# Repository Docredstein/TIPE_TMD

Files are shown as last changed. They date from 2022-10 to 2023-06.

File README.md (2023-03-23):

# TIPE_TMD
TIPE TMD 2022-2023
Ici se trouve le repo de notre TIPE ayant pour thème la ville, si vous êtes aussi en prépa libre à vous de vous inspirer, En cas de besoin vous pouvez envoyer un mail à
mateis. frambourt @laposte.net (sans les espaces) et je ferais de mon mieux pour vous aider. 
preview_hd











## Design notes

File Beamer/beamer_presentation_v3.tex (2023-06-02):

\documentclass{beamer}
\usetheme{Madrid}
\usecolortheme{default}
\usepackage[T1]{fontenc}
\usepackage[french]{babel}
\usepackage{graphicx}
\usepackage{amsmath}
\usepackage{amssymb}
\usepackage{mathrsfs}
\usepackage{subfigure}
\usepackage{empheq}

% Ajouter le plan en haut
\useoutertheme{infolines}
\setbeamertemplate{headline}{
	\begin{beamercolorbox}[ht=2.25ex,dp=3.75ex]{section in head/foot}
		\insertnavigation{\paperwidth}
\end{beamercolorbox}}

\title[]
{Sécurisation de batiment par amortisseur harmonique}

\subtitle{}

\author{FRAMBOURT Mateïs} % (optional, for multiple authors)

\date[N°42185] % (optional)
{Numéro de candidat:\\ 42185}

%\logo{\includegraphics[height=0.8cm]{logo_uoft}}

\definecolor{uoftblue}{RGB}{6,41,88}
\setbeamercolor{titlelike}{bg=uoftblue}
\setbeamerfont{title}{series=\bfseries}
\setbeamertemplate{caption}[numbered]
\begin{document}
	
	\frame{\titlepage}
	%En Binôme avec BOCQUILLON Noé
	\section{Préambule}
	\begin{frame}{Préambule}
		\frametitle{Introduction}

		\begin{columns}[T]
			\begin{column}{0.45\textwidth}
				\begin{figure}
					\centering
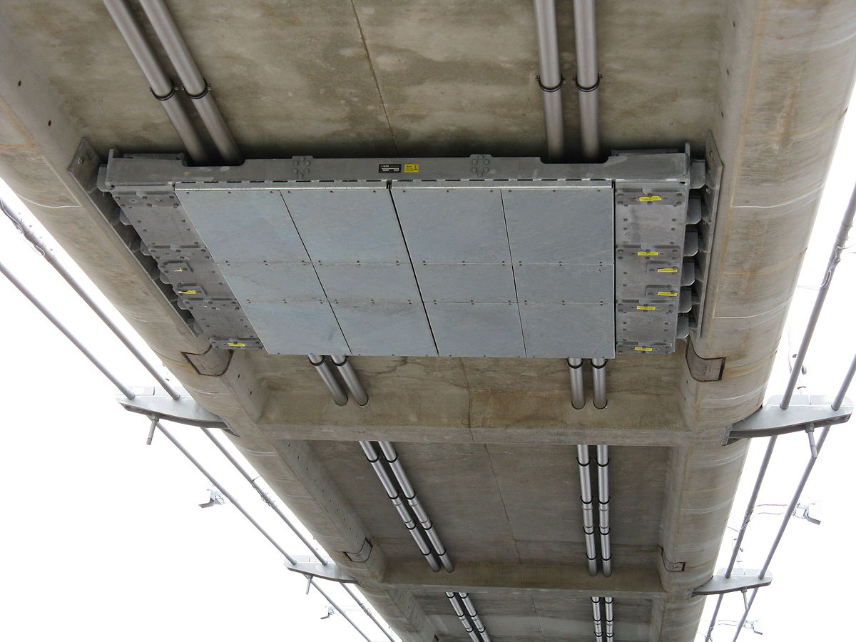
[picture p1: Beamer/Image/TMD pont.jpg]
					
					\caption{Tuned mass damper sur l'Infinity bridge}
				\end{figure}
				
			\end{column}
			\begin{column}{0.45\textwidth}
				\begin{figure}
					\centering
					\caption{ Pendule de la tour Tapei 101 à Taiwan}
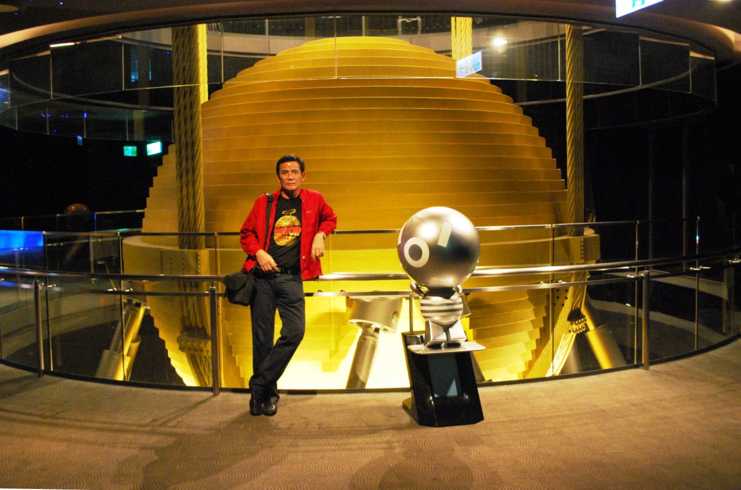
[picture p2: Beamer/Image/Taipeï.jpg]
					
				\end{figure}
			\end{column}
		\end{columns}
		\bigskip\small TMD = Tuned mass damper
	\end{frame}
	
	%\section{First section}
	\begin{frame}{Préambule}
		\frametitle{Objectifs}
		\underline{Problématique:} Quelle est l'influence du TMD sur la stabilité de la tour ? 
		\vspace{12pt}
		\linebreak[3]Objectifs du TIPE:
		\begin{itemize}
			\item Maquettiser un immeuble
			\item Élaborer une excitation sinusoïdale de fréquence paramétrable
			\item Mesurer la position relative de l'immeuble
			
		\end{itemize}
		
	\end{frame}
	
	\begin{frame}{Plan}
		\begin{enumerate}
			\item Modèle théorique
			\item Maquettisation de l'immeuble
			\item Création de l'axe d'excitation
			\item Élaboration de l'ensemble des capteurs
		\end{enumerate}
	\end{frame}
	\section{Théorie}
	\begin{frame}
		\begin{columns}
			\begin{column}{0.5\textwidth}
				\begin{figure}
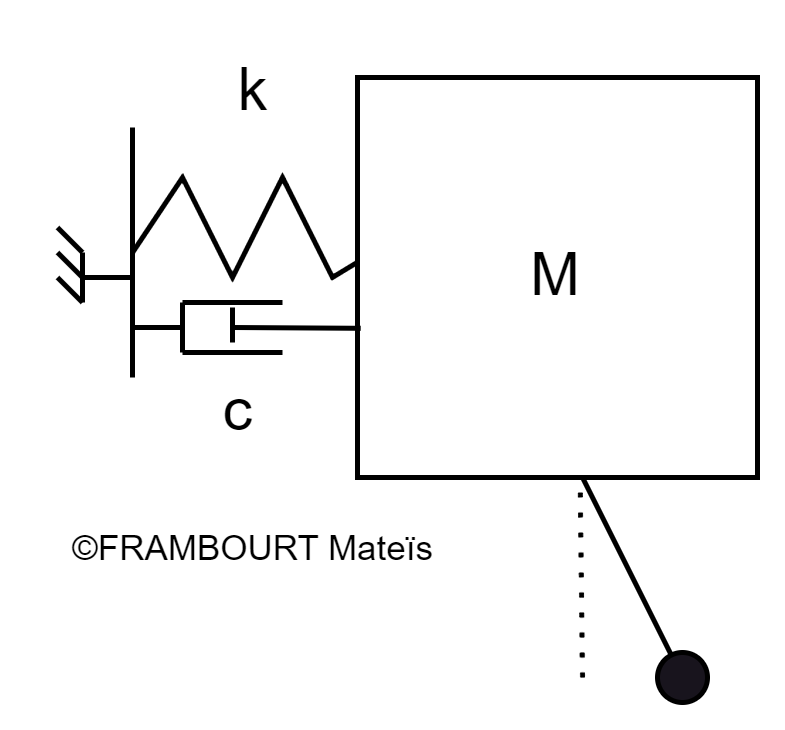
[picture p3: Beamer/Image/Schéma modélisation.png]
					
					\caption{Schéma de la modélisation}
				\end{figure}
			\end{column}
			\begin{column}{0.5\textwidth}
				PDF à la masse : 
				$M\ddot{x} = -kx -c\dot{x} + f(t)$\\
				On a donc sans le pendule : $H=\frac{1}{1+j\frac{c}{k}\omega-\frac{M}{k}\omega^2}$ 
				
			\end{column}
		\end{columns}
	\end{frame}
	\begin{frame}{Élaboration d'un modèle théorique}
		\frametitle{Modélisation du système avec pendule}
		Oscillations linéaires , on peut modéliser le pendule par un système masse ressort
		\begin{columns}
			\begin{column}{0.5\textwidth}
				\begin{figure}
					\centering
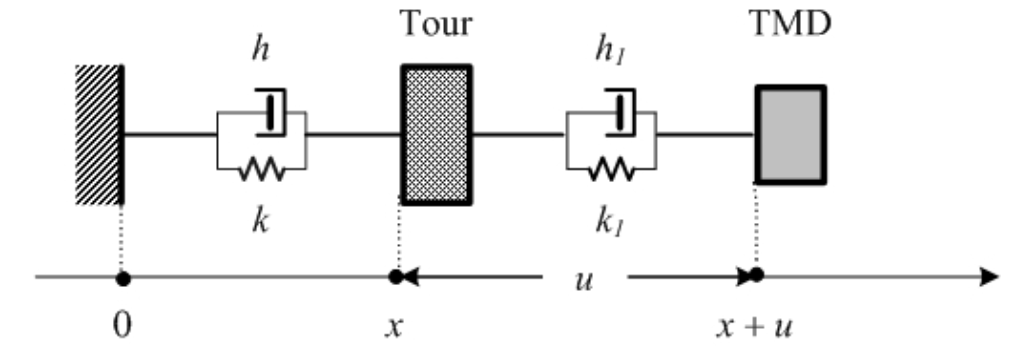
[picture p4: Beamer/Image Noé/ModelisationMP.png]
					
					\caption{Modèle équivalent du système}
				\end{figure}
			\end{column}
			\begin{column}{0.5\textwidth}
				\begin{itemize}
					\item m=Masse du pendule
					\item M=Masse de la tour
					\item $k_{1}$=Coefficient de raideur élastique du pendule
					\item k=Coefficient de raideur élastique (Baguettes + bouchons dans notre modèle)
					\item $h_{1}$= coefficient de frottement du pendule 
					\item h=coefficient de frottement de la tour
				\end{itemize}	
			\end{column}
		\end{columns}
		
	\end{frame}

	\begin{frame}{Équations du système}
		L'excitation extérieure est modélisée par une force $f_{0}(t)$ appliquée à la tour\vspace{12pt}
		PFD à ${tour + TMD}$:
		\begin{equation}\label{key}
			M\ddot{x} + m(\ddot{x}+\ddot{u}) +h\dot{x} + kx = f_{0}(t)
		\end{equation}\\
		\vspace{12pt}
		PFD  au TMD uniquement:
		\begin{equation}
			m(\ddot{x}+\ddot{u}) + h_{1}\dot{u} + k_{1}u = 0
		\end{equation}\\

	\end{frame}
	
	\begin{frame}{Fonctions de transfert du système}
		
	\begin{empheq}[left=\empheqlbrace]{align*}
		H1(\omega)&=\frac{U}{X}= \frac{m\omega^{2}}{k_{1}+jh_{1}\omega-m\omega^{2}}\\
		H2(\omega)&=\frac{X}{\frac{F_{0}}{k}}= \frac{1}{1+j\frac{h}{k}\omega-\frac{(M+m)}{k}\omega^2-\frac{H1(\omega)}{k}\omega^2}
	\end{empheq}
	\vspace{12 pt}
	
	H2 représente le rapport de l'amplitude de l'accélération ressentie par les occupants de  la tour et de l'amplitude de l'accélération extérieure que subit la tour

	\end{frame}
	\section{Maquette} 
	\begin{frame}{Objectif de la Maquettisation}
		\begin{columns}
		\begin{column}{0.3\textwidth}

		\begin{itemize}
			\item Objectif : Obtenir un comportement similaire 
			\item étude de différente solution
		\end{itemize}
	\end{column}
	\begin{column}{0.7\textwidth}
		\begin{figure}
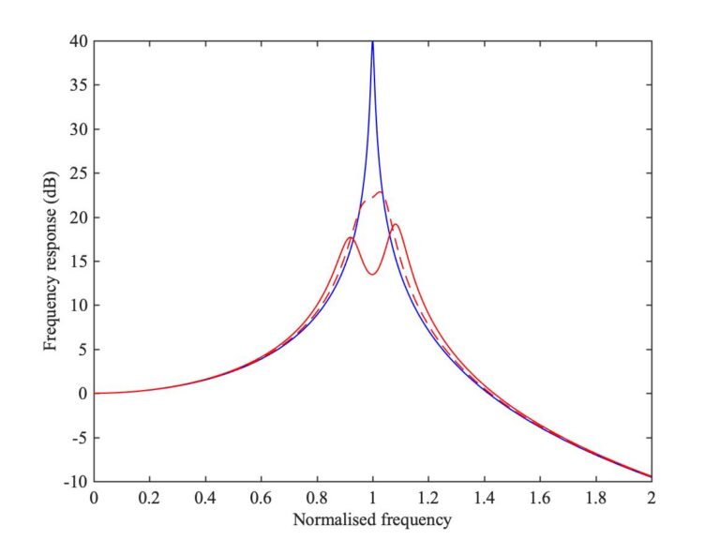
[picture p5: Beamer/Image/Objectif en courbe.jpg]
			
			\caption{\copyright euphonics.org}
		\end{figure}
	\end{column}
	\end{columns}
	\end{frame}
	\begin{frame}{modèle naïf}
		\begin{columns}
			\begin{column}{0.25\textwidth}
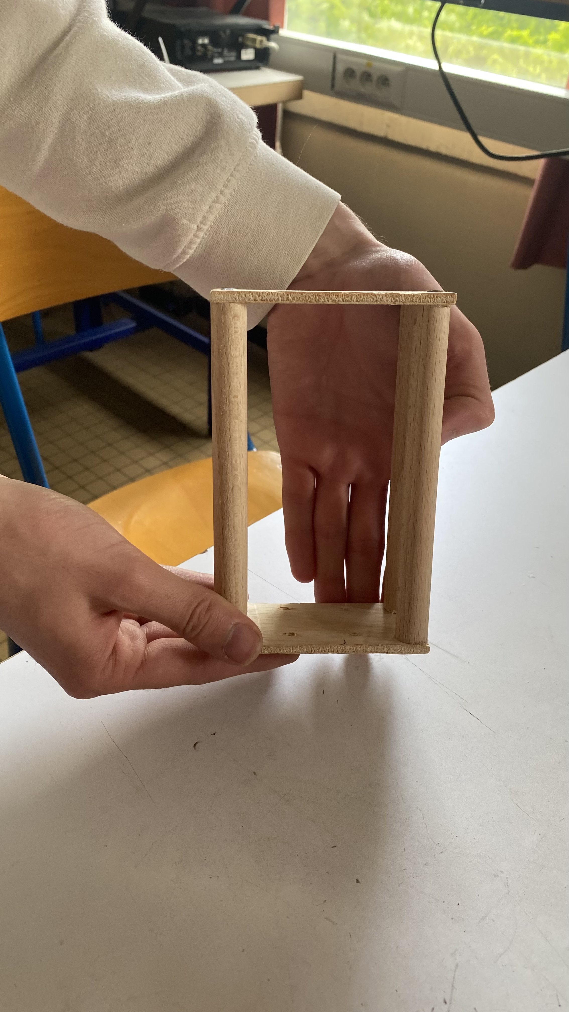
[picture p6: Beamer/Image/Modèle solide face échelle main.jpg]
			
			
		\end{column}
		\begin{column}{0.25\textwidth}
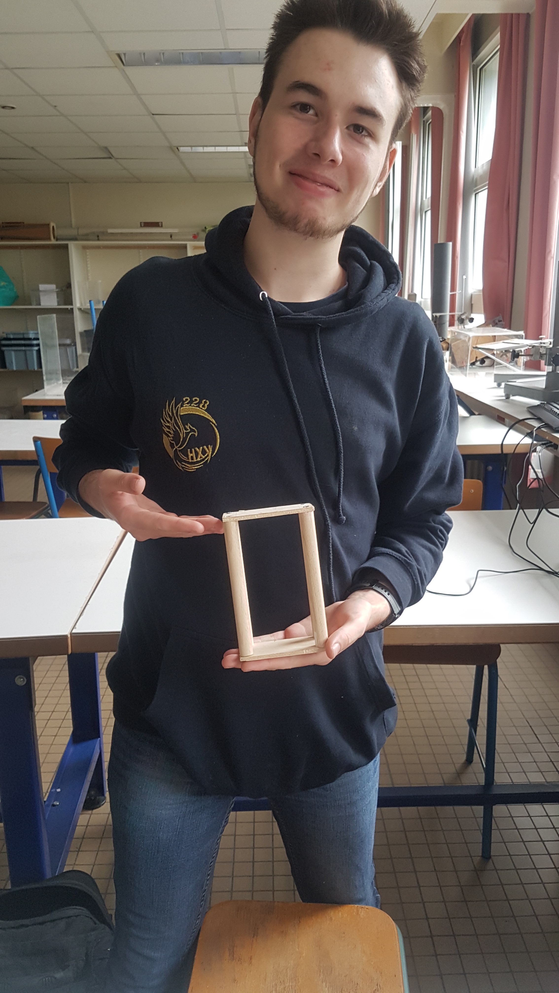
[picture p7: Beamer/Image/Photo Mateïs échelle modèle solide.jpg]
		
			
		\end{column}
		\begin{column}{0.25\textwidth}
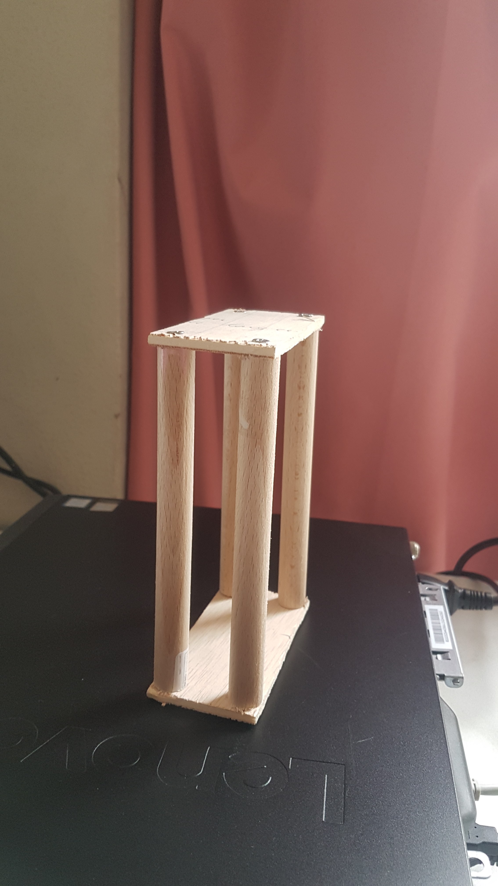
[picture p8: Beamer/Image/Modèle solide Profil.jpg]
		
		
		\end{column}
		\begin{column}{0.25\textwidth}
			\begin{itemize}
				\item Rapide à construire 
				\item trop rigide
			\end{itemize}
		\end{column}
		\end{columns}
		
	\end{frame}
\begin{frame}{Modèle flexible}
	\begin{columns}
		\begin{column}{0.25\textwidth}
			\begin{figure}

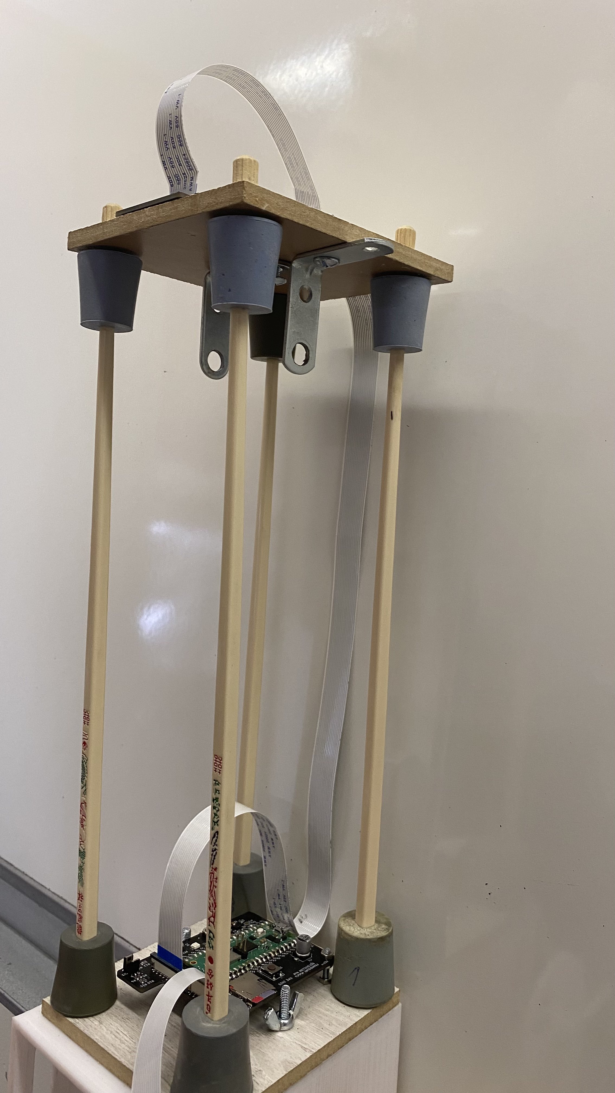
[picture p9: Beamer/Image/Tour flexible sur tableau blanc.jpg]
			
			\caption{Tour flexible}
		\end{figure}
		\end{column}
		\begin{column}{0.75\textwidth}
			\begin{figure}

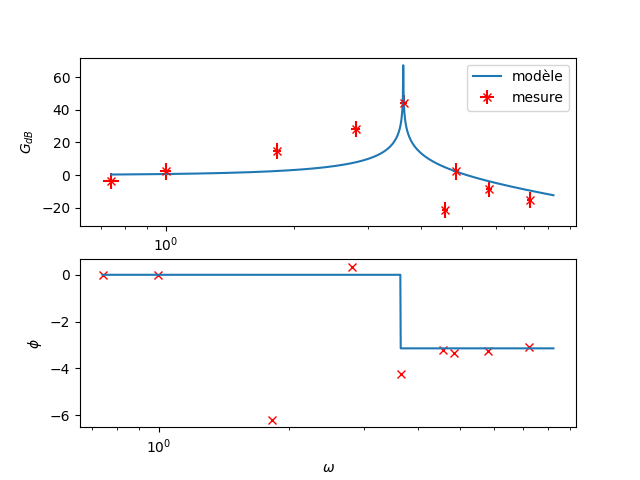
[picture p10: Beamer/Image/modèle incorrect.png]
		
		\caption{Modèle incorrect mais allure bonne}
	\end{figure}	
		\end{column}
	\end{columns}
\end{frame}
\begin{frame}
	\begin{columns}
		\begin{column}{0.3\textwidth}

	Contrainte : 
	\begin{itemize}
		\item Fonctionnement linéaire 
		\item Résonance dans l'intervalle [0.5,7Hz]
		\item facilement modifiable
	\end{itemize}
\end{column}
\begin{column}{0.3\textwidth}
	Limite imposée : 
	\begin{itemize}
		\item faible amplitude d'oscillations
		\item surface minimale
	\end{itemize}

\end{column}
\begin{column}{0.3\textwidth}
	\begin{figure}
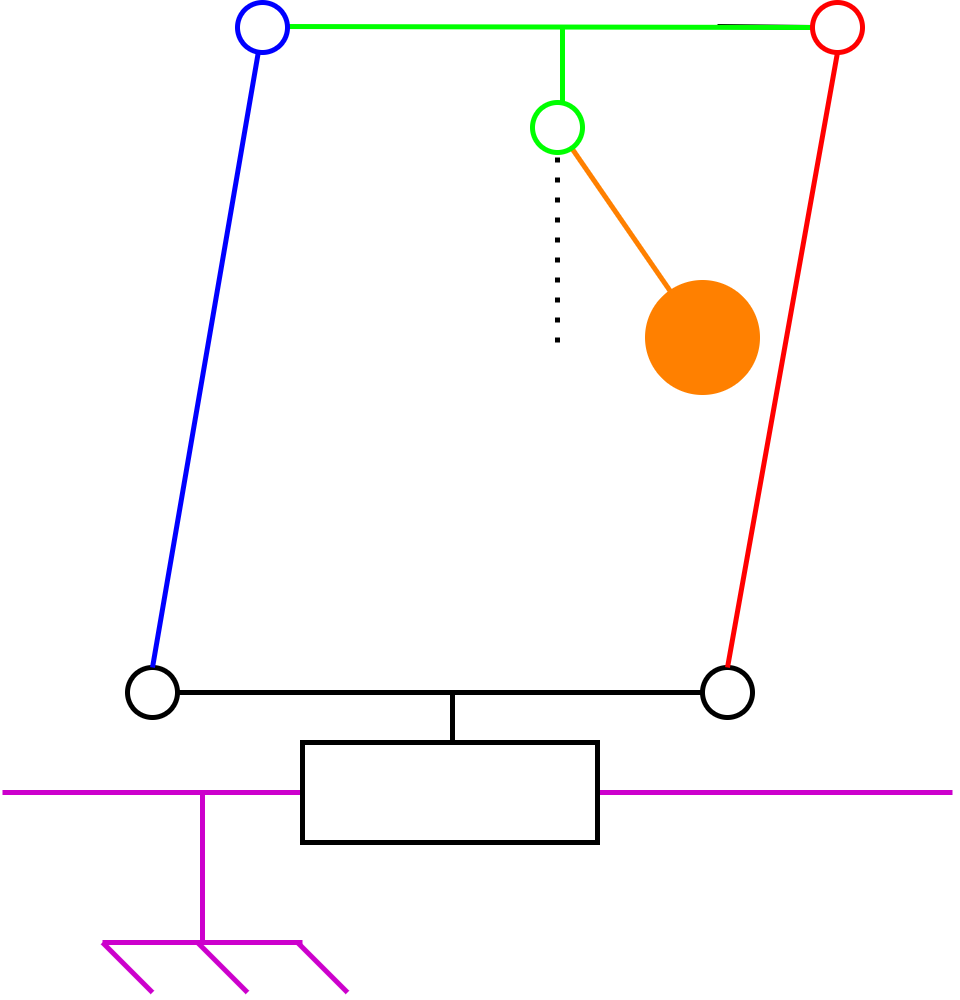
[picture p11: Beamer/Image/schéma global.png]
		
		\caption{Schéma global}
	\end{figure}
\end{column}
\end{columns}
\end{frame}
\begin{frame}{problème de non-linéarité}
	\begin{columns}
		\begin{column}{0.35\textwidth}
			\begin{figure}

			
			\caption{Problème de torsion}
		\end{figure}
		\end{column}
		\begin{column}{0.35\textwidth}
			\begin{figure}
				
				\caption{Cause de la torsion}
			\end{figure}
		\end{column}
	\end{columns}
\end{frame}
\begin{frame}{Pendule réglable}
	\begin{columns}
		
	\begin{column}{0.35\textwidth}

	\begin{figure}
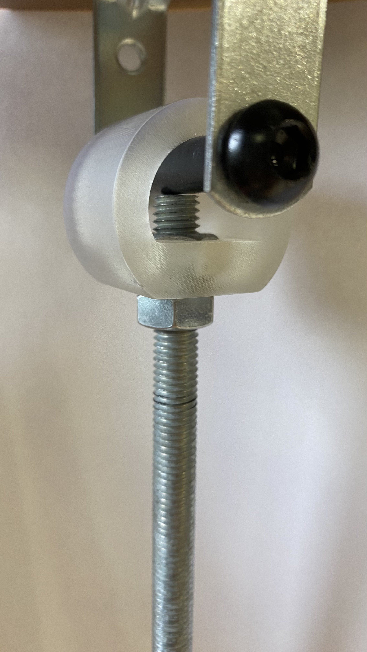
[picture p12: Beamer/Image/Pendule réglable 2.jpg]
		
		\caption{Pendule à tige filetée}
	\end{figure}
\end{column}
\begin{column}{0.65\textwidth}
	Contrainte : 
	\begin{itemize}
		\item Minimum de frottement
		\item Centre de gravité réglable
		\item masse réglable
	\end{itemize}
\end{column}
\end{columns}
\end{frame}
\section{Mise en vibration de la maquette}

	\begin{frame}{Guidage}
		\frametitle{Premier guidage}
 
		\begin{columns}
			\begin{column}{0.5\textwidth}
				\begin{figure}
					
					\caption{Guidage récupéré d'un ancien TIPE}
				\end{figure}
			\end{column}
			\begin{column}{0.5\textwidth}
				Avantages:
				\begin{itemize}
					\item Déjà construit
				\end{itemize}
				\vspace{12pt}
				Inconvénients:
				
				\begin{itemize}
					\item Hystérésis
					\item Frottement non négligeable
					\item Asservissement à réaliser
				\end{itemize}
			\end{column}
		\end{columns}
	\end{frame}
	\begin{frame}{Guidage récupéré}
		\begin{columns}[T]
			\begin{column}{0.8\textwidth}
				\begin{figure}
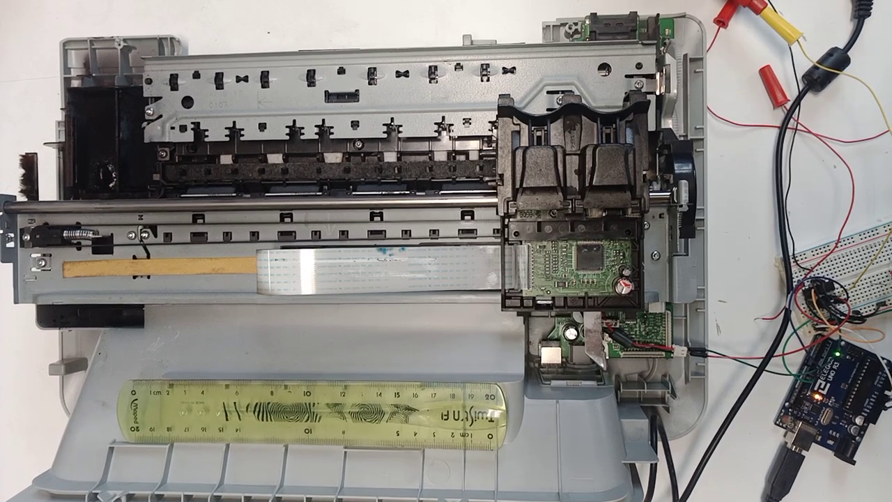
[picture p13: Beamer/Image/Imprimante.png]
					
					\caption{Axe d'une imprimante jets d'encre}
				\end{figure}
			\end{column}
		\end{columns}
	\end{frame}
		\begin{frame}
			\begin{columns}
				\begin{column}{0.5\textwidth} 
				\begin{figure}
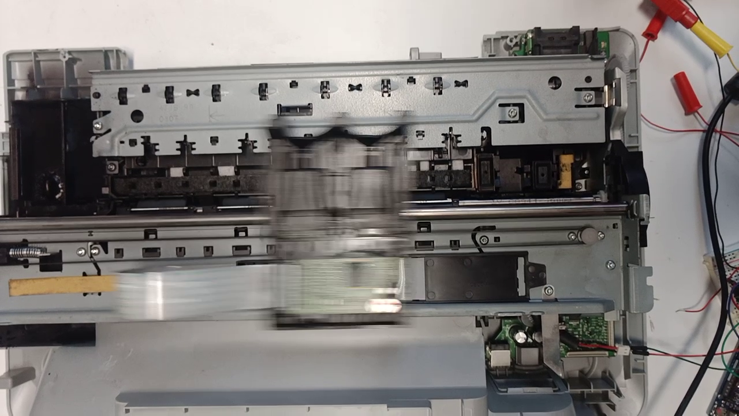
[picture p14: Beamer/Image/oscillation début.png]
					
					\caption{début des oscillations}
				\end{figure}

			\end{column}
			\begin{column}{0.5\textwidth} 
				\begin{figure}
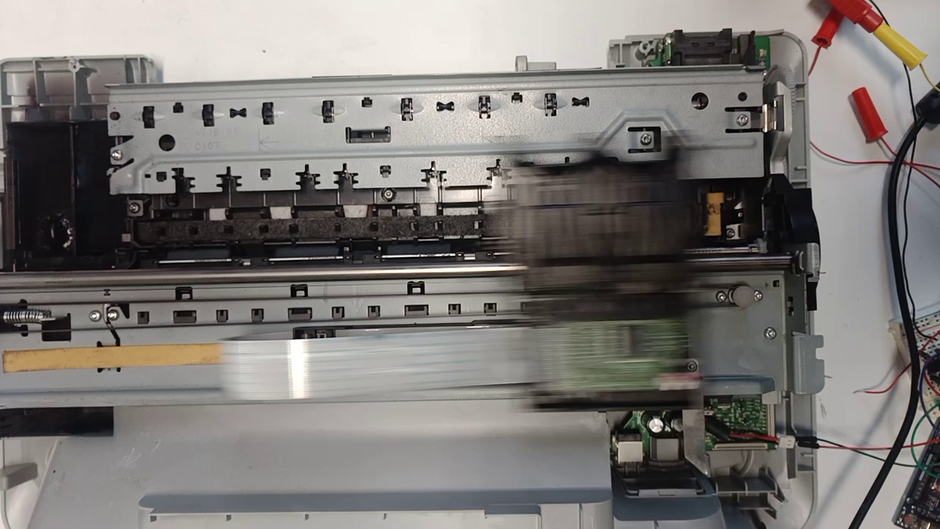
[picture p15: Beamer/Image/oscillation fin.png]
					
					\caption{fin des oscillations}
				\end{figure}
				
			\end{column}
		\end{columns}
	\end{frame}
	\begin{frame}{solution à ces problème}
		\begin{columns}
			\begin{column}{0.3\textwidth}
				\begin{figure}
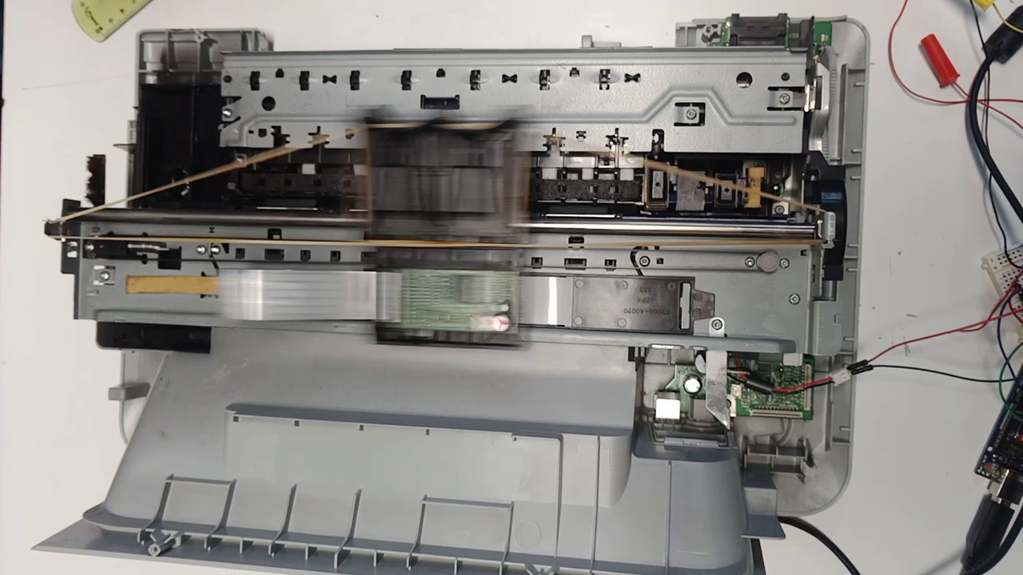
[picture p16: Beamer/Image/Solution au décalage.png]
					
					\caption{Solution au décalage}
				\end{figure}
			\end{column}
			\begin{column}{0.3\textwidth}
				\begin{figure}
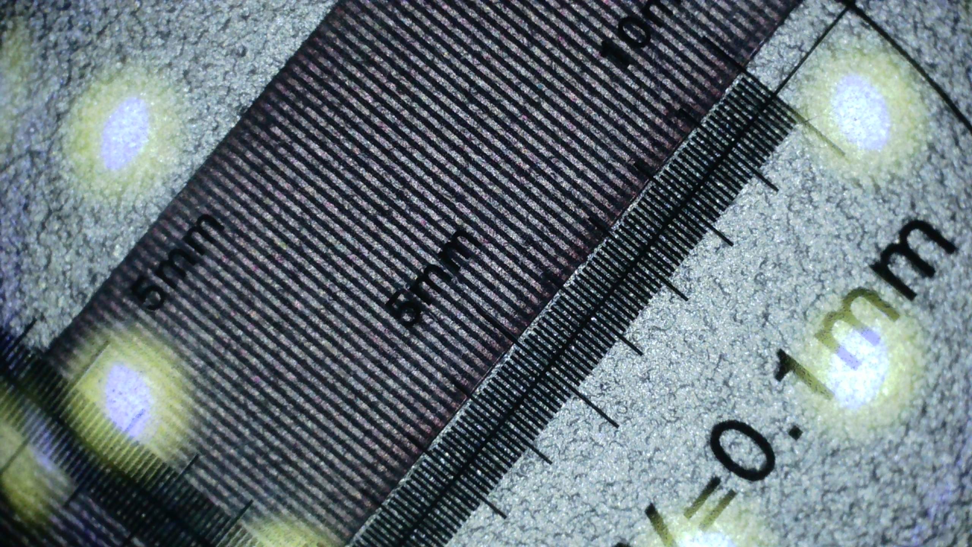
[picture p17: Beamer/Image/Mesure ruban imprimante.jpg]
					
					\caption{Mesure du ruban zébré de l'imprimante}
				\end{figure}
				$d=0.2\pm0.05mm$
			\end{column}
			\begin{column}{0.3\textwidth}
				\begin{figure}

					
					\caption{Tentative de récupération du capteur}
				\end{figure}
			\end{column}
		\end{columns}
		
	\end{frame}
	\begin{frame}{Conclusion sur cet axe}
		\begin{columns}
			\begin{column}{0.5\textwidth}
				Avantages : 
				\begin{itemize}
					\item Gratuit
					\item Solution mécanique déjà construite
				\end{itemize}
			\end{column}
			\begin{column}{0.5\textwidth}
				Inconvénients : 
				\begin{itemize}
					\item Asservissement à réaliser
					\item Dépendance entre la charge et le déplacement
					\item Moteur faible
				\end{itemize}
			\end{column}
		\end{columns}
	\end{frame}
\begin{frame}{Axe imprimé en 3D}
	\begin{columns}
		\begin{column}{0.5\textwidth}
			\begin{figure}
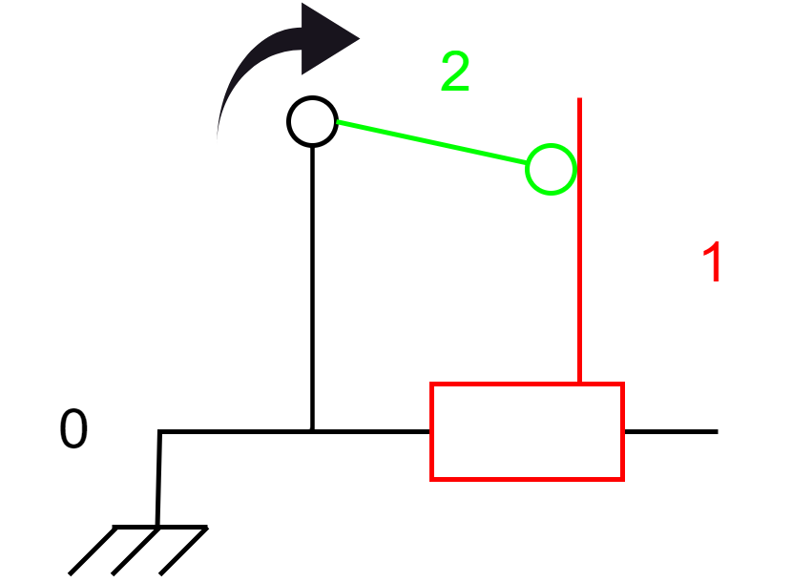
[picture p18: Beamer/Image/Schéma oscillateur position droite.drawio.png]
				
				\caption{Schéma cinématique de l'axe}
			\end{figure}
		\end{column}
		\begin{column}{0.5\textwidth}
			\begin{figure}
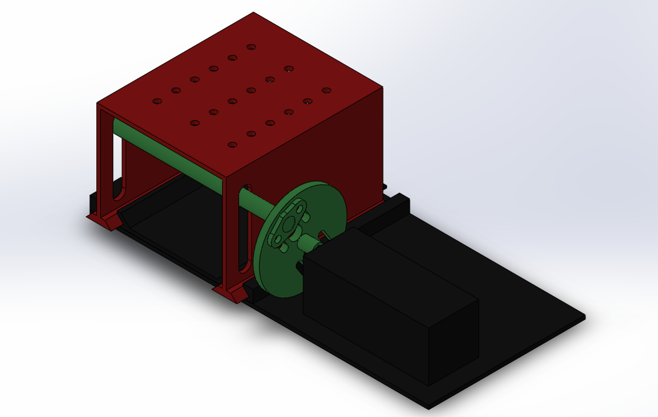
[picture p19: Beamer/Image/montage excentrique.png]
				
				\caption{Montage sur Solidwork}
			\end{figure}
		\end{column}
	\end{columns}
\end{frame}
\begin{frame}{Hystérésis}
	\begin{columns}
		\begin{column}{0.5\textwidth}
			\begin{figure}
				
				\caption{Schéma cinématique de l'axe à droite}
			\end{figure}
		\end{column}
		\begin{column}{0.5\textwidth}
			\begin{figure}
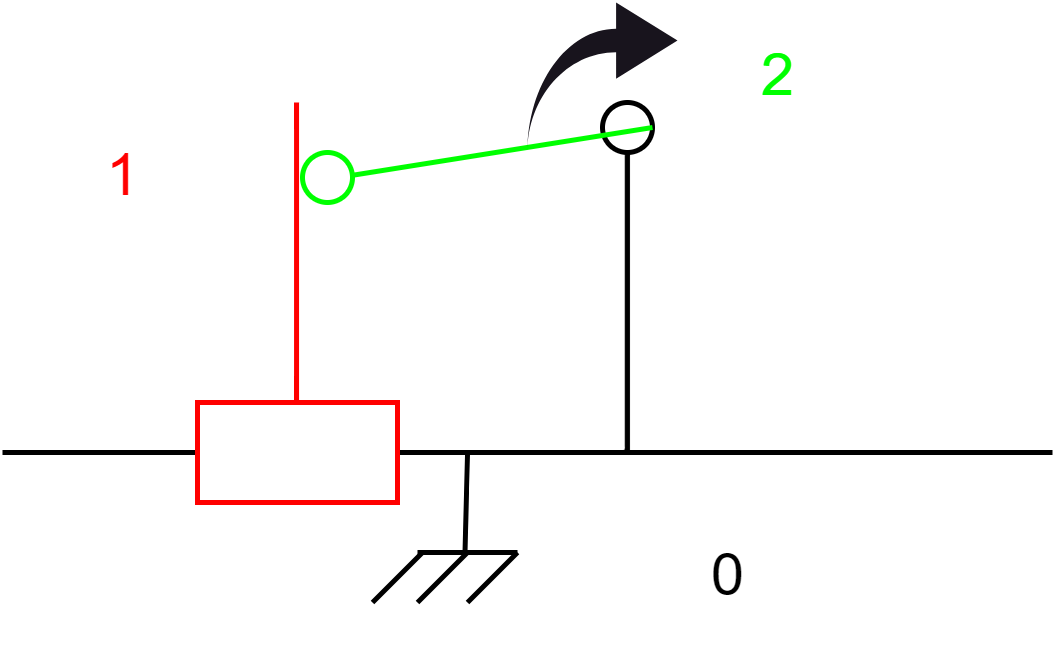
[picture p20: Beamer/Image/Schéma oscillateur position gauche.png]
				
				\caption{Schéma à gauche}
			\end{figure}
		\end{column}
	\end{columns}
\end{frame}
\begin{frame}{Conclusion sur cet axe}
	\begin{columns}
		\begin{column}{0.3\textwidth}
			Avantages : 
			\begin{itemize}
				\item Modulaire
				\item Précise sans Asservissement
				\item facilement rêglable en fréquence
			\end{itemize}
		\end{column}
		\begin{column}{0.3\textwidth}
			Inconvénients : 
			\begin{itemize}
				\item Pièce fragile à l'usure
				\item Plateforme limité en taille
				\item Hystérésis
			\end{itemize}
			
		\end{column}
		\begin{column}{0.3\textwidth}
			\begin{figure}
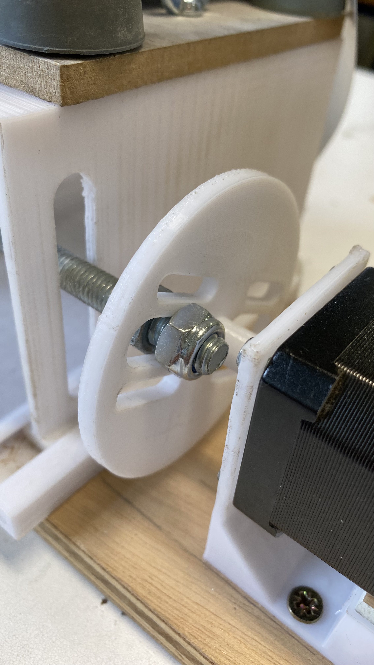
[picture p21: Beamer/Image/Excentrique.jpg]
				
				\caption{Réalisation pratique}
			\end{figure}
		\end{column}
	\end{columns}
\end{frame}
	\begin{frame}{Capteurs}
		
		%schéma de la maquette avec des 2 accéléromètres
		
		\begin{columns}
			\begin{column}{0.35\textwidth}
				\begin{figure}
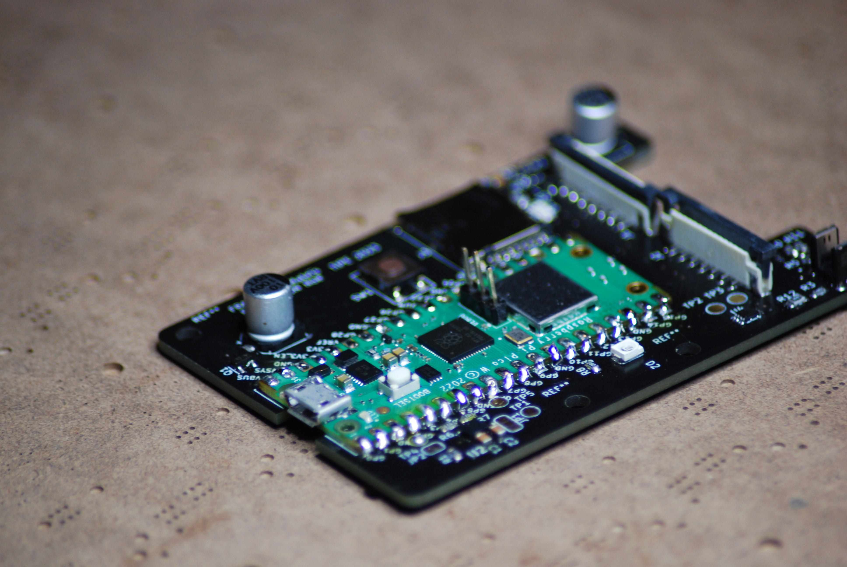
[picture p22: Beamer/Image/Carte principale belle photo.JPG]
					
					\caption{Accéléromètre du socle}
				\end{figure}
			\end{column}
			\begin{column}{0.35\textwidth}
				\begin{figure}
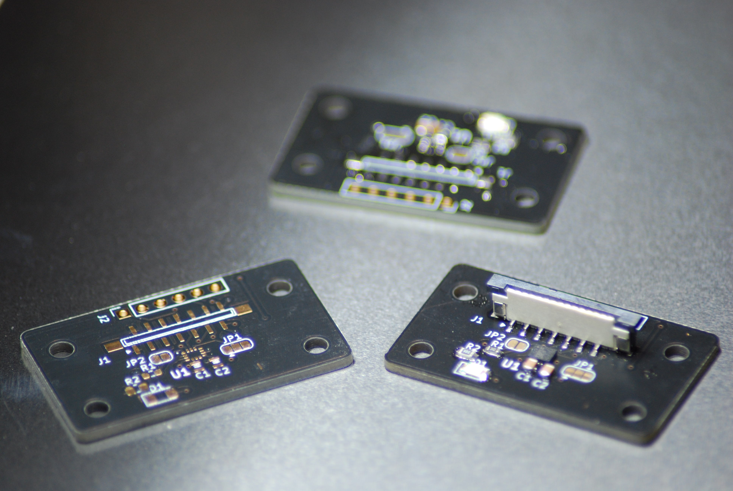
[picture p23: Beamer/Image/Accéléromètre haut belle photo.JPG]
					
					\caption{Accéléromètre du haut}
				\end{figure}
			\end{column}
			\begin{column}{0.35\textwidth}
				\begin{figure}
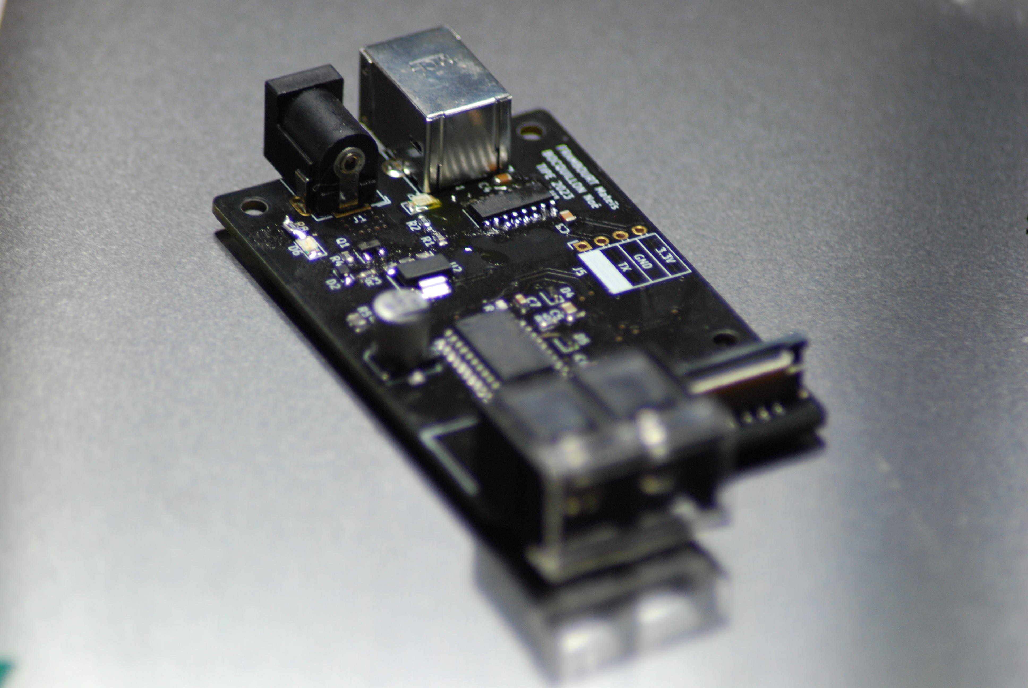
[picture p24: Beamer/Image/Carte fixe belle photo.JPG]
					
					\caption{Carte fixe}
				\end{figure}
			\end{column}
		\end{columns}
	
	\end{frame}

	\begin{frame}
		Pour les réponses sinusoïdales : 
		\begin{itemize}
			\item Amplitude minimale
			\item Fréquence entre [0.5;5Hz]
			\item Mesure en régime établit 
		\end{itemize}
	\end{frame}
	
	\begin{frame}{Mise en vibration de la maquette}
		\frametitle{Première expérience:Réponse à une excitation sinusoïdale}
		\centering
		\begin{figure}

		
	\caption{Réponse du système à une excitation sinusoïdale pour une masse de 100g à 9.4 cm }
	\end{figure}
\end{frame}
	\begin{frame}
		
		Observations:
		\begin{itemize}
			\item Réduction de l'amplitude des oscillations
			\item Influence du centre de gravité du pendule
			\item Décalage de la fréquence de résonance  
		\end{itemize}
		
	\end{frame}
	
	\begin{frame}{}
		\begin{figure}
			
		\end{figure}
	\end{frame}	

	\begin{frame}{Mise en vibration de la maquette}
		\frametitle{Première expérience:Réponse à une excitation sinusoïdale}	
		\centering
		\begin{figure}
			
			\caption{Même réponse en montant la masse à 5cm}
		\end{figure}
			
		\centering
		\begin{figure}
			
			\caption{cette fois çi en prennant 73.3g à 9.4cm}
		\end{figure}

	\end{frame}

	\begin{frame}{Mise en vibration de la maquette}
		\frametitle{Deuxième expérience:Dirac}
		\subtitle{bjr}
		\begin{columns}
			\begin{column}{0.5\textwidth}
				\alert{Simulation d'une rafale de vent}
				\begin{figure}
					
					\caption{Excitation brève}
				\end{figure}
			\end{column}
			\begin{column}{0.5\textwidth}
				Conditions de l'expérience :
				\begin{itemize}
					\item Dirac avec un ressort 
					\item Oscillations dans un seul plan
				\end{itemize}	
			\end{column}
		\end{columns}
	\end{frame}

	\begin{frame}{Mise en vibration de la maquette}
		\frametitle{Deuxième expérience:Réponse à une excitation brève}
		\centering Résultats
		\vspace{12pt}
		\begin{columns}[onlytextwidth]
			\begin{column}{1\textwidth}
				\centering
				\begin{figure}
					
					\caption{Réponse temporelle à un Dirac}
				\end{figure}
				
			\end{column}
		\end{columns}
		\footnote{A modifier}
	\end{frame}

%	\begin{frame}
	%	contenu...
	
%	$	Mesure de T et de C_{1} expérimentalement :\\ Obtention de la valeur de K$
%	\end{frame}

	\section{Conclusion}
	
	\begin{frame}{Limites du modèle}
		\begin{itemize}
			\item Dimensions peu assimilables au réel
			\item Élasticité trop importante 
			\item Cependant Résultats comparable au réel.
		\end{itemize}	
		\vspace{12pt}
		
	\end{frame}
	
	%\begin{frame}{explications}
	%dissipation d'énergie dans le pendule , opposition de phases , rapport des pulsations naturelles
	%\end{frame}
	
	%\begin{frame}{limites}
	%	dimension peu adaptées (rapport de la taille et de la masse du pendule par rapport à la structure\\structure trop élastique qui entraine parfois des non linéarité à la fréquence de résonance )
	%\end{frame}
	
	%\begin{frame}{ce qu'on aurait aimé faire}
	%comparaison avec un modèle informatique\\
	%	plus de variations de paramètres\\
	%	mettre le pendule dans un fluide pour plus de viscosité
	%\end{frame}

	%\begin{frame}
	%	\frametitle{Annexe}
	%	Graphique et explication des mesures des coefficients de raideur
	%\end{frame}

	\appendix
	\section*{Annexe}
	\begin{frame}{Caractéristique des TMD en introduction}
		\begin{columns}

		\begin{column}{0.5\textwidth}

		\begin{figure}
			
			\caption{\copyright supertalls.fr} 
		\end{figure}
	\end{column}
	\begin{column}{0.5\textwidth}
		\begin{itemize}
			\item Masse: 660 Tonnes
			\item diamètre: 5,5m
			\item amplitude maximale : 1,5m 
			\item amortissement: jusqu'à 40\% maximum
			\item prix : 4 millions de dollars
		\end{itemize}
	\end{column}

\end{columns}
	\end{frame}

	\begin{frame}{Caractéristique des TMD en introduction}
		\begin{columns}
			\begin{column}{0.5\textwidth}
				\begin{figure}
					
					\caption{\copyright JohnYeadon}
				\end{figure}
			\end{column}
			\begin{column}{0.5\textwidth}
				\begin{itemize}
					\item Localisation : Stockton-on-Tees
					\item Masse : 700 Kg
					\item Nombre : 7 sur l'entiereté du pont
				\end{itemize}
			\end{column}
			
		\end{columns}
	\end{frame}
	\begin{frame}{Accéléromètre utilisé}
		\begin{columns}
			\begin{column}{0.5\textwidth}
				\begin{figure}
					
					\caption{\copyright www.mems-exchange.org}
				\end{figure}
			\end{column}
			\begin{column}{0.5\textwidth}
				\begin{itemize}
					\item LSM6DS3
					\item 6 degré de liberté 
					\item $\pm 2$/$\pm 16$ g
					\item $U(a)=0.122$ mg 
					\item $N(a) = 90 \frac{\mu g}{\sqrt{Hz}}$ 
				\end{itemize}
			\end{column}
			
		\end{columns}
	\end{frame}
	\begin{frame}{Caractéristique du raspberry pi pico W} 
		\begin{columns}
			\begin{column}{0.5\textwidth}
				\begin{figure}
					
					\caption{Pico W}
				\end{figure}
			\end{column}
			\begin{column}{0.5\textwidth}
				\begin{itemize}
					\item Programmable en C++/Python 
					\item 15€ 
					\item 2 Coeurs M0+ 133 MHz 
					\item FPU integré
					\item Wifi 2.4 GHz
				\end{itemize}
			\end{column}
		\end{columns}
		
	\end{frame}
	\begin{frame}{Circuit imprimé fixe}
		\begin{columns}
			\begin{column}{0.5\textwidth}
				\begin{figure}
					
					\caption{branchement base fixe}
				\end{figure}
			\end{column}
			\begin{column}{0.5\textwidth}
				\begin{figure}
					
					\caption{PCB base fixe}
				\end{figure}
			\end{column}
		\end{columns}
	\end{frame}
	\begin{frame}{Circuit imprimé principal}
		\begin{columns}
			\begin{column}{0.5\textwidth}
				\begin{figure}
					
					\caption{Branchement Carte mère }
				\end{figure}
			\end{column}
			\begin{column}{0.5\textwidth}
				\begin{figure}
					
					\caption{Capteur de la carte mère}
				\end{figure}
			\end{column}
		\end{columns}
	\end{frame}
	\begin{frame}{Schéma PCB}
		\begin{figure}
			
			\caption{PCB carte mère}
		\end{figure}
	\end{frame}
\end{document}

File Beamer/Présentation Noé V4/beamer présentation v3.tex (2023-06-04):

\documentclass{beamer}
\usetheme{Madrid}
\usecolortheme{default}
\usepackage[T1]{fontenc}
\usepackage[french]{babel}
\usepackage{graphicx}
\usepackage{amsmath}
\usepackage{amssymb}
\usepackage{mathrsfs}
\usepackage{xcolor}
\usepackage{empheq}

% Ajouter le plan en haut
\useoutertheme{infolines}
\setbeamertemplate{headline}{
	\begin{beamercolorbox}[ht=2.25ex,dp=3.75ex]{section in head/foot}
		\insertnavigation{\paperwidth}
\end{beamercolorbox}}

\title[]
{Atténuation des vibrations grâce à
	un amortisseur harmonique passif}

\subtitle{}

\author{Noé Bocquillon} 

\date[n°20041] % (optional)
{Numéro de candidat:\\ 20041}

%\logo{\includegraphics[height=0.8cm]{logo_uoft}}

\definecolor{uoftblue}{RGB}{6,41,88}
\setbeamercolor{titlelike}{bg=uoftblue}
\setbeamerfont{title}{series=\bfseries}
\setbeamertemplate{caption}[numbered]
\begin{document}
	
	\frame{\titlepage}
	\section{Préambule}
	\begin{frame}{Préambule}
		\frametitle{Introduction}

		\begin{columns}[T]
			\begin{column}{0.46\textwidth}
				\begin{figure}
					\centering
					
					\caption{Tuned mass damper sur le millennium bridge à Londres}
				
				\end{figure}

			\end{column}
			\footnote{\tiny https://www.structuresinsider.com/post/why-the-millennium-bridge-experienced-unexpected-swaying}
			
			\begin{column}{0.46\textwidth}
				\begin{figure}
					\centering
					\caption{ Pendule de la tour Taipei 101 à Taiwan}					
			
					
				\end{figure}

			\end{column}
			\footnote{\tiny https://www.constructconnect.com/blog/engineering-giants-how-megatall-skycrapers-are-built}
		\end{columns}
		\bigskip\small TMD = Tuned mass damper

	\end{frame}
	
	%\section{First section}
	\begin{frame}{Préambule}
		\frametitle{Objectifs}
		\underline{Problématique:} Quelle est l'influence du Tuned Mass Damper lors d'une excitation extérieure ? 
		\vspace{12pt}
		\linebreak[3]Objectifs du TIPE:
		\begin{itemize}
			\item\ Modéliser un immeuble subissant une contrainte extérieure
			\item Étudier l'influence du TMD et de ses paramètres sur l'atténuation des vibrations de la maquette
			
		\end{itemize}
		
	\end{frame}
	
	\begin{frame}{Plan}
		\begin{enumerate}
			\item\huge{Construction de la maquette et développement de l'outil de vibration} \linebreak
			\item Élaboration d'un modèle théorique \linebreak
			\item Mise en vibration de la maquette
 
		\end{enumerate}
	\end{frame}
	
	\section{Construction de la maquette}
	\begin{frame}{Construction de la maquette}
		\begin{columns}
			\begin{column}{0.5\textwidth}
				\begin{figure}
					
					\caption{Montage global}
				\end{figure}
			
			\end{column}
			\begin{column}{0.5\textwidth}
			
			\begin{figure}
				
				\caption{Maquette de l'immeuble}
			\end{figure}
			\end{column}
	
	%	\begin{column}{0.2\textwidth}
	%			Contraintes:
	%	\begin{itemize}
	%		\item Taille
	%		\item Flexibilité \\
	%	\end{itemize}
	%	\end{column}
	\end{columns}
\centering	Contraintes: Taille et flexibilité

	\end{frame}

	\begin{frame}{Construction de la maquette}
		\frametitle{Pendule}

		\begin{columns}
			\begin{column}{0,5\textwidth}
				\begin{figure}
					
					\caption{Pendule}
				\end{figure}
			\end{column}
		\begin{column}{0.5\textwidth}
					Pivot d'axe avec longueur réglable\vspace{24pt}
			Contraintes:
			\begin{itemize}
				\item Masse réglable
				\item Centre de gravité réglable
				\item Oscillations dans un seul plan
			\end{itemize}
		\end{column}
		\end{columns}
	\end{frame}

\begin{frame}{Construction de la maquette}
		\frametitle{Outil de mise en vibration}
		\begin{columns}
			\begin{column}{0.5\textwidth}
				\begin{figure}
					
					\caption{Guidage en translation d'une imprimante}
				\end{figure}
			\end{column}
			\begin{column}{0.5\textwidth}
				Inconvénients:
				\begin{itemize}
					\item Fréquence non réglable \\
					\item Difficultés pour fixer la structure
					
					\item Masse de la structure qui influe sur la vitesse
				\end{itemize}

			\end{column}
		\end{columns}
	\end{frame}

	\begin{frame}{Construction de la maquette}
		\frametitle{Outil de mise en vibration}
 
		\begin{columns}
			\begin{column}{0.5\textwidth}
				\begin{figure}
					
					\caption{Mécanisme}
				\end{figure}
			\end{column}
			\begin{column}{0.5\textwidth}
				Avantages:
				\begin{itemize}
					\item\ Facilité pour fixer la structure
					\item Fréquence réglable \\
					\item Amplitude réglable 
				\end{itemize}
				\vspace{12pt}
				Inconvénients:
				
				\begin{itemize}
					\item Hystérésis
				\end{itemize}
			\end{column}
		\end{columns}
	\end{frame}

\begin{frame}{Outil de mise en vibration}
	\begin{figure}
		
		\caption{Schéma cinématique de l'outil de vibration}
	\end{figure}
\end{frame}

	\begin{frame}{Mise en vibration de la maquette}
	
	%schéma de la maquette avec des 2 accéléromètres
	\frametitle{Capteurs}
	\begin{columns}
		\begin{column}{0.25\textwidth}
			\begin{figure}
				
				\caption{Accéléromètre sur le socle}
			\end{figure}
		\end{column}
		\begin{column}{0.5\textwidth}
			\begin{figure}
				
				\caption{Accéléromètre sur le toit}
			\end{figure}
		\end{column}
	\end{columns}
\end{frame}

\begin{frame}{Schéma de la maquette}
	\begin{figure}
		
		\caption{Schéma 2D du montage global}
	\end{figure}
\end{frame}
	
\section{Élaboration du modèle théorique}

\begin{frame}{Détermination du modèle théorique}
 Modélisation de la maquette sans pendule:\vspace{12 pt}
	\begin{columns}
		\begin{column}{0.5\textwidth}
			\begin{figure}
				
				\caption{Modélisation sans pendule}
			\end{figure}
		\end{column}
		\begin{column}{0.6\textwidth}
			PFD à la tour:
			\begin{equation*}
				M\ddot{x} = -kx -h\dot{x} + f(t)
			\end{equation*}
			Ce qui donne la fonction de transfert : 
			$H(\omega)=\frac{X}{\frac{F}{k}}=\frac{1}{1+j*\frac{h}{k}*\omega-\frac{M}{k}*\omega^{2}}$
		\end{column}
	\end{columns}
\end{frame}	

\begin{frame}{Élaboration d'un modèle théorique}
	\frametitle{Modélisation du système avec pendule}
	\begin{columns}
		\begin{column}{0.5\textwidth}
			\begin{figure}
				\centering
				
				\caption{Modèle équivalent du système}
			\end{figure}
		\footnote{\tiny Schéma provenant du sujet Mines-Ponts Physique 2 MP 2007}
		\end{column}
		\begin{column}{0.5\textwidth}
			\begin{itemize}
				\item m=Masse équivalente du pendule
				\item M=Masse équivalente de la tour
				\item $k_{1}$=Coefficient de raideur élastique du pendule
				\item k=Coefficient de raideur élastique (Tiges + bouchons dans notre modèle)
				\item $h_{1}$= coefficient de frottement du pendule 
				\item h=coefficient de frottement de la tour
			\end{itemize}	
		\end{column}
	\end{columns}
	
\end{frame}

%\begin{frame}{Modélisation du système avec pendule}
	%PFD à la tour sans pendule ni excitation extérieure (Correspond au Dirac): 
%	\begin{equation}\label{key}
	%	\ddot{x} + \frac{h}{M}\dot{x}  + \frac{K}{M}x = 0
%	\end{equation}\vspace{24pt}
%	Période naturelle de la tour:$ T = 2\pi\frac{1}{\sqrt{\frac{K}{M}-\frac{h}{4M^2}}}$\\
%	\vspace{12 pt}
%	Mesure de T et de h expérimentalement :\\ Obtention de la valeur de K
%\end{frame}

\begin{frame}{Élaboration d'un modèle théorique}
	\frametitle{Équations du système}	
	L'excitation extérieure est modélisée par une force $f_{0}(t)$ appliquée à la tour\vspace{12pt}
	PFD à ${tour + TMD}$:
	\begin{equation}\label{key}
		M\ddot{x} + m(\ddot{x}+\ddot{u}) +h\dot{x} + kx = f_{0}(t)
	\end{equation}\\
	\vspace{12pt}
	PFD  au TMD uniquement:
	\begin{equation}
		m(\ddot{x}+\ddot{u}) + h_{1}\dot{u} + k_{1}u = 0
	\end{equation}\\

\end{frame}

\begin{frame}{Fonctions de transfert du système}
	
\begin{empheq}[left=\empheqlbrace]{align*}
	H1(\omega)&=\frac{U}{X}= \frac{m\omega^{2}}{k_{1}+jh_{1}\omega-m\omega^{2}}\\
	H2(\omega)&=\frac{X}{\frac{F_{0}}{k}}= \frac{1}{1+j\frac{h}{k}\omega-\frac{(M+m)}{k}\omega^2-\frac{H1(\omega)}{k}\omega^2}
\end{empheq}
\vspace{12 pt}

\end{frame}
\section{Mise en vibration de la maquette}

\begin{frame}{Mise en vibration de la maquette}
	\frametitle{Première expérience:Réponse à une excitation sinusoïdale}
	\begin{columns}
		\begin{column}{0.35\textwidth}
			\alert{Simulation d'un séisme}
		\end{column}
		\begin{column}{0.6\textwidth}
			Conditions de l'expérience :
			\begin{itemize}
				\item Excentration la plus faible 
				\item Oscillations dans un seul plan
				\item Plage de fréquences :[0.5 hz;4 hz]
			\end{itemize}	
		\end{column}
	\end{columns}

	\begin{figure}
		
		
	\end{figure}

\end{frame}

	\begin{frame}{Première expérience:Réponse à une excitation sinusoïdale}
	Changement de la longueur du pendule:

		\begin{figure}
		\centering
		

		\centering
		
		\end{figure}
	\end{frame}
	
	\begin{frame}{Mise en vibration de la maquette}
		\frametitle{Première expérience:Réponse à une excitation sinusoïdale}
		\centering
		
		\\
		\vspace{12pt}
		Observations:
		\begin{itemize}
			\item Réduction de l'amplitude des oscillations
			\item Influence du centre de gravité du pendule
			\item Apparition de 2 fréquences de résonance et d'une anti-résonance  
		\end{itemize}
		
	\end{frame}

	\begin{frame}{Mise en vibration de la maquette}
		\frametitle{Première expérience:Réponse à une excitation sinusoïdale}	
		Changement de la masse du pendule:
		\centering
		

		\centering
		

	\end{frame}

	\begin{frame}{Mise en vibration de la maquette}
		\frametitle{Deuxième expérience:Réponse à une excitation brève}
		\begin{columns}
			\begin{column}{0.5\textwidth}
				\alert{Simulation d'une rafale de vent}
				\begin{figure}
					
					\caption{Excitation brève}
				\end{figure}
			\end{column}
			\begin{column}{0.5\textwidth}
				Conditions de l'expérience :
				\begin{itemize}
					\item Dirac avec un ressort 
					\item Oscillations dans un seul plan
				\end{itemize}	
			\end{column}
		\end{columns}
	\end{frame}

	\begin{frame}{Mise en vibration de la maquette}
		\frametitle{Deuxième expérience:Réponse à une excitation brève}
		\vspace{12pt}
		\begin{figure}
				
				\caption{Réponse temporelle à une excitation brève}
				\tiny{\small{\textcolor{orange}{Avec pendule de 100g à 9,4 cm}\\
				\textcolor{blue}{Sans pendule}}}
			%On a choisit de tracer une courbe continue pour que ca soit plus visuel

	\end{figure}
	\end{frame}

	%\begin{frame}{explications}
	%dissipation d'énergie dans le pendule , opposition de phases , rapport des pulsations naturelles
	%\end{frame}
	
	%\begin{frame}{limites}
	%	dimension peu adaptées (rapport de la taille et de la masse du pendule par rapport à la structure\\structure trop élastique qui entraine parfois des non linéarité à la fréquence de résonance )
	%\end{frame}
	
	%\begin{frame}{ce qu'on aurait aimé faire}
	%comparaison avec un modèle informatique\\
	%	plus de variations de paramètres\\
	%	mettre le pendule dans un fluide pour plus de viscosité
	%\end{frame}
	
\section{Conclusion}
\begin{frame}{Conclusion}
	\begin{itemize}
		\item Observation d'une réduction des amplitudes des oscillations avec le pendule.
		\item Comportement similaire au modèle théorique.\vspace{12pt}
	\end{itemize}
Limites :
	\begin{itemize}
		\item Rapport entre masse du pendule et de la structure peu assimilable au réel.
		\item Élasticité de la maquette trop importante.
		\item Pas de dissipation de l'énergie 

	\end{itemize}
\end{frame}	

\section{Annexes}
	
	\begin{frame}
		\frametitle{Annexes}
		Graphique et explication des mesures des coefficients de raideur\\
		Dimension de la tour\\
		schéma solidworks outil de mise en vibration \\
		détermination des incertitudes\\
		équation et fonction de transfert\\
		
	\end{frame}

\begin{frame}{Dimension de la maquette}
			\begin{columns}
		\begin{column}{0.5\textwidth}
			\begin{figure}
				
				\caption{Maquette de l'immeuble}
			\end{figure}
		\end{column}
		\begin{column}{0.5\textwidth}
			\begin{itemize}
				\item  Hauteur : $31,4 cm \pm 0,2 cm$
				\item  Dimension du socle et du toit : $10 cm x 11 cm \pm 0,2 cm$
				\item Masse de la maquette (non équipée) :$ 315,8 g \pm 0,1g $
				\item Masse de la maquette (pendule sans masse): $410,7 g \pm 0,1 g$
				\item Longueur de la tige filetée : $10cm \pm 0,2cm$
				\item Masse de la tige filetée : $ 30,3 g \pm 0,1$
			\end{itemize}
			
		\end{column}
	\end{columns}
\end{frame}

\begin{frame}{Mesure du coefficient de raideur de la tour}
	%explications Mateis
				\begin{columns}
		\begin{column}{0.5\textwidth}
			\begin{figure}
				
				\caption{Détermination du coefficient de raideur élastique de la tour}
			\end{figure}
		\end{column}
		\begin{column}{0.5\textwidth}
				\begin{figure}
				
				\caption{Résultats python}
			\end{figure}
		\end{column}
	\end{columns}
  $K=3,72 N.m.rad^{-1}\pm ?$

  Incertitudes: Dynamomètre: 0,05 N \\
  Mesure des angles : 3 degrés 
\end{frame}

\begin{frame}{Outil de mise en vibration}

	\begin{columns}
		\begin{column}{0.5\textwidth}
			\begin{figure}
				
				\caption{Schéma de l'outil de mise en vibration}
			\end{figure}
		\end{column}
		\begin{column}{0.5\textwidth}
			\begin{figure}
				
				\caption{Planche solidworks du système vibratoire}
			\end{figure}
		\end{column}
	\end{columns}
\end{frame}

\begin{frame}{Dimension du pendule de la tour Tapei 101 à Taiwan}
		\begin{columns}
		\begin{column}{0.5\textwidth}
			\begin{figure}
				
				\caption{Pendule de la tour Taipei 101 à Taiwan}
			\end{figure}
		\end{column}
		\begin{column}{0.5\textwidth}
			Caractéristiques:
			\begin{itemize}
				\item Masse:$660$ tonnes
				\item Diamètre:$5,5 m$
				\item Suspendue entre le 87 ème et le 92 ème étage
				\item Amplitude des oscillations: Jusqu'à $1,5m$
				\item Réduction des oscillations de 30 à 40\%

			\end{itemize}	
		\end{column}
	\end{columns}
\footnote{\tiny https://www.civilengineeringweb.com/2021/04/what-is-tuned-mass-damper.html}
\end{frame}

\begin{frame}{Millennium Bridge à Londres}
	\begin{columns}
		\begin{column}{0.5\textwidth}
			\begin{figure}
				
				\caption{Tuned mass damper sur le millennium bridge à Londres}
			\end{figure}
		\end{column}
		\begin{column}{0.5\textwidth}
			Caractéristiques:
			\begin{itemize}
				\item Nombre: 52 tuned mass dampers
				\item Couplés avec des amortisseurs verticaux et des haubans 
				\item Modification de la fréquence de résonance de la passerelle 

			\end{itemize}	
		\end{column}
	\end{columns}
	\footnote{\tiny https://www.structuresinsider.com/post/why-the-millennium-bridge-experienced-unexpected-swaying}
\end{frame}

	\begin{frame}{Accéléromètre utilisé}
	\begin{columns}
		\begin{column}{0.5\textwidth}
			\begin{figure}
				
				\caption{Accéléromètre LSM6DS3}
			\end{figure}
		\footnote{www.mems-exchange.org}
		\end{column}
		\begin{column}{0.5\textwidth}
			\begin{itemize}
				\item 6 degrés de liberté 
				\item $\pm 2$/$\pm 16$ g
				\item $U(a)=0.122$ mg 
			%	\item $N(a) = 90 \frac{\mu g}{\sqrt{Hz}}$ 
			\end{itemize}
		\end{column}
		
	\end{columns}
	\end{frame}

\begin
\begin{frame}
	Cette première expérience sans pendule permet de trouver les valeurs de k et de h de notre système 
	k=2,5
	h=0,005
\end{frame}

\begin{frame}{Diagramme de bode en amplitude théorique}

	\vspace{12pt}
	\begin{figure}
		
		\caption{Modèle sérieux}
		\end{figure}
\end{frame}

		\begin{frame}
			fonctionnement moteur pas à pas\\
			fonctionnement accéléromètre 
			
		\end{frame}
\end{document}

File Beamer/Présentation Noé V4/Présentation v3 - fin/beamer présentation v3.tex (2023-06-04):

\documentclass{beamer}
\usetheme{Madrid}
\usecolortheme{default}
\usepackage[T1]{fontenc}
\usepackage[french]{babel}
\usepackage{graphicx}
\usepackage{amsmath}
\usepackage{amssymb}
\usepackage{mathrsfs}
\usepackage{xcolor}
\usepackage{empheq}

% Ajouter le plan en haut
\useoutertheme{infolines}
\setbeamertemplate{headline}{
	\begin{beamercolorbox}[ht=2.25ex,dp=3.75ex]{section in head/foot}
		\insertnavigation{\paperwidth}
\end{beamercolorbox}}

\title[]
{Atténuation des vibrations grâce à
	un amortisseur harmonique passif}

\subtitle{}

\author{Noé Bocquillon} 

\date[n°20041] % (optional)
{Numéro de candidat:\\ 20041}

%\logo{\includegraphics[height=0.8cm]{logo_uoft}}

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

			\end{column}
			\footnote{\tiny https://www.constructconnect.com/blog/engineering-giants-how-megatall-skycrapers-are-built}
		\end{columns}
		\bigskip\small TMD = Tuned mass damper

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

	\end{frame}

	\begin{frame}{Construction de la maquette}
		\frametitle{Pendule}

		\begin{columns}
			\begin{column}{0,5\textwidth}
				\begin{figure}
					
					\caption{Pendule}
				\end{figure}
			\end{column}
		\begin{column}{0.5\textwidth}
					Pivot d'axe avec longueur réglable\vspace{24pt}
			Contraintes:
			\begin{itemize}
				\item Masse réglable
				\item Centre de gravité réglable
				\item Oscillations dans un seul plan
			\end{itemize}
		\end{column}
		\end{columns}
	\end{frame}

\begin{frame}{Construction de la maquette}
		\frametitle{Outil de mise en vibration}
		\begin{columns}
			\begin{column}{0.5\textwidth}
				\begin{figure}
					
					\caption{Guidage en translation d'une imprimante}
				\end{figure}
			\end{column}
			\begin{column}{0.5\textwidth}
				Inconvénients:
				\begin{itemize}
					\item Fréquence non réglable \\
					\item Difficultés pour fixer la structure
					
					\item Masse de la structure qui influe sur la vitesse
				\end{itemize}

			\end{column}
		\end{columns}
	\end{frame}

	\begin{frame}{Construction de la maquette}
		\frametitle{Outil de mise en vibration}
 
		\begin{columns}
			\begin{column}{0.5\textwidth}
				\begin{figure}
					
					\caption{Mécanisme}
				\end{figure}
			\end{column}
			\begin{column}{0.5\textwidth}
				Avantages:
				\begin{itemize}
					\item Facilité pour fixer la structure
					\item Fréquence réglable \\
					\item Amplitude réglable 
				\end{itemize}
				%\vspace{12pt}
				Inconvénients:
				
				\begin{itemize}
					\item Hystérésis
				\end{itemize}
			\vspace{12 pt}
					\begin{figure}
				
				\caption{Schéma cinématique du mécanisme}
			\end{figure}
			\end{column}
		\end{columns}

	\end{frame}

%\begin{frame}{Outil de mise en vibration}
%	\begin{figure}
%		\includegraphics[width=0.5\textwidth]{C:/Users/noebo/OneDrive/Documents/Prépa/TIPE TMD/Présentation/Photos comp/Schema_oscillateur_position_droite.drawio-min.png}
%		\caption{Schéma cinématique de l'outil de vibration}
%	\end{figure}
%\end{frame}

	\begin{frame}{Mise en vibration de la maquette}
	
	%schéma de la maquette avec des 2 accéléromètres
	\frametitle{Capteurs}
	\begin{columns}
		\begin{column}{0.25\textwidth}
			\begin{figure}
				
				\caption{Accéléromètre sur le socle}
			\end{figure}
		\end{column}
		\begin{column}{0.5\textwidth}
			\begin{figure}
				
				\caption{Accéléromètre sur le toit}
			\end{figure}
		\end{column}
	\end{columns}
\end{frame}

\begin{frame}{Schéma de la maquette}
	\begin{figure}
		
		\caption{Schéma 2D du montage global}
	\end{figure}
\end{frame}
	
\section{Élaboration du modèle théorique}

\begin{frame}{Détermination du modèle théorique}
 Modélisation de la maquette sans pendule:\vspace{12 pt}
	\begin{columns}
		\begin{column}{0.5\textwidth}
			\begin{figure}
				
				\caption{Modélisation sans pendule}
			\end{figure}
		\end{column}
		\begin{column}{0.6\textwidth}
			PFD à la tour:
			\begin{equation*}
				M\ddot{x} = -kx -h\dot{x} + f(t)
			\end{equation*}
			Ce qui donne la fonction de transfert : 
			$H(\omega)=\frac{X}{\frac{F}{k}}=\frac{1}{1+j*\frac{h}{k}*\omega-\frac{M}{k}*\omega^{2}}$
		\end{column}
	\end{columns}
\end{frame}	

\begin{frame}{Élaboration d'un modèle théorique}
	\frametitle{Modélisation du système avec pendule}
	\begin{columns}
		\begin{column}{0.5\textwidth}
			\begin{figure}
				\centering
				
				\caption{Modèle équivalent du système}
			\end{figure}
		\footnote{\tiny Schéma provenant du sujet Mines-Ponts Physique 2 MP 2007}
		\end{column}
		\begin{column}{0.5\textwidth}
			\begin{itemize}
				\item m=Masse équivalente du pendule
				\item M=Masse équivalente de la tour
				\item $k_{1}$=Coefficient de raideur élastique du pendule
				\item k=Coefficient de raideur élastique (Tiges + bouchons dans notre modèle)
				\item $h_{1}$= coefficient de frottement du pendule 
				\item h=coefficient de frottement de la tour
			\end{itemize}	
		\end{column}
	\end{columns}
	
\end{frame}

%\begin{frame}{Modélisation du système avec pendule}
	%PFD à la tour sans pendule ni excitation extérieure (Correspond au Dirac): 
%	\begin{equation}\label{key}
	%	\ddot{x} + \frac{h}{M}\dot{x}  + \frac{K}{M}x = 0
%	\end{equation}\vspace{24pt}
%	Période naturelle de la tour:$ T = 2\pi\frac{1}{\sqrt{\frac{K}{M}-\frac{h}{4M^2}}}$\\
%	\vspace{12 pt}
%	Mesure de T et de h expérimentalement :\\ Obtention de la valeur de K
%\end{frame}

\begin{frame}{Élaboration d'un modèle théorique}
	\frametitle{Équations du système}	
	L'excitation extérieure est modélisée par une force $f_{0}(t)$ appliquée à la tour\vspace{12pt}
	PFD à ${tour + TMD}$:
	\begin{equation}\label{key}
		M\ddot{x} + m(\ddot{x}+\ddot{u}) +h\dot{x} + kx = f_{0}(t)
	\end{equation}\\
	\vspace{12pt}
	PFD  au TMD uniquement:
	\begin{equation}
		m(\ddot{x}+\ddot{u}) + h_{1}\dot{u} + k_{1}u = 0
	\end{equation}\\

\end{frame}

\begin{frame}{Fonctions de transfert du système}
	
\begin{empheq}[left=\empheqlbrace]{align*}
	H1(\omega)&=\frac{U}{X}= \frac{m\omega^{2}}{k_{1}+jh_{1}\omega-m\omega^{2}}\\
	H2(\omega)&=\frac{X}{\frac{F_{0}}{k}}= \frac{1}{1+j\frac{h}{k}\omega-\frac{(M+m)}{k}\omega^2-\frac{H1(\omega)}{k}\omega^2}
\end{empheq}
\vspace{12 pt}

\end{frame}
\section{Mise en vibration de la maquette}

\begin{frame}{Mise en vibration de la maquette}
	\frametitle{Première expérience:Réponse à une excitation sinusoïdale}
	\begin{columns}
		\begin{column}{0.35\textwidth}
			\alert{Simulation d'un séisme}
		\end{column}
		\begin{column}{0.6\textwidth}
			Conditions de l'expérience :
			\begin{itemize}
				\item Excentration la plus faible 
				\item Oscillations dans un seul plan
				\item Plage de fréquences :[0.5 hz;4 hz]
			\end{itemize}	
		\end{column}
	\end{columns}
\vspace{12pt}

	\begin{figure}
		
		
	\end{figure}

\end{frame}

	\begin{frame}{Première expérience:Réponse à une excitation sinusoïdale}
	Changement de la longueur du pendule:

		\begin{figure}
		\centering
		

		\centering
		
		\end{figure}
	\end{frame}
	
	\begin{frame}{Mise en vibration de la maquette}
		\frametitle{Première expérience:Réponse à une excitation sinusoïdale}
		\centering
		
		\\
		\vspace{12pt}
		Observations:
		\begin{itemize}
			\item Réduction de l'amplitude des oscillations
			\item Influence du centre de gravité du pendule
			\item 2 fréquences de résonance et une anti-résonance   
		\end{itemize}
		
	\end{frame}

	\begin{frame}{Mise en vibration de la maquette}
		\frametitle{Première expérience:Réponse à une excitation sinusoïdale}	
		Changement de la masse du pendule:
		\centering
		

		\centering
		

	\end{frame}

	\begin{frame}{Mise en vibration de la maquette}
		\frametitle{Deuxième expérience:Réponse à une excitation brève}
		\begin{columns}
			\begin{column}{0.5\textwidth}
				\alert{Simulation d'une rafale de vent}
				\begin{figure}
					
					\caption{Excitation brève}
				\end{figure}
			\end{column}
			\begin{column}{0.5\textwidth}
				Conditions de l'expérience :
				\begin{itemize}
					\item Dirac avec un ressort 
					\item Oscillations dans un seul plan
				\end{itemize}	
			\end{column}
		\end{columns}
	\end{frame}

	\begin{frame}{Mise en vibration de la maquette}
		\frametitle{Deuxième expérience:Réponse à une excitation brève}
		\vspace{12pt}
		\begin{figure}
				
				\caption{Réponse temporelle à une excitation brève}
				\tiny{\small{\textcolor{orange}{Avec pendule de 100g à 5 cm}\\
				\textcolor{blue}{Sans pendule}}}
			%On a choisit de tracer une courbe continue pour que ca soit plus visuel

	\end{figure}
	\end{frame}

	%\begin{frame}{explications}
	%dissipation d'énergie dans le pendule , opposition de phases , rapport des pulsations naturelles
	%\end{frame}
	
	%\begin{frame}{limites}
	%	dimension peu adaptées (rapport de la taille et de la masse du pendule par rapport à la structure\\structure trop élastique qui entraine parfois des non linéarité à la fréquence de résonance )
	%\end{frame}
	
	%\begin{frame}{ce qu'on aurait aimé faire}
	%comparaison avec un modèle informatique\\
	%	plus de variations de paramètres\\
	%	mettre le pendule dans un fluide pour plus de viscosité
	%\end{frame}
	
\section{Conclusion}
\begin{frame}{Conclusion}
	\begin{itemize}
		\item Observation d'une réduction des amplitudes des oscillations avec le pendule.
		\item Comportement similaire au modèle théorique.\vspace{12pt}
	\end{itemize}
Limites :
	\begin{itemize}
		\item Rapport entre masse du pendule et de la structure peu assimilable au réel.
		\item Élasticité de la maquette trop importante.

	\end{itemize}
\end{frame}	

\begin{frame}{Conclusion}

Approfondissements:
	\begin{itemize}
		\item Étudier plus en détail l'influence des paramètres.
		\item Mettre en place un amortissement visqueux pour la dissipation d'énergie.
		
	\end{itemize}
\end{frame}	

\section{Annexes}

\begin{frame}{Dimension de la maquette}
			\begin{columns}
		\begin{column}{0.5\textwidth}
			\begin{figure}
				
				\caption{Maquette de l'immeuble}
			\end{figure}
		\end{column}
		\begin{column}{0.5\textwidth}
			\begin{itemize}
				\item  Hauteur : $31,4 cm \pm 0,2 cm$
				\item  Dimension du socle et du toit : $10 cm x 11 cm \pm 0,2 cm$
				\item Masse de la maquette (non équipée) :$ 315,8 g \pm 0,1g $
				\item Masse de la maquette (pendule sans masse): $410,7 g \pm 0,1 g$
				\item Longueur de la tige filetée : $10cm \pm 0,2cm$
				\item Masse de la tige filetée : $ 30,3 g \pm 0,1$
			\end{itemize}
			
		\end{column}
	\end{columns}
\end{frame}

\begin{frame}{Diagramme de bode en amplitude théorique}
	
	\vspace{12pt}
	\begin{figure}
		
		\caption{Modèle théorique plus poussé: Réponse à une excitation sinusoïdale}
	\end{figure}
\footnote{\tiny https://www.lisega.de/en/vibration-control-en/tuned-mass-dampers-tmd}
\end{frame}

\begin{frame}{Fréquences}
	\begin{columns}
		\begin{column}{0.5\textwidth}
			\begin{figure}
				
				\caption{Schéma du pendule}
			\end{figure}
		\end{column}
		\begin{column}{0.5\textwidth}
			\begin{itemize}
				\item 	Période propre du pendule: $T= 2\pi\sqrt{\frac{J_{p}}{mgh+M_{t}ga}}$ \\
				avec $J=\frac{1}{3}M_{t}L^2 + mh^2$
				\vspace{12pt}
				\item  $f_{r}= 2,1 hz \pm 0.05 hz$ 
				\item  $f_{n}= 2 hz \pm 0.05 hz$ 
			\end{itemize}
		\vspace{12pt}
			Choix de h telle que $\frac{1}{T}=f_{n}$ pour optimiser la réduction de l'amplitude des oscillations

			\end{column}
	\end{columns}
\end{frame}

%\begin{frame}{Mesure du coefficient de raideur de la tour}
	%explications Mateis
		%		\begin{columns}
	%	\begin{column}{0.5\textwidth}
	%		\begin{figure}
	%			\includegraphics[width=0.7\textwidth]{C:/Users/noebo/OneDrive/Documents/Prépa/TIPE TMD/Présentation/Photos comp/valeur coef raideur-min.png}
	%			\caption{Détermination du coefficient de raideur élastique de la tour}
	%		\end{figure}
	%	\end{column}
	%%			\begin{figure}
	%			\includegraphics[width=0.7\textwidth]{C:/Users/noebo/OneDrive/Documents/Prépa/TIPE TMD/Présentation/Photos comp/coef raideur-min.png}
	%			\caption{Résultats python}
	%		\end{figure}
	%	\end{column}
	%\end{columns}
  %$K=3,72 N.m.rad^{-1}\pm ?$

  %Incertitudes: Dynamomètre: 0,05 N \\
  %Mesure des angles : 3 degrés 
%\end{frame}

\begin{frame}{Outil de mise en vibration}

	\begin{columns}
		\begin{column}{0.5\textwidth}
			\begin{figure}
				
				\caption{Schéma de l'outil de mise en vibration}
			\end{figure}
		\end{column}
		\begin{column}{0.5\textwidth}
			\begin{figure}
				
				\caption{Planche solidworks du système vibratoire}
			\end{figure}
		\end{column}
	\end{columns}
\end{frame}

	\begin{frame}{Accéléromètre utilisé}
	\begin{columns}
		\begin{column}{0.5\textwidth}
			\begin{figure}
				
				\caption{Accéléromètre LSM6DS3}
			\end{figure}
		\footnote{www.mems-exchange.org}
		\end{column}
		\begin{column}{0.5\textwidth}
			\begin{itemize}
				\item 6 degrés de liberté 
				\item $\pm 2$/$\pm 16$ g
				\item $U(a)=0.122$ mg 
				\item $N(a) = 90 \frac{\mu g}{\sqrt{Hz}}$ 
			\end{itemize}
		\end{column}
		
	\end{columns}
	\end{frame}

\begin{frame}{Mise en vibration}
	\begin{figure}
		
		\caption{Mise en vibration de la maquette sans pendule}
	\end{figure}
\end{frame}

\begin{frame}{Traitement des données}
	\begin{figure}
		
		\caption{Code python pour le tracé des courbes }
	\end{figure}
\end{frame}

\begin{frame}{Traitement des données}
	\begin{figure}
		
		\caption{Code python pour déterminer l'incertitude sur l'amplitude}
	\end{figure}
\end{frame}

\begin{frame}{Dimension du pendule de la tour Tapei 101 à Taiwan}
	\begin{columns}
		\begin{column}{0.5\textwidth}
			\begin{figure}
				
				\caption{Pendule de la tour Taipei 101 à Taiwan}
			\end{figure}
		\end{column}
		\begin{column}{0.5\textwidth}
			Caractéristiques:
			\begin{itemize}
				\item Masse:$660$ tonnes
				\item Diamètre:$5,5 m$
				\item Matériaux: Acier
				\item Suspendu entre le 87 ème et le 92 ème étage
				\item Amplitude des oscillations: Jusqu'à $1,5m$
				\item Réduction des oscillations de la tour de 30 à 40\%

			\end{itemize}	
		\end{column}
	\end{columns}
	\footnote{\tiny https://www.civilengineeringweb.com/2021/04/what-is-tuned-mass-damper.html}
\end{frame}

\begin{frame}{Millennium Bridge à Londres}
	\begin{columns}
		\begin{column}{0.5\textwidth}
			\begin{figure}
				
				\caption{Tuned mass damper sur le millennium bridge à Londres}
			\end{figure}
		\end{column}
		\begin{column}{0.5\textwidth}
			Caractéristiques:
			\begin{itemize}
				\item Nombre: 52 tuned mass dampers
				\item Couplés avec des amortisseurs verticaux et des haubans 
				\item Modification de la fréquence de résonance de la passerelle 

			\end{itemize}	
		\end{column}
	\end{columns}
	\footnote{\tiny https://www.structuresinsider.com/post/why-the-millennium-bridge-experienced-unexpected-swaying}
\end{frame}

\end{document}

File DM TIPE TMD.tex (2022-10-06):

\documentclass[a4paper]{article}
\usepackage[french]{babel}
\usepackage{graphicx}
\title{ Tuned mass damper}
\author{FRAMBOURT Mateïs et BOCQUILLON Noé}

\begin{document}
	\maketitle
\paragraph{\underline{Titre provisoire:}} Modélisation et simulation d'un immeuble à amortisseur harmonique.
	
\paragraph{\underline{Objectif du TIPE:}}
  Mesurer et évaluer l'efficacité d'un amortisseur harmonique (Tuned mass Damper).
  
  \paragraph{\underline{Manipulations:}}
  Le but est dans un premier temps de modéliser par une maquette très simple un immeuble et de le faire entrer en vibration à l'aide d'un axe linéaire.
  Nous allons d'abord construire une maquette rigide afin de montrer que celle-ci vibrera à la même fréquence et amplitude que l'entrée et donc ne sera pas adapté à ce que l'on veut observer.De plus, cette première expérience sera l'occasion de vérifier que nos projets de modélisation de maquette sont réalisables ainsi que le bon fonctionnement de l'acquisition de données (L'acquisition sera décrite de manière plus précise plus bas)
 
\subparagraph{Description de la maquette:}Sur une base en bois, on fixe 4 tiges de bois rigides et épaisses dont le haut est relié par une plaque en bois %\input{./photo} 
\begin{figure}[h]
 \center{}
 \caption {maquette de l'immeuble rigide}
\end{figure}

 \subparagraph{}Nous allons ensuite construire un modèle un peu plus représentatif des interactions réelles. Pour cela, nous visseront des demi-balles rebondissante à chaque liaison pour simuler une déformation avec une force de rappel. Cette modélisation permettra de (
\begin{figure}[h]
 \center{}
 \caption {maquette de l'immeuble semi flexible}
\end{figure}
La maquette sera fixée sur un axe linéaire qui permet la mise en vibration. 
L'acquisition de l'accélération en fonction du temps sera effectuée dans un premier temps, de manière simple et intuitive , à l'aide de nos deux téléphones et de l'application \textit{Physics Tool Box} qui contient un accéléromètre. L'utilisation de nos deux téléphones (un fixé en haut et l'autre en bas)permettra de comparer la différence d'amplitude entre le haut et le bas de la maquette et une éventuelle résonance. Mais la masse de nos deux téléphone étant non négligeable, il sera envisagé de remplacer les téléphones par des modules accéléromètre et un microcontrolleur.
L'ajout d'en pendule simple fixé sur le haut de la structure devrait nous permettre d'observer une éventuelle réduction des oscillations en sa présence. 

\end{document}

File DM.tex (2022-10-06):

\documentclass[a4paper]{article}
\usepackage[french]{babel}
\author{BOCQUILLON Noé,FRAMBOURT Mateïs}
\usepackage{ragged2e}
\title{DM TIPE}
\begin{document}
\maketitle 
\justifying
\paragraph{Titre du TIPE : Modélisation et Simulation d'un amortisseur \\harmonique dans le cadre de la  prévention sismique}
\section{Objectif du TIPE} 
Le but de ce TIPE est de modéliser un immeuble puis de concevoir un amortisseur harmonique pour limiter

\end{document}

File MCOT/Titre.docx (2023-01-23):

Titre :

Modélisation et simulation de la mise en vibration d’un immeuble avec amortisseur harmonique passif

Ancrage :

Les immeubles étant de plus en plus grand, ils sont d’autant plus sensibles aux phénomènes de résonnances. Il est donc nécessaire d’apporter un système de protection pour ces bâtiments essentiels à la ville. Pour cela un amortisseur harmonique passif, ici un pendule simple, permet de supprimer le pic de résonnance passivement en réglant ses paramètres géométriques.

Positionnement thématique :

Physique(mécanique), physique (physique de la matière), Sciences industrielle (génie mécanique), Informatique Pratique (simulation informatique)

Mots-clés (Français) :

Résonnance, oscillateur harmonique, protection des bâtiments, séisme, simulation

Mots-clés (Anglais) :

Resonance, Tuned mass damper, building, earthquake, simulation

Bibliographie :

Les premiers amortisseurs à masse accordée (AMA) ont été conçu au début du XXème siècle par Frahm, il était d’abord utilisé pour réduire le tangage dans les bateaux puis a été repris par Den Hartog dans les années 1940 qui proposa un réglage optimal des différents paramètres pour obtenir une oscillation minimale. [1] L’étude sera limitée aux amortisseurs unidimensionnels. Il existe 2 types d’amortisseur harmonique, le premier est linéaire et fonctionne avec un système ressort amortisseur adjoint au système à amortir. Le second, et celui sur lequel se focalise l’étude, est AMA pendulaire qui se base sur un pendule souvent accroché dans les étages supérieurs du bâtiment, par exemple, la tour Taipei 101 à Taïwan possède un pendule de 730 tonnes entre le 87ème et le 92ème étage [2]. L’objectif de ces systèmes est d’empêcher des oscillations d’amplitude trop importante à cause d’une résonance avec les différentes excitations extérieures comme le vent ou les séismes. Pour cela la période du pendule est choisie pour qu’il soit en opposition de phase avec la tour, ce faisant, une partie de l’énergie de la tour est absorbée par le pendule. La difficulté est l’optimisation du paramètre de synchronisation de l’amortisseur (le rapport entre la pulsation propre de l’amortisseur et de la tour). Idéalement il doit être de 1, l’amortisseur doit donc avoir la même fréquence propre que celle de la tour. Les performances de l’AMA décroissent fortement quand le paramètre de synchronisation s’éloigne de 1 mais il est nécessaire d’avoir un amortissement car son absence dédoublerait la résonance, ce qui est évité avec un choix judicieux de l’amortissement. [4] En optimisant l’AMA il est possible de réduire l’amplitude des oscillations de moitié [1].

2ème jet :

Problématique :

Quel est l’influence de l’AMA pendant un excitation extérieure et comment en optimiser les paramètres ?

Objectifs du TIPE du candidat :

- Modéliser une excitation extérieure
- Etudier la réponse en fréquence du modèle
- Simuler informatiquement la réponse de l’immeuble théorique
- Optimiser les paramètres de la simulation pour obtenir l’oscillation minimale
- Comparer au modèle pratique

Objectifs du TIPE du second candidat :

- Modéliser un immeuble subissant une contrainte extérieure de manière sommaire
- Etudier l’influence de l’amortisseur à masse accordée sur l’atténuation des vibrations
- Etudier l’influence des paramètres de l’AMA sur son efficacité
- Comparaison des résultats à un modèle théorique

Référence bibliographique

[1]https://engineering.purdue.edu/~ce573/Documents/Intro%20to%20Structural%20Motion%20Control_Chapter4.pdf

[1] Othman Ben Mekki. Amortissement semi-actif des structures flexibles. Engineering Sciences [physics]. Ecole des Ponts ParisTech, 2006. English. ffNNT: ff. ffpastel-00002570f

[2] : https://bsbgroup.com/blog/the-mechanism-and-applications-of-tuned-mass-damper-tmd

[3] : https://www.researchgate.net/publication/258167207_Tuned_Mass_Dampers

[4] Anissa Allani. Conception et optimisation d’amortisseurs à masse accordée pour les structures du génie civil. Matériaux et structures en mécanique [physics.class-ph]. Université Paris-Est; Università degli studi di Roma ”Tor Vergata” (1972-..), 2015. Français. ffNNT : 2015PESC1137ff. fftel-01291427f

Abstract :

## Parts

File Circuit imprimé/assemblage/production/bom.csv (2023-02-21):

Designator | Footprint | Quantity | Value | LCSC Part #
C1_4, C3, C4_2 | CP_Elec_6.3x7.7 | 3 | 10u
C1_3, C1_2, C1, C2_3, C2_2, C2, C3_2, C4, C5_2 | Cap 100nf 0805 | 9 | 100n
C5 | 0805 | 1 | 10n
C6 | 0805 | 1 | 220n
C7 | 0603 | 1 | 5.6n
D1_4 | 1206 | 1 | LED
D1_3, D2 | SOD223 | 2 | D_Zener
D1_2 | 1206 | 1 | LED
D1 | 1206 | 1 | LED
D2_2 | UV_LED | 1 | LED
D3_2 | 1206 | 1 | LED
D3 | 1206 | 1 | LED
D4, D5 | D_SOD-323 | 2 | D
D6 | 1206 | 1 | LED
FB1 | ferrite Bead | 1 | FerriteBead
IC1 | L6225DTR | 1 | L6225DTR
J1_4, J1_2, J1, J2_2, J4 | FPC 2x7 p=1mm | 5 | Conn_01x14_Shielded
J1_3 | BarrelJack_GCT_DCJ200-10-A_Horizontal | 1 | Barrel_Jack_Switch
J2_4 | USB_B_OST_USB-B1HSxx_Horizontal | 1 | USB_B
J2_3, J2 | PinSocket_1x06_P2.54mm_Vertical | 2 | Conn_01x06_Male
J3_2 | TerminalBlock_Dinkle_DT-55-B01X-02_P10.00mm | 1 | Screw_Terminal_01x02
J3 | microSD_HC_Hirose_DM3AT-SF-PEJM5 | 1 | Micro_SD_Card_Det
J5 | PinSocket_1x04_P2.54mm_Horizontal | 1 | UART
JP1_3, JP1_2, JP1 | SolderJumper-3_P1.3mm_Bridged12_RoundedPad1.0x1.5mm | 3 | SolderJumper_3_Bridged12
JP2_3, JP2_2, JP2 | SolderJumper-2_P1.3mm_Open_RoundedPad1.0x1.5mm | 3 | SolderJumper_2_Open
Q1_2, Q1, Q2 | SOT-23 | 3 | LP2301LT1G
R1_4 | 0603 | 1 | 10k
R1_3 | 0603 | 1 | 10k
R1_2 | 0603 | 1 | 100
R1 | 0603 | 1 | 10k
R10 | 0603 | 1 | 1k
R11 | 0603 | 1 | 1k
R12 | 0805 | 1 | 30
R2_4 | 0603 | 1 | 100
R2_3 | 0805 | 1 | 30
R2_2 | 0805 | 1 | 30
R2 | 0603 | 1 | 1k
R3_2 | 0603 | 1 | 100
R3 | 0603 | 1 | 1k
R4_2 | 0603 | 1 | 1k
R4 | 0603 | 1 | 1k
R5_2 | 0603 | 1 | 1k
R5 | 0805 | 1 | 30
R6_2 | 0603 | 1 | 100
R6 | 0603 | 1 | 4.7k
R7_2 | 0603 | 1 | 4.7k
R7 | 0603 | 1 | 100k
R8_2 | 0603 | 1 | 100
R8 | 0603 | 1 | 1k
R9 | 0805 | 1 | 30
SW1 | Tactile Button | 1 | RESET
TP1, TP2, TP3, TP4, TP5 | TestPoint_Pad_D2.0mm | 5 | TestPoint
U1_4 | RPi_PicoW_SMD_TH | 1 | PicoW
U1_3 | SOIC-16_3.9x9.9mm_P1.27mm | 1 | CH340C
U1_2, U1, U2 | LGA-14_2.5X3X0.86_ | 3 | LSM6DSRTR
U2_2 | SOT-223-3_TabPin2 | 1 | AMS1117-3.3
U3 | Vishay TCUT1350X01 | 1 | Vishay_TCUT1350X01
U4 | VSSOP-8_2.3x2mm_P0.5mm | 1 | 74LVC3G17

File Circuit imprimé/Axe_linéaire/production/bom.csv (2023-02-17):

Designator | Footprint | Quantity | Value | LCSC Part #
C1, C2, C5 | Cap 100nf 0805 | 3 | 100n
C3, C4 | CP_Elec_6.3x7.7 | 2 | 10u
D1 | SOD223 | 1 | D_Zener
D2 | UV_LED | 1 | LED
D3 | 1206 | 1 | LED
FB1 | ferrite Bead | 1 | FerriteBead
J1, J2 | FPC 2x7 p=1mm | 2 | Conn_01x14_Shielded
J3 | microSD_HC_Hirose_DM3AT-SF-PEJM5 | 1 | Micro_SD_Card_Det
JP1 | SolderJumper-3_P1.3mm_Bridged12_RoundedPad1.0x1.5mm | 1 | SolderJumper_3_Bridged12
JP2 | SolderJumper-2_P1.3mm_Open_RoundedPad1.0x1.5mm | 1 | SolderJumper_2_Open
Q1, Q2 | SOT-23 | 2 | LP2301LT1G
R1 | 0603 | 1 | 10k
R10 | 0603 | 1 | 1k
R11 | 0603 | 1 | 1k
R12 | 0805 | 1 | 30
R2 | 0603 | 1 | 1k
R3 | 0603 | 1 | 100
R4 | 0603 | 1 | 1k
R5 | 0603 | 1 | 1k
R6 | 0603 | 1 | 4.7k
R7 | 0603 | 1 | 4.7k
R8 | 0603 | 1 | 100
R9 | 0805 | 1 | 30
SW1 | Tactile Button | 1 | RESET
TP1, TP2, TP3, TP4, TP5 | TestPoint_Pad_D2.0mm | 5 | TestPoint
U1 | RPi_PicoW_SMD_TH | 1 | PicoW
U2 | LGA-14_2.5X3X0.86_ | 1 | LSM6DSRTR
U3 | Vishay TCUT1350X01 | 1 | Vishay_TCUT1350X01
U4 | VSSOP-8_2.3x2mm_P0.5mm | 1 | 74LVC3G17

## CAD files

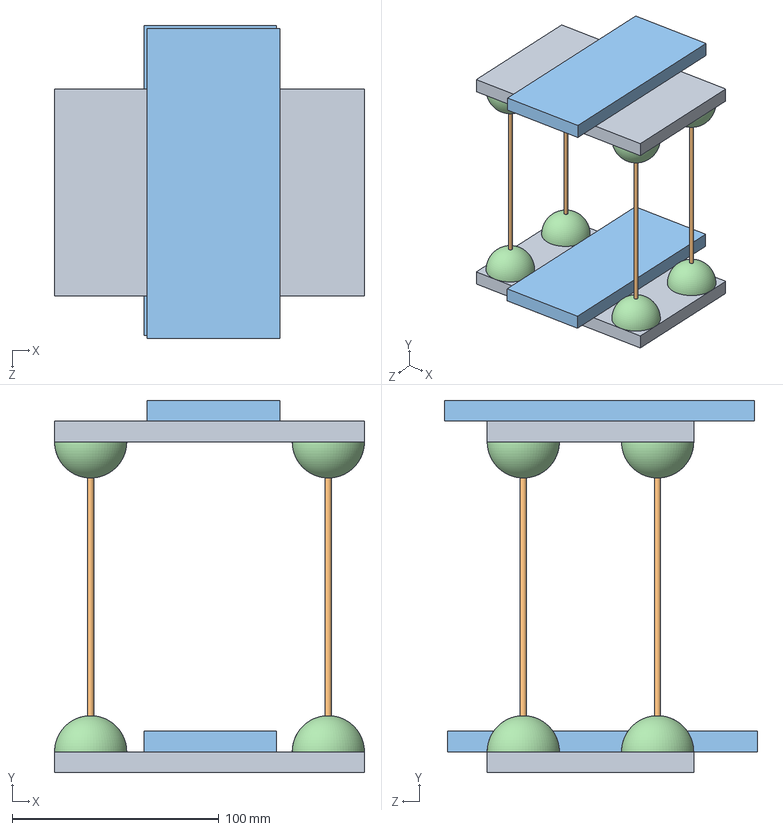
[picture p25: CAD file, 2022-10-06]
expérience/immeuble/modèle rebondissante.SLDASM
150.0 x 180.0 x 151.6 mm
base x 2
pic a brochette x 4
téléphone x 2
balle rebondissante x 8

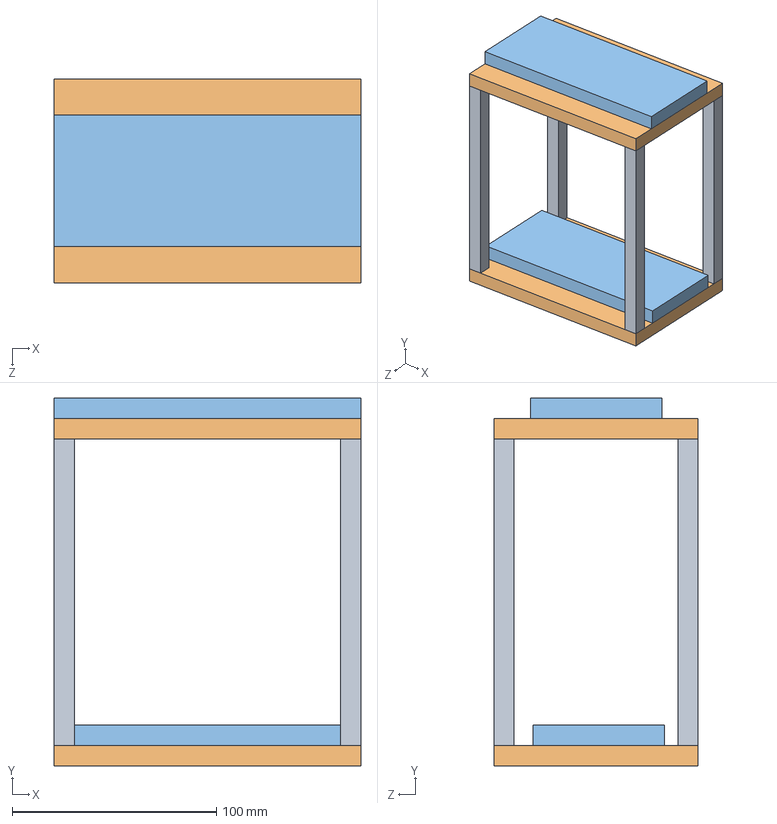
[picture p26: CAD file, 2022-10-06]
expérience/immeuble/modèle rigide.SLDASM
150.0 x 180.0 x 100.0 mm
baguette x 4
base x 2
téléphone x 2

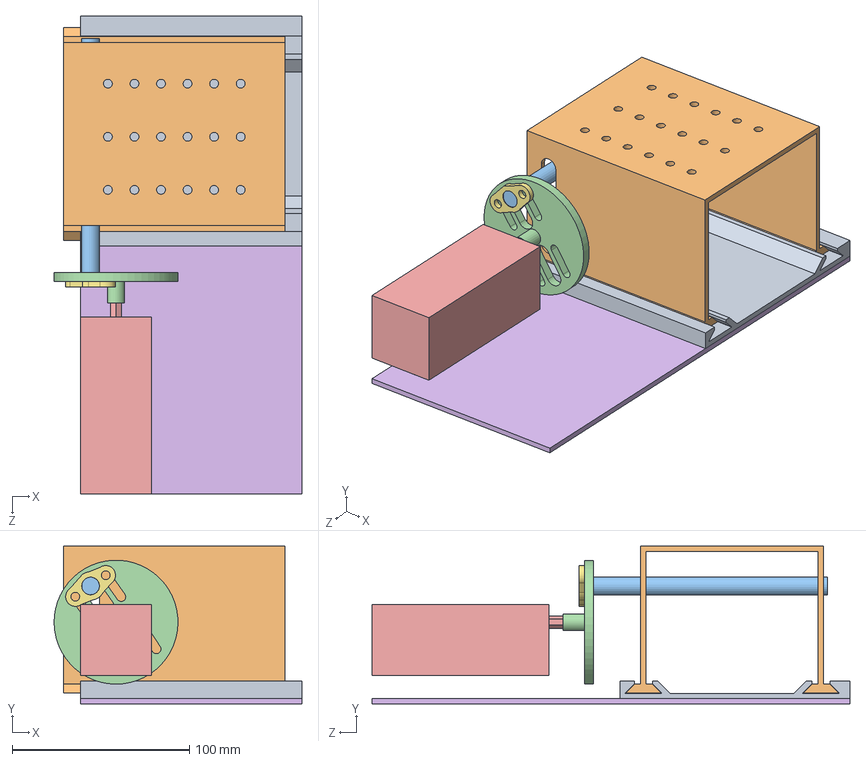
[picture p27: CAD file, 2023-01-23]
test axe linéaire/assemblé.SLDASM
140.0 x 89.2 x 270.0 mm
base
glissière
tige filetée
oscillant
moteur simpliste
planche support
vérou d'axe

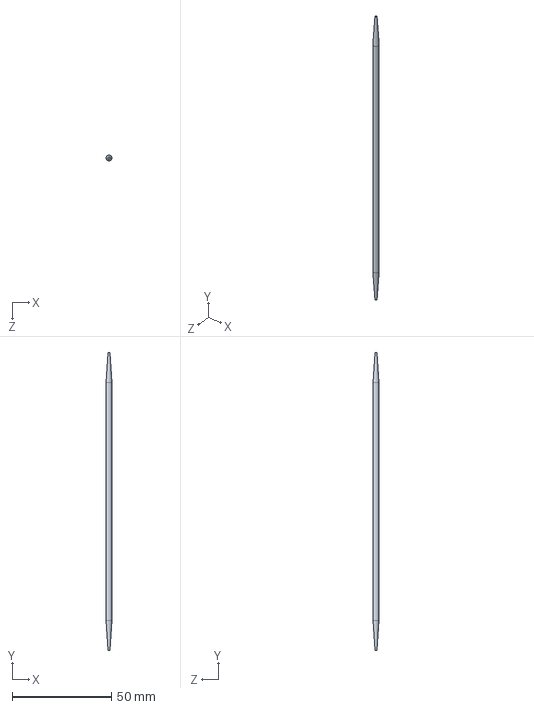
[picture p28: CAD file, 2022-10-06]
expérience/immeuble/pic a brochette.SLDPRT
3.00 x 150.0 x 3.00 mm

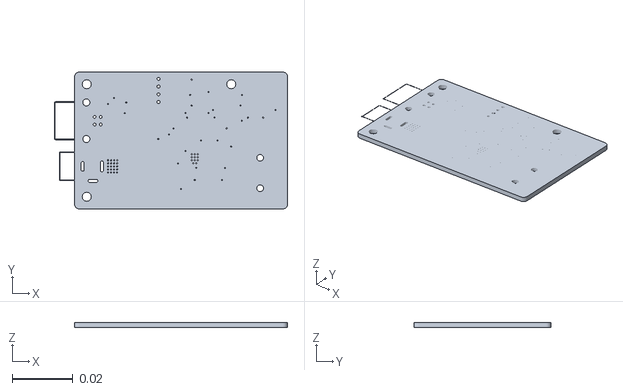
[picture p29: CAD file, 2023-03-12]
rendu/ImageToStl.com_base.obj
0.0766 x 0.045 x 0.00175

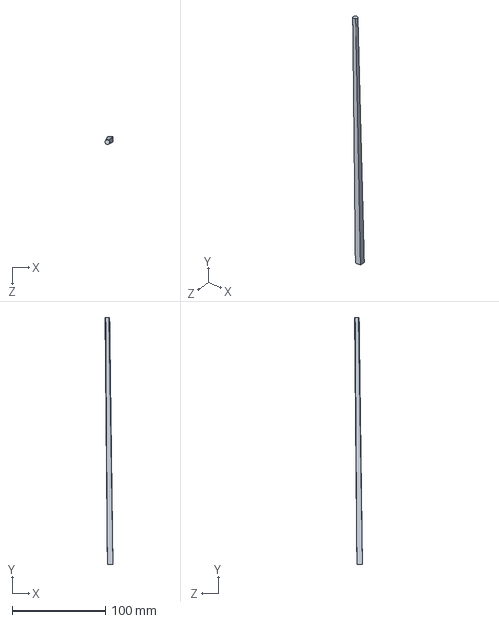
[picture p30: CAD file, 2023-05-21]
Simulation/Matlab/baguette v2.SLDPRT
8.50 x 265.0 x 8.50 mm

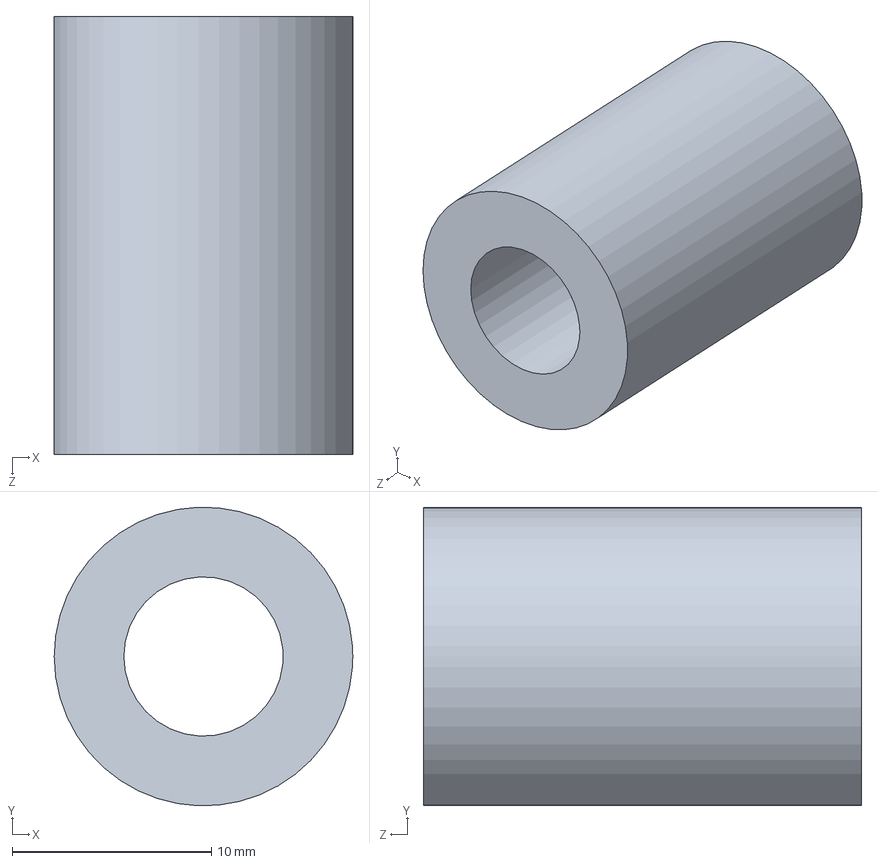
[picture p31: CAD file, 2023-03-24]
test axe linéaire/rondelle pendule.SLDPRT
15.0 x 15.0 x 22.0 mm

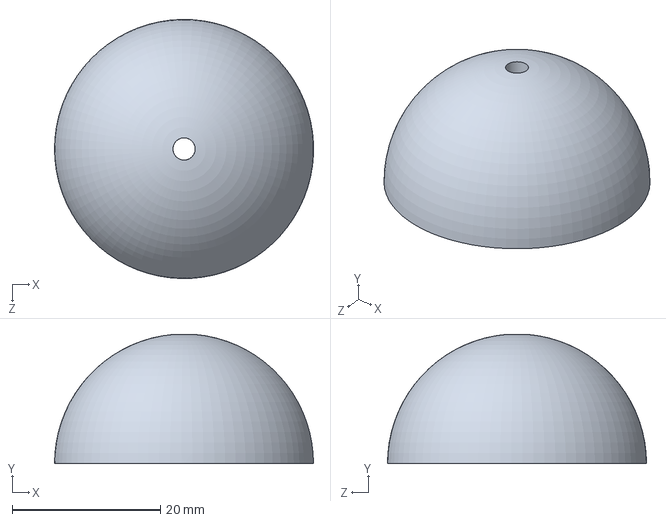
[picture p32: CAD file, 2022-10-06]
expérience/immeuble/balle rebondissante.SLDPRT
35.0 x 17.4 x 35.0 mm

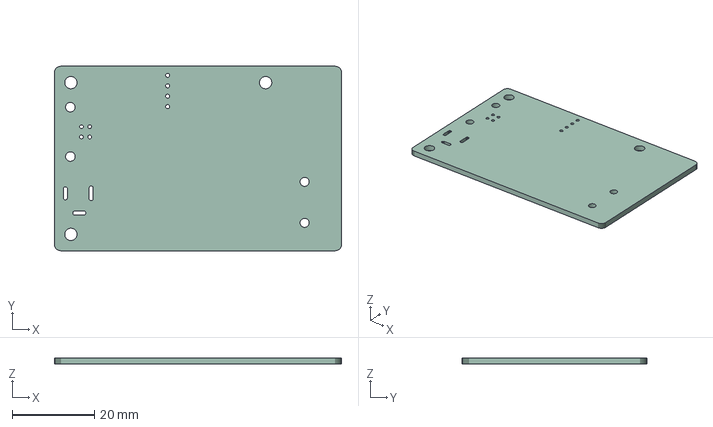
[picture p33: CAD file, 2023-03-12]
rendu/base.step
70.0 x 45.0 x 1.58 mm

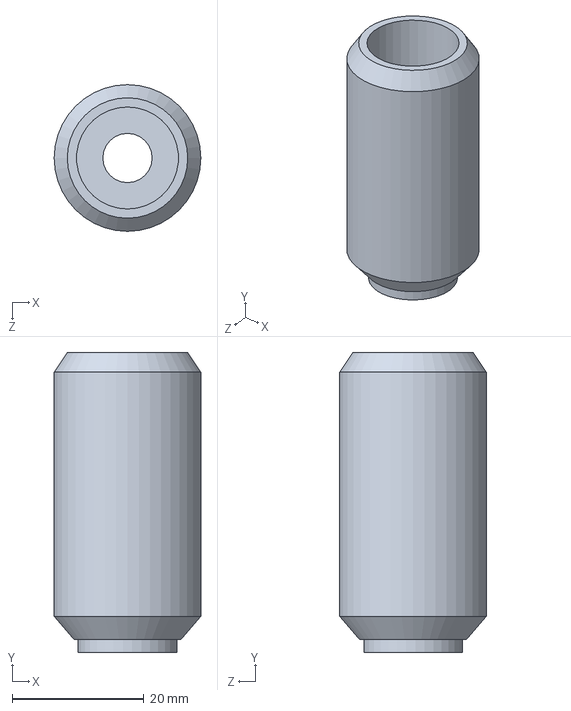
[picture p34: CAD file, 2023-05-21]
Simulation/Matlab/masse trotinette.SLDPRT
22.3 x 45.6 x 22.3 mm

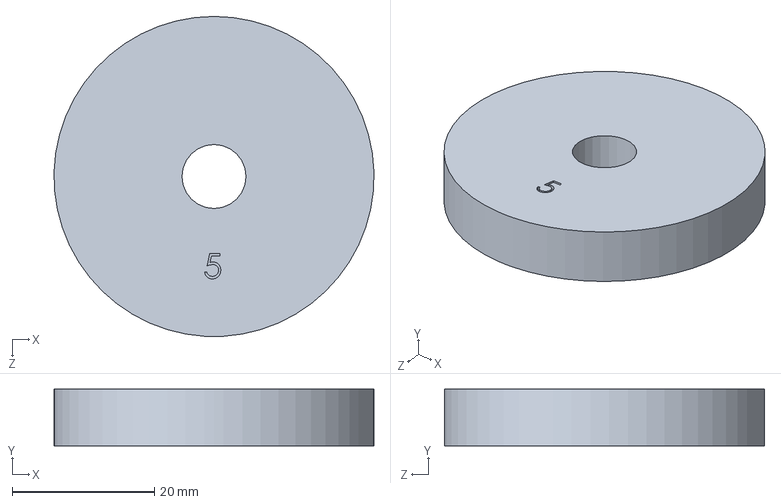
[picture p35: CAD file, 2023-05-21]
Simulation/Matlab/masse à vis.SLDPRT
45.0 x 8.00 x 45.0 mm

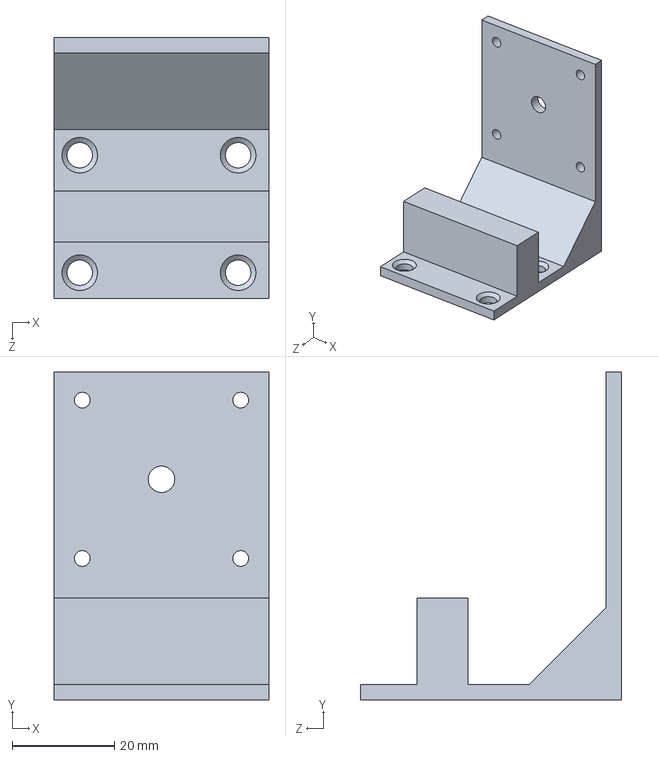
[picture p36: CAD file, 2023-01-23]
test axe linéaire/support moteur.SLDPRT
42.0 x 64.2 x 51.0 mm

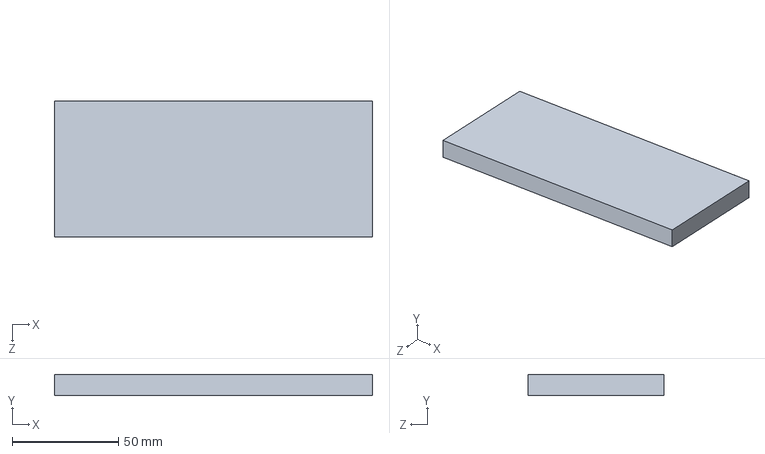
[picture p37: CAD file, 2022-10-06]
expérience/immeuble/téléphone.SLDPRT
150.0 x 10.0 x 64.3 mm

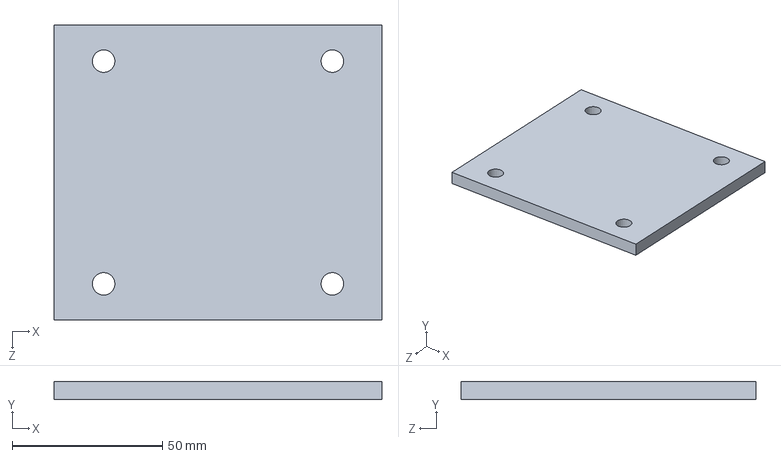
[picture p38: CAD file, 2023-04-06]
Simulation/Matlab/haut.SLDPRT
109.0 x 6.00 x 98.0 mm

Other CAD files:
rendu/ImageToStl.com_base lisse.obj
test axe linéaire/Pendule attache.SLDPRT
Simulation/Matlab/base v2.SLDPRT
expérience/immeuble/base.SLDPRT
Simulation/Matlab/baguette chinoise.SLDPRT
Simulation/Matlab/base.SLDPRT
Simulation/Matlab/bouchon.SLDPRT
expérience/immeuble/baguette.SLDPRT
expérience/immeuble/modèle rebondissante.DXF
expérience/immeuble/modèle rebondissante.SLDDRW
test axe linéaire/Pendule attache.STL
test axe linéaire/assemblé.SLDDRW
test axe linéaire/base.SLDPRT
test axe linéaire/base.STL
test axe linéaire/glissière.SLDPRT
test axe linéaire/glissière.STL
test axe linéaire/moteur simpliste.SLDPRT
test axe linéaire/oscillant.SLDPRT
test axe linéaire/oscillant.STL
test axe linéaire/planche support.SLDPRT
test axe linéaire/support moteur V3.STL
test axe linéaire/support moteur V4.STL
test axe linéaire/support moteur.STL
test axe linéaire/tige filetée.SLDPRT
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

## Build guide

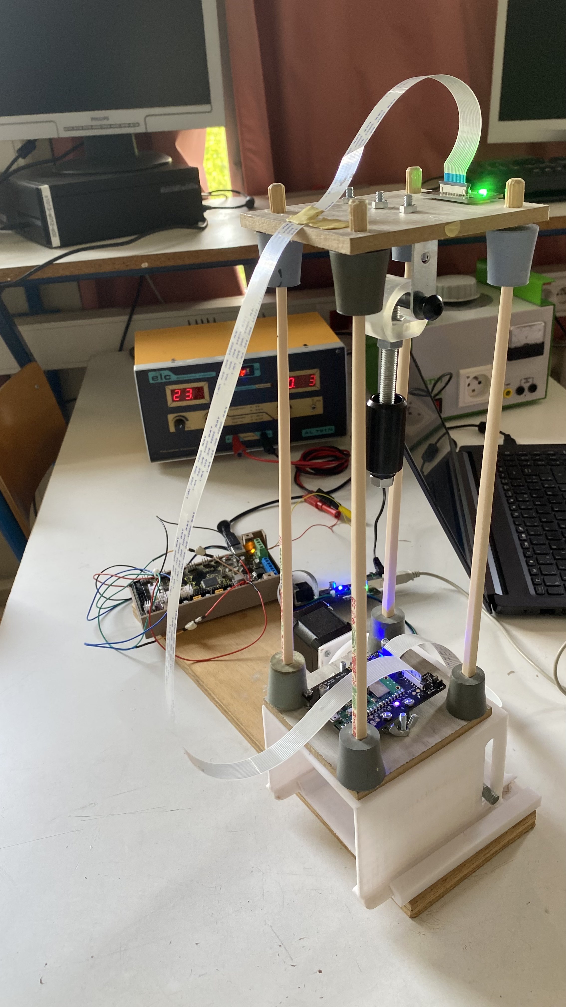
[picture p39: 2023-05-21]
Beamer/Image/Montage complet propre 3.jpg

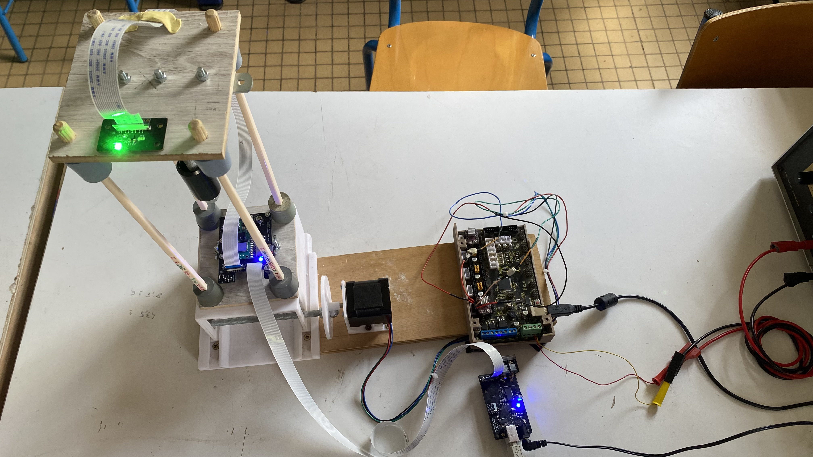
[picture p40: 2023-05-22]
Beamer/Image/Montage complet du dessus Plan.jpg

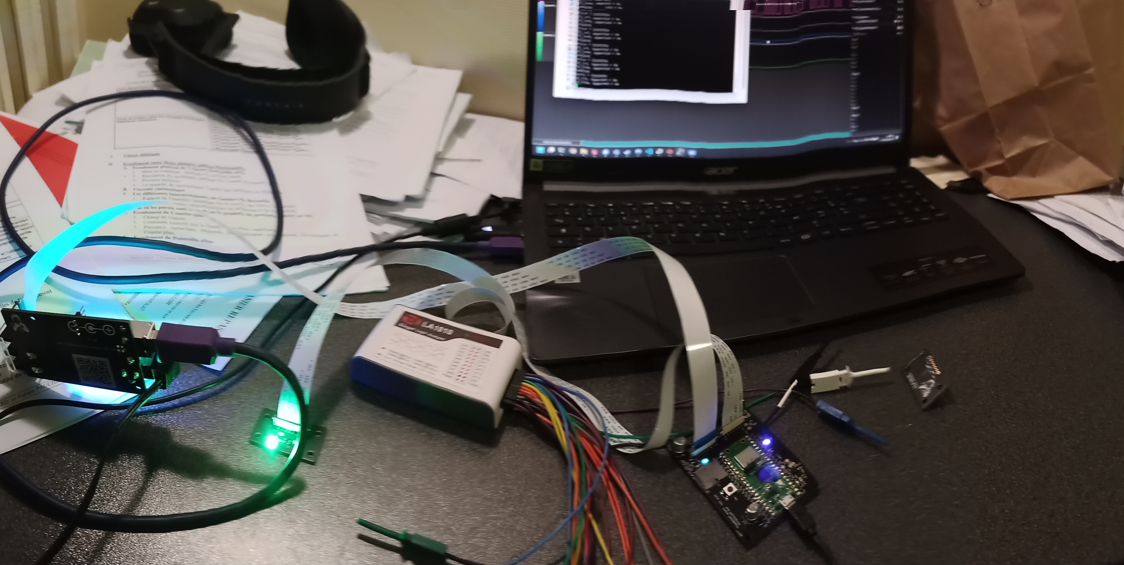
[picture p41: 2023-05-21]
Beamer/Image/Setup de Test des cartes.jpg

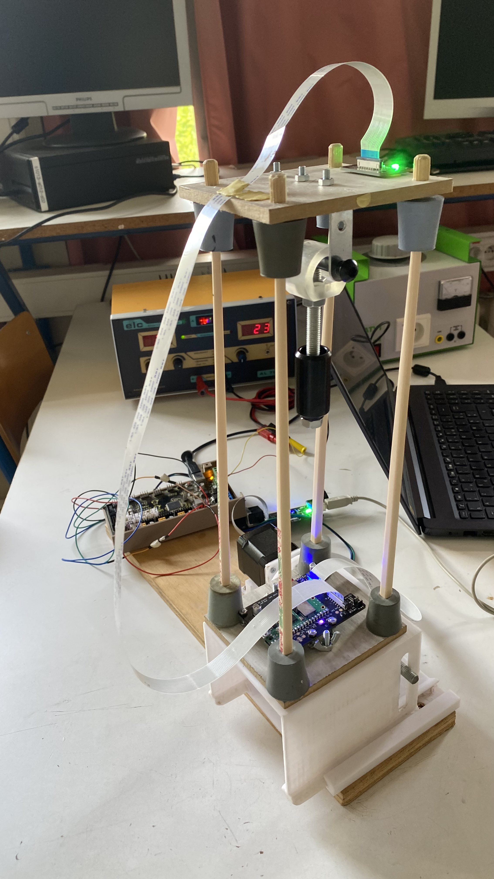
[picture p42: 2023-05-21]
Beamer/Image/Montage complet propre 9.jpg

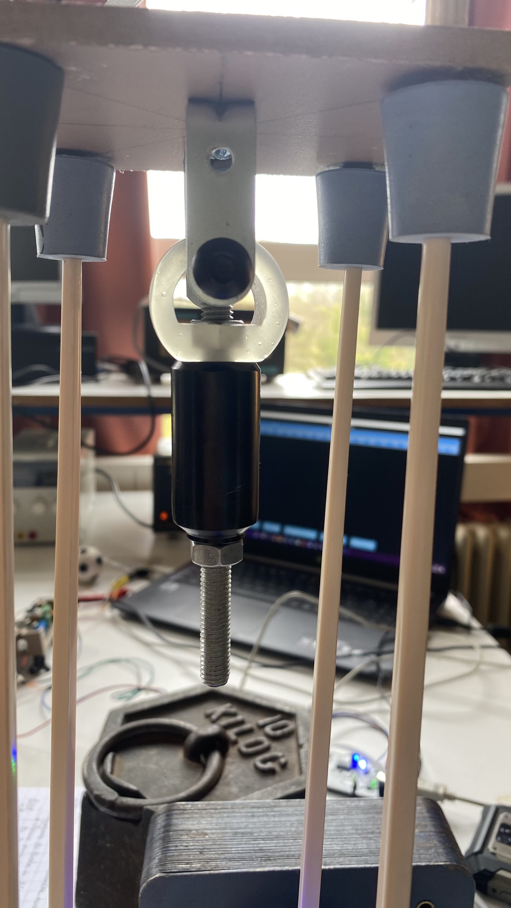
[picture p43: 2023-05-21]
Beamer/Image/Montage complet profil peu lisible masse milieu.jpg

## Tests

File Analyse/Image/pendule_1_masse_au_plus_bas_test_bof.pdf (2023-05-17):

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

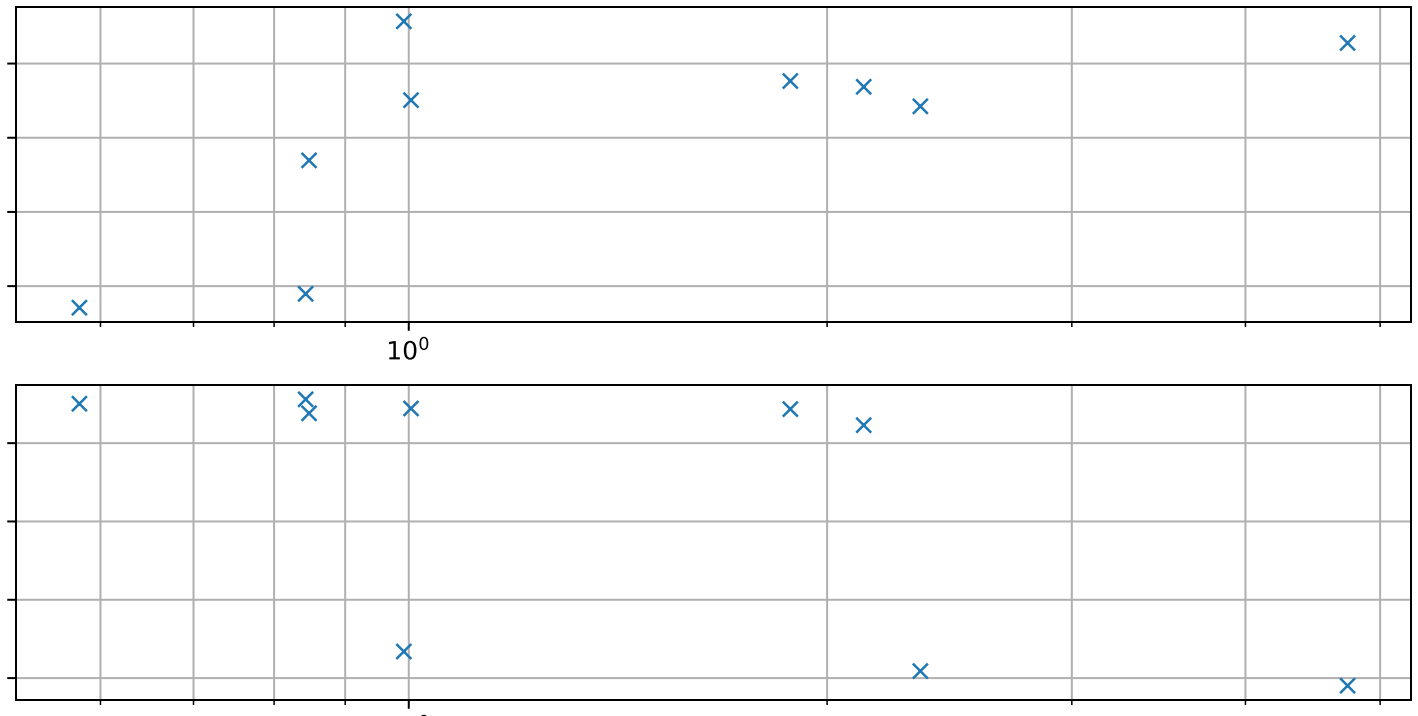
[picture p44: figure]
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

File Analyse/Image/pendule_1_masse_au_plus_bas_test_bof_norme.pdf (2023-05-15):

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

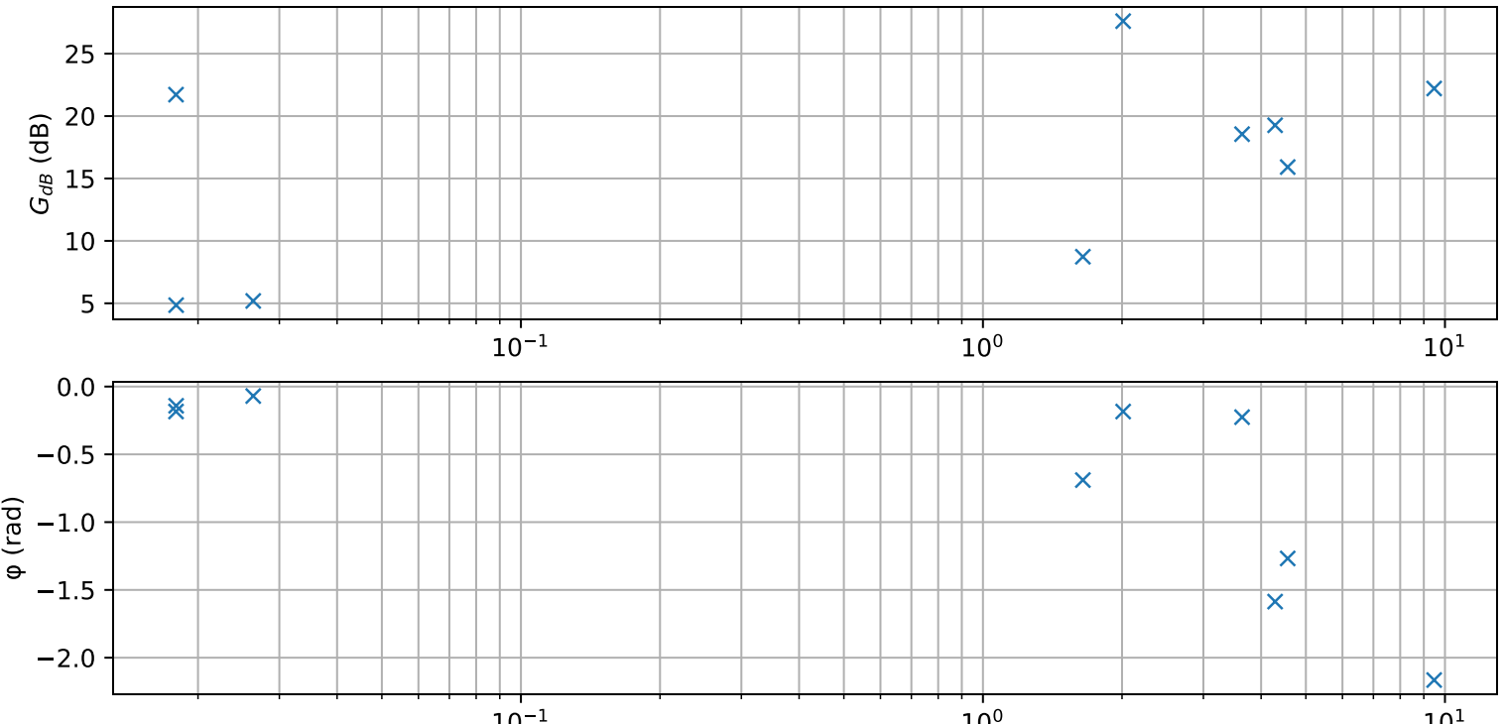
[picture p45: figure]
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

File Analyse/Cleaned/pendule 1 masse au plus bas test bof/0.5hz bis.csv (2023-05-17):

2.582816530000000000e+08 | -3.659580635727905928e-01 | -2.317099809281586431e-01 | -6.437941812880227342e+06 | -9.965425301970758376e-01 | -2.699899554990459194e-01 | nan
2.582895240000000000e+08 | -3.659580635727905928e-01 | -2.317099809281586431e-01 | -6.437941812880227342e+06 | -9.965425301970758376e-01 | -2.699899554990459194e-01 | nan
2.582952330000000000e+08 | -3.659580635727905928e-01 | -2.317099809281586431e-01 | -6.437941812880227342e+06 | -9.965425301970758376e-01 | -1.479899554990460331e-01 | nan
2.583000610000000000e+08 | -3.659580635727905928e-01 | -2.317099809281586431e-01 | -6.437941812880227342e+06 | -9.965425301970758376e-01 | -1.479899554990460331e-01 | nan
2.583057060000000000e+08 | -3.659580635727905928e-01 | -2.317099809281586431e-01 | -6.437941812880227342e+06 | -8.745425301970759513e-01 | -1.479899554990460331e-01 | nan
2.583113400000000000e+08 | -3.659580635727905928e-01 | -2.317099809281586431e-01 | -6.437941812880227342e+06 | -8.745425301970759513e-01 | -1.479899554990460331e-01 | nan
2.583178980000000000e+08 | -3.659580635727905928e-01 | -2.317099809281586431e-01 | -6.437941934880226851e+06 | -8.745425301970759513e-01 | -1.479899554990460331e-01 | nan
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

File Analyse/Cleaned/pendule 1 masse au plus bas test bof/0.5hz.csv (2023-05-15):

1.717173324000000000e+09 | 1.209630786871146668e+00 | 4.154679661745745989e-01 | 3.149757775547641359e-01 | -5.063952988390418852e-02 | -2.793637379962737199e+00 | 4.931725383403318119e-01
1.717178871000000000e+09 | 1.209630786871146668e+00 | 2.934679661745747126e-01 | 3.149757775547641359e-01 | -5.063952988390418852e-02 | -2.793637379962737199e+00 | 4.931725383403318119e-01
1.717186656000000000e+09 | 1.209630786871146668e+00 | 1.714679661745748263e-01 | 3.149757775547641359e-01 | -5.063952988390418852e-02 | -2.915637379962737086e+00 | 6.151725383402890657e-01
1.717192280000000000e+09 | 1.209630786871146668e+00 | 1.714679661745748263e-01 | 3.149757775547641359e-01 | -5.063952988390418852e-02 | -3.037637379962736972e+00 | 6.151725383402890657e-01
1.717197014000000000e+09 | 1.331630786871146555e+00 | 4.946796617457493994e-02 | 3.149757775547641359e-01 | -5.063952988390418852e-02 | -3.037637379962736972e+00 | 6.151725383402890657e-01
1.717202575000000000e+09 | 1.331630786871146555e+00 | 4.946796617457493994e-02 | 3.149757775547641359e-01 | -5.063952988390418852e-02 | -3.037637379962736972e+00 | 4.931725383403318119e-01
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

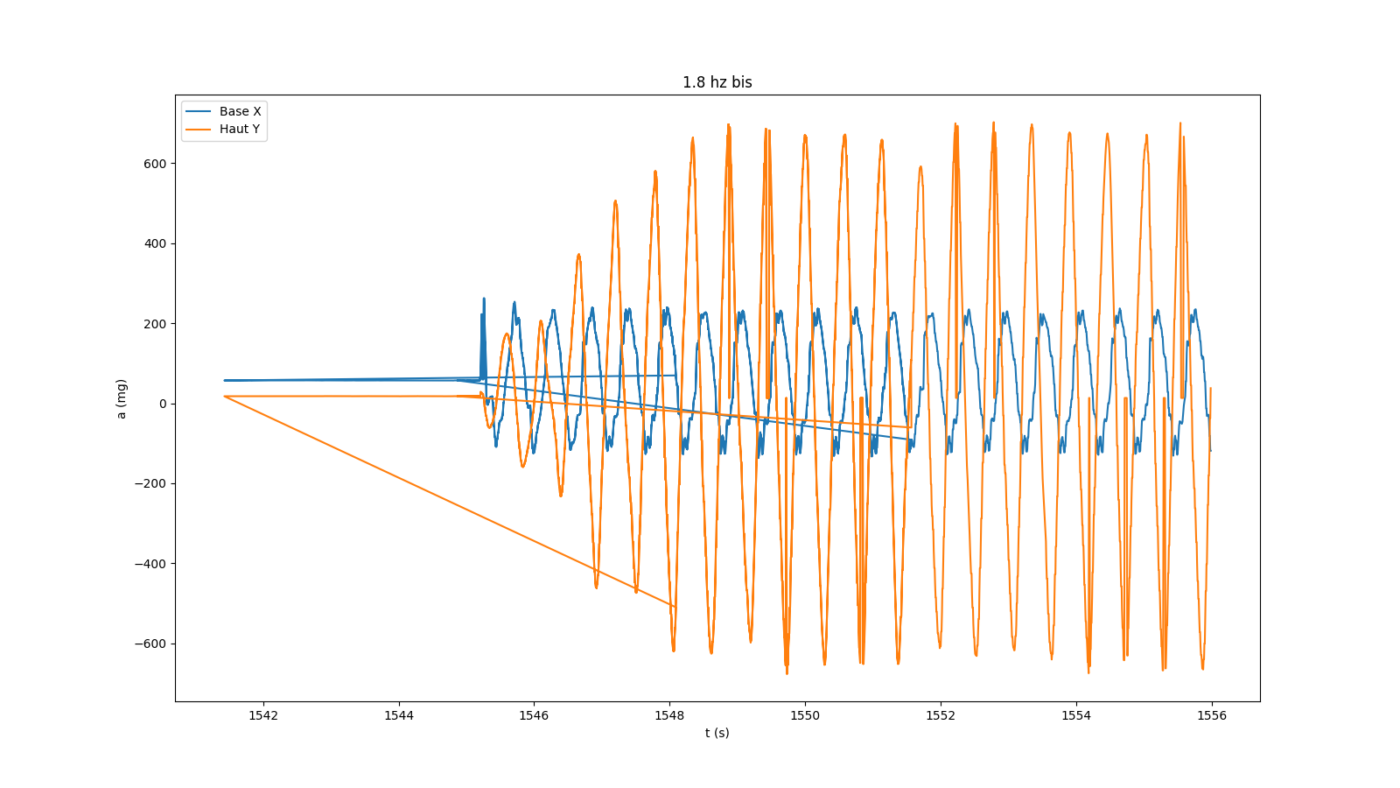
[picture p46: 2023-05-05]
Analyse/Image/pendule 1 masse au plus bas test bof/1.8 hz bis.png

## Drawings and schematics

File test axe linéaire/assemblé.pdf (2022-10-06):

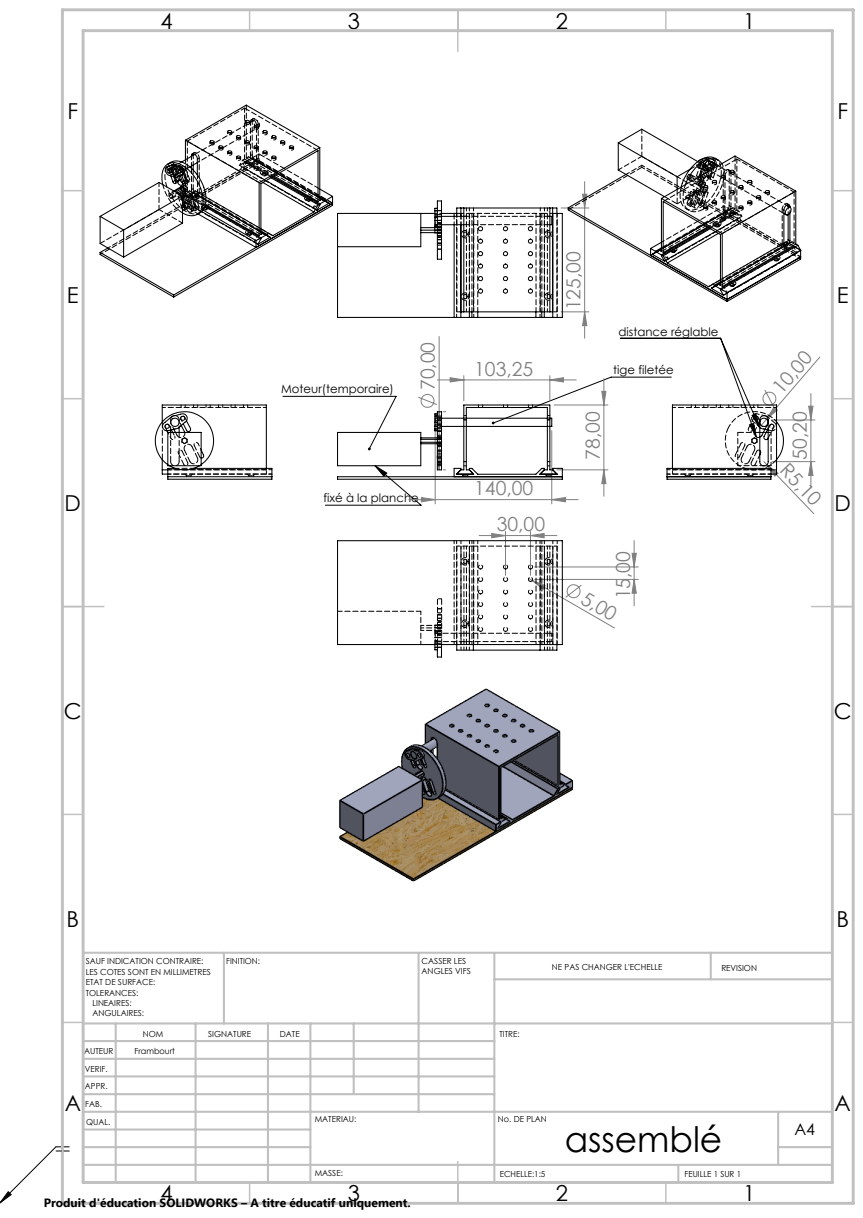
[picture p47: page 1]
tige filetée; distance réglable; FINITION:; CASSER LES; ANGLES VIFS; NE PAS CHANGER L'ECHELLE; REVISION; ECHELLE:1:5; FEUILLE 1 SUR 1

fixé à la planche

SAUF INDICATION CONTRAIRE:
LES COTES SONT EN MILLIMETRES
ETAT DE SURFACE:
TOLERANCES:
LINEAIRES:
ANGULAIRES:

NOM | SIGNATURE | DATE | | | | TITRE:

AUTEUR | Frambourt
VERIF.
APPR.
FAB.
QUAL. | | | | MATERIAU: | No. DE PLAN assemblé | A4

Produit d'éducation SOLIDWORKS – A titre éducatif uniquement.

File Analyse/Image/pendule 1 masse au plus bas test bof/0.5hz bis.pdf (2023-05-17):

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

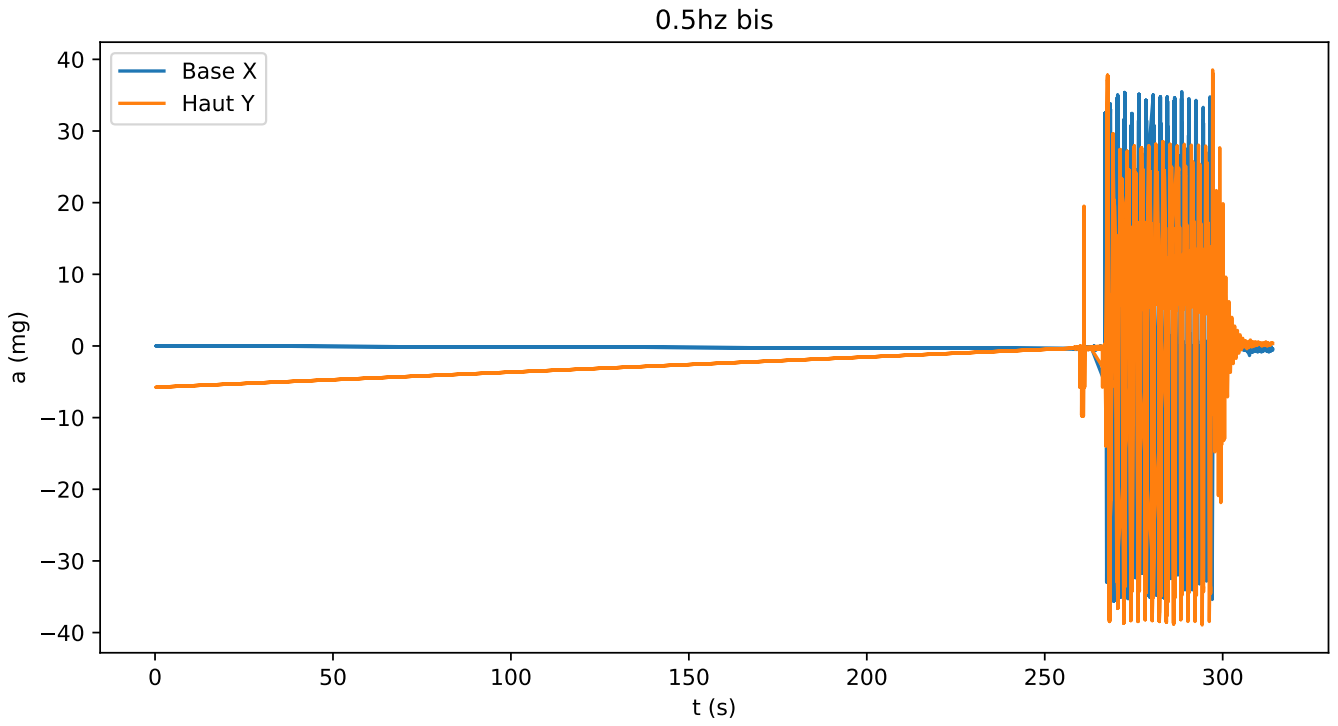
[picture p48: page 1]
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

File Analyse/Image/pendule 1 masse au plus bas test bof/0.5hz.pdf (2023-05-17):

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

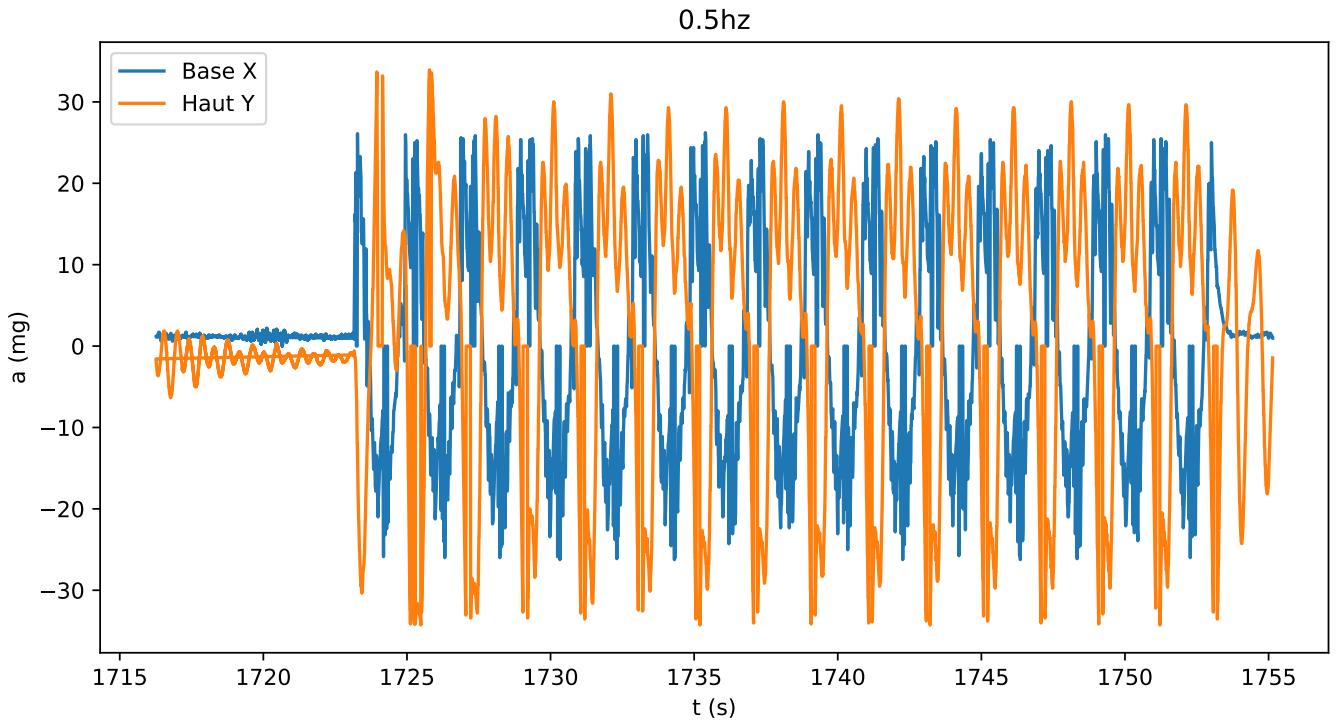
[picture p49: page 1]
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

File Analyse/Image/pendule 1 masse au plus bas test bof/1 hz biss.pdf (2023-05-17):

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

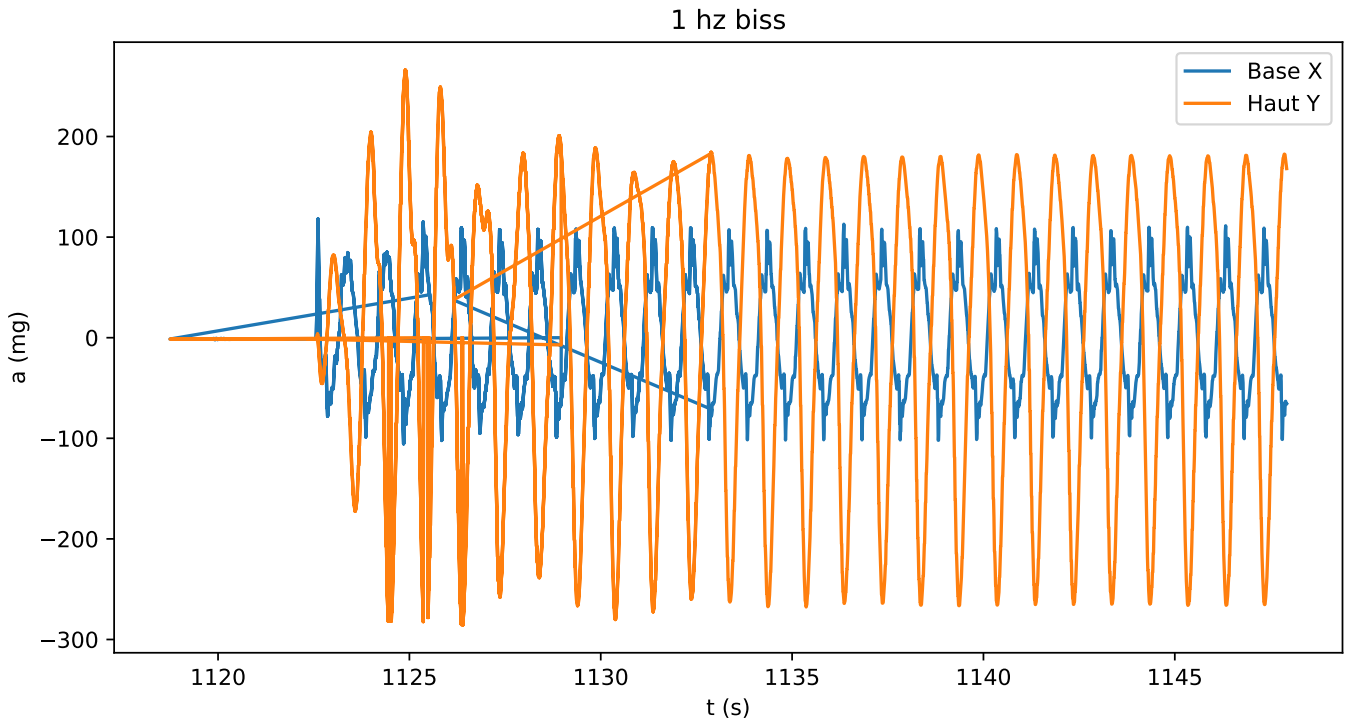
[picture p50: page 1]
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

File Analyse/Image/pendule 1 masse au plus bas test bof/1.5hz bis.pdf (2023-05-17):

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

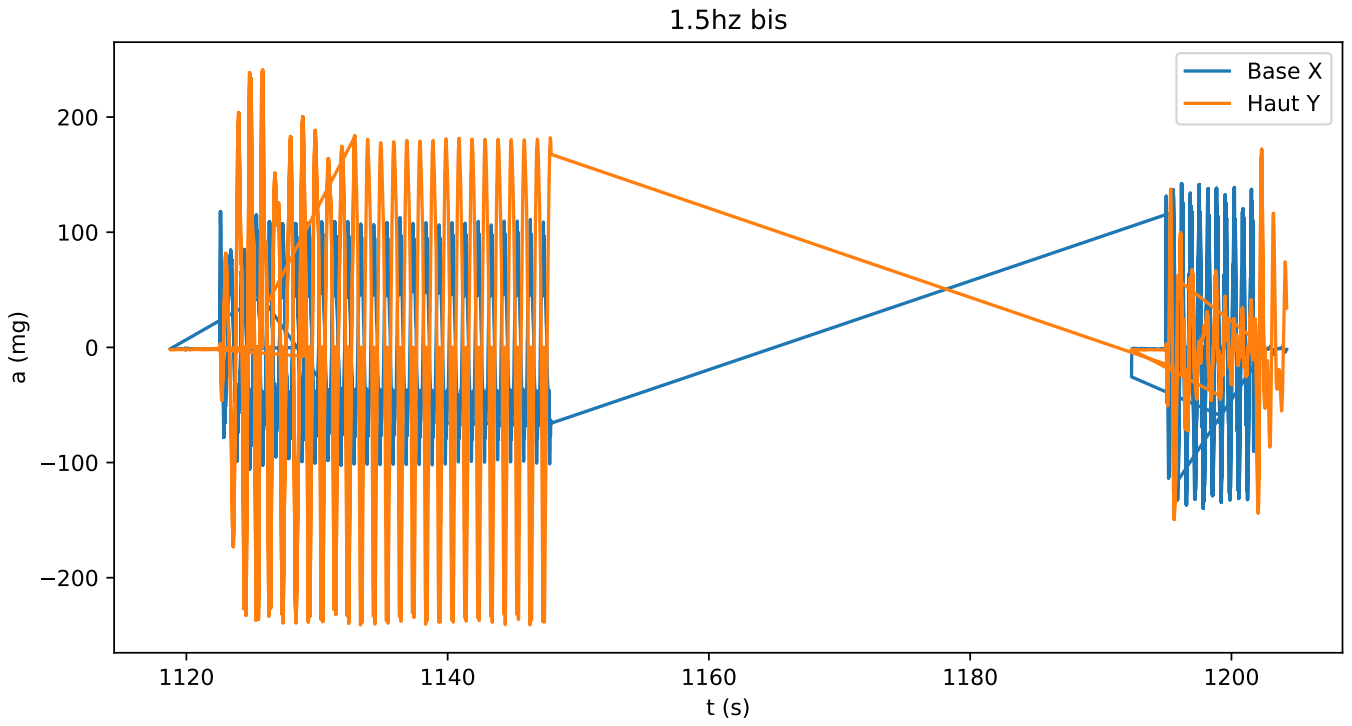
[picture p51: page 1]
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

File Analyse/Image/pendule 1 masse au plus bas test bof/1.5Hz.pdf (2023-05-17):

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

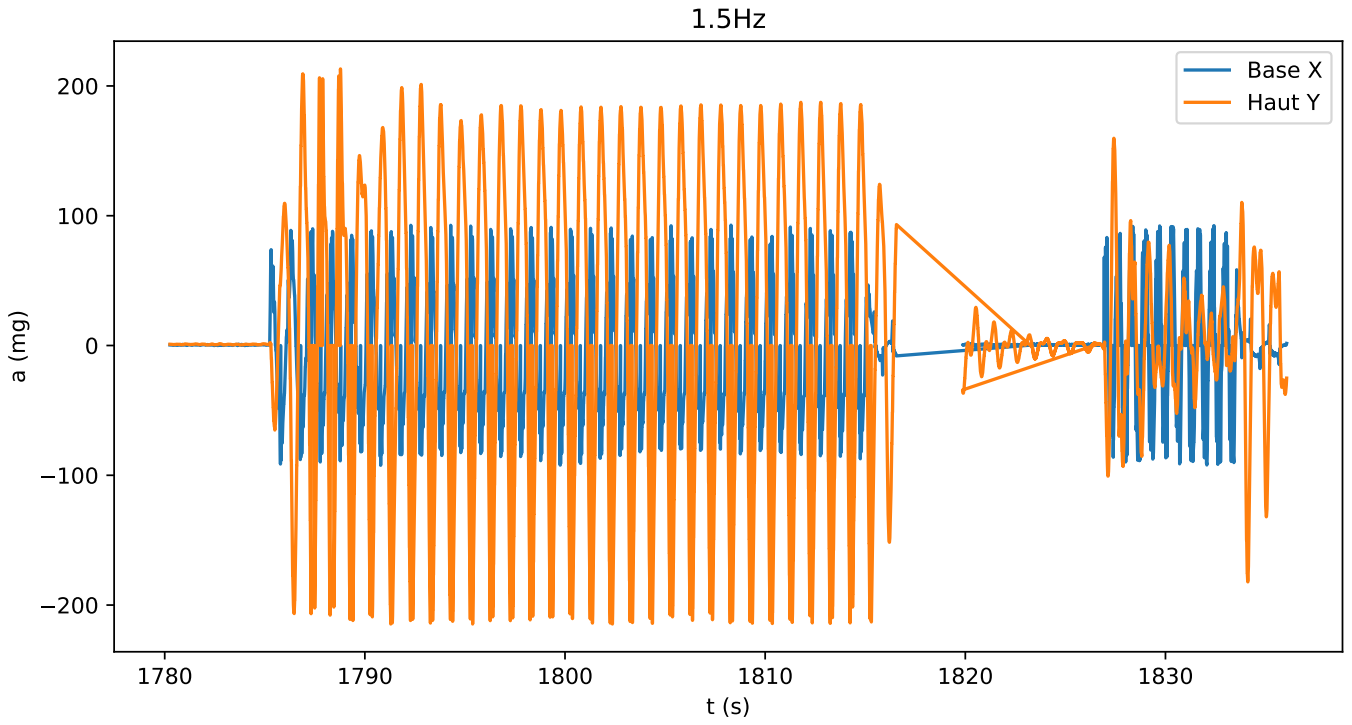
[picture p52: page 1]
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

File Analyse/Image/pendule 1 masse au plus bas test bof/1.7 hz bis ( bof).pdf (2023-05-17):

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

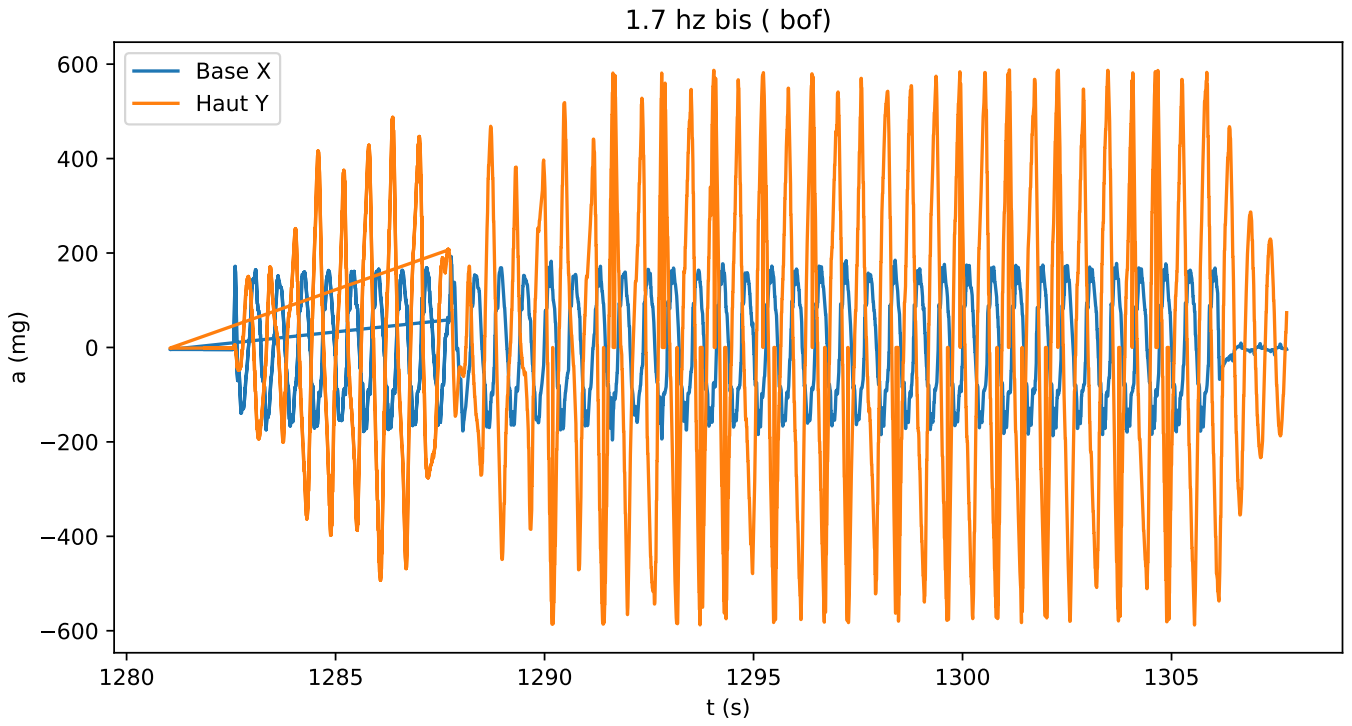
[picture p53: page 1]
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

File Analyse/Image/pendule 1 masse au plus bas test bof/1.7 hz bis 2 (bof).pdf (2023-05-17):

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

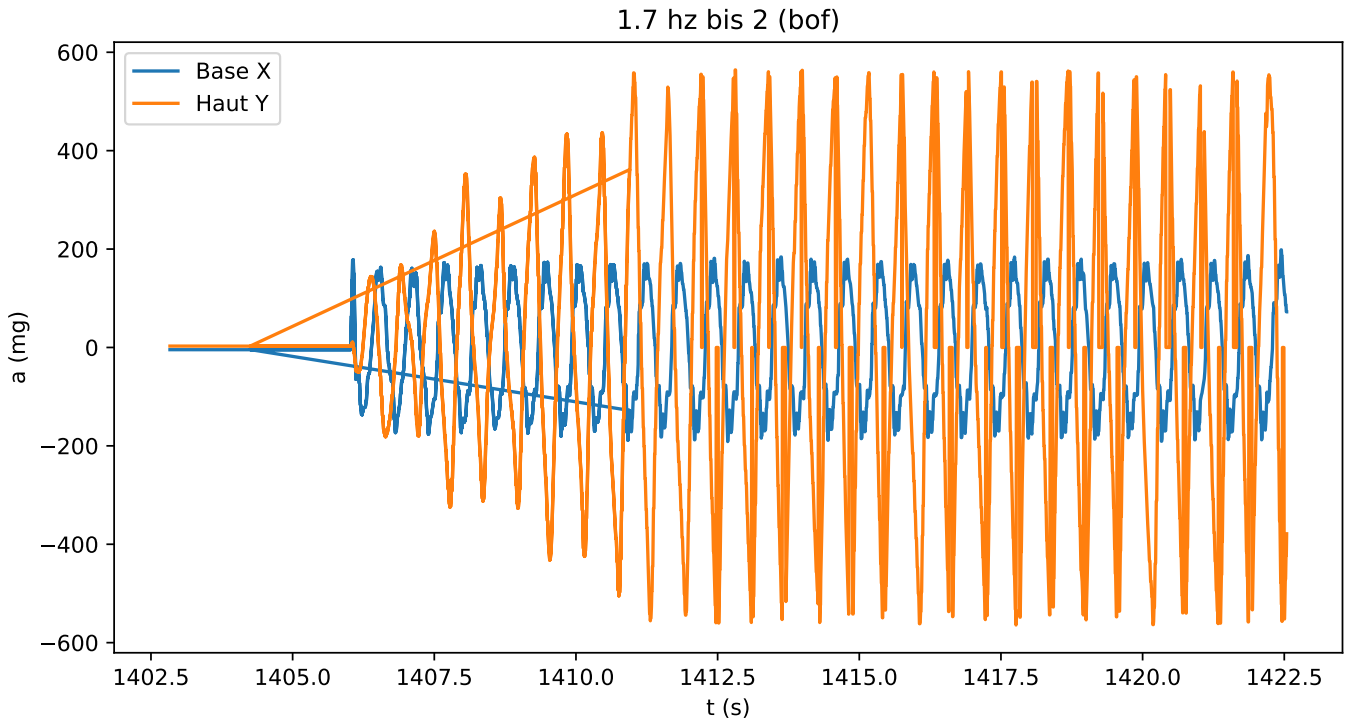
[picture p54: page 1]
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

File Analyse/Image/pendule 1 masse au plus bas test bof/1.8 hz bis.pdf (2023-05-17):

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

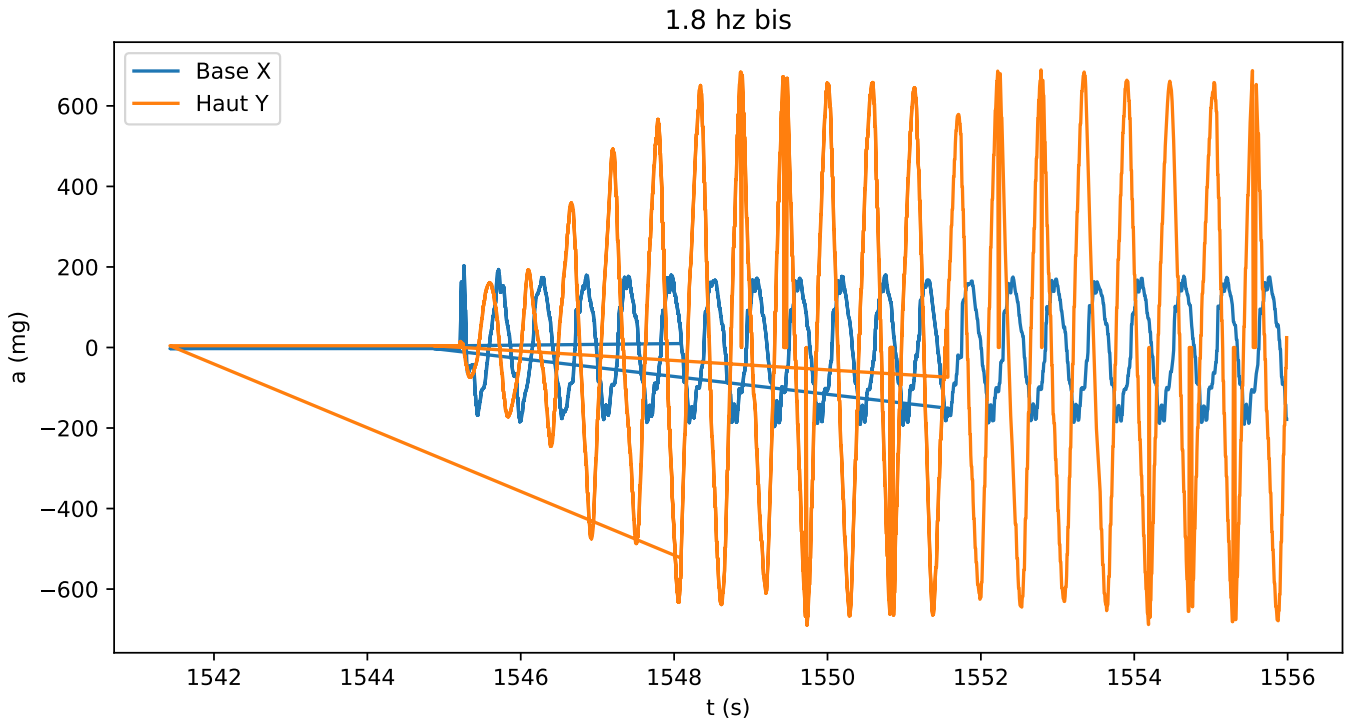
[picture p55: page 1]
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

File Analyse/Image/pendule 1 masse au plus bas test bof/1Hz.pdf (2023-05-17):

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

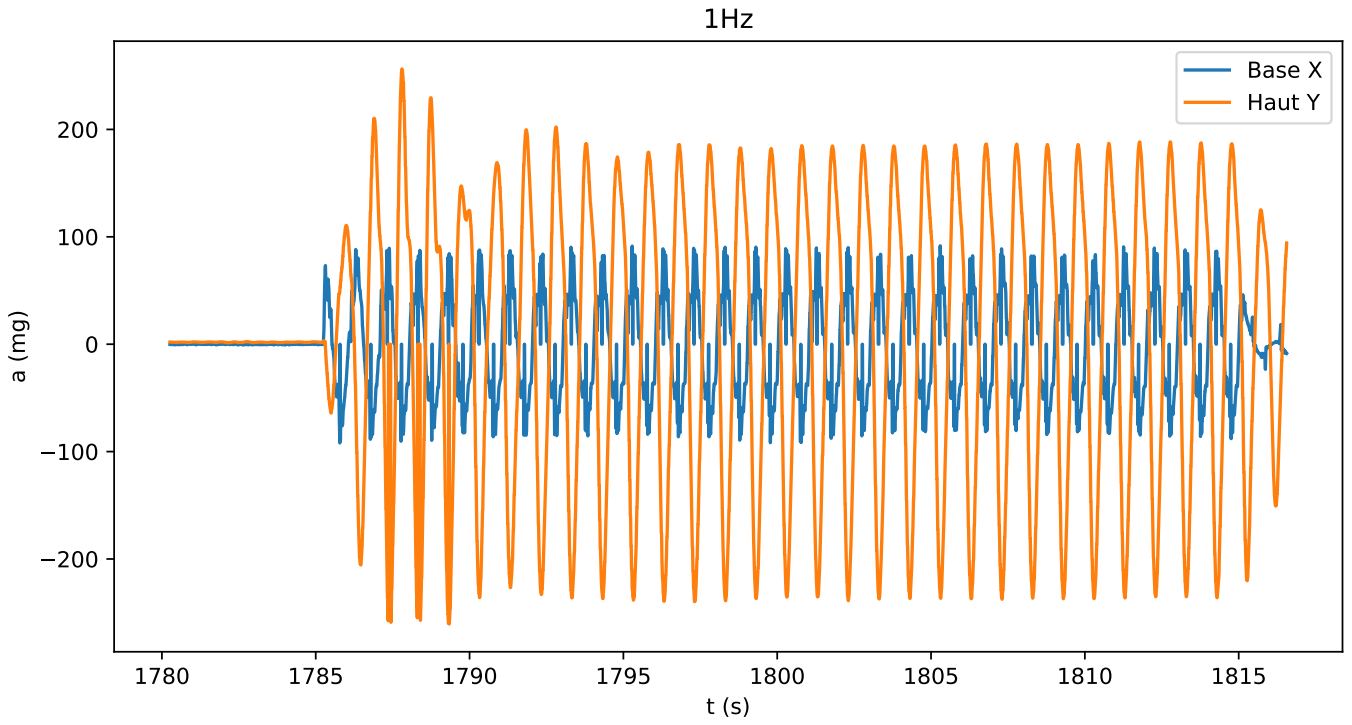
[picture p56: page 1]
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

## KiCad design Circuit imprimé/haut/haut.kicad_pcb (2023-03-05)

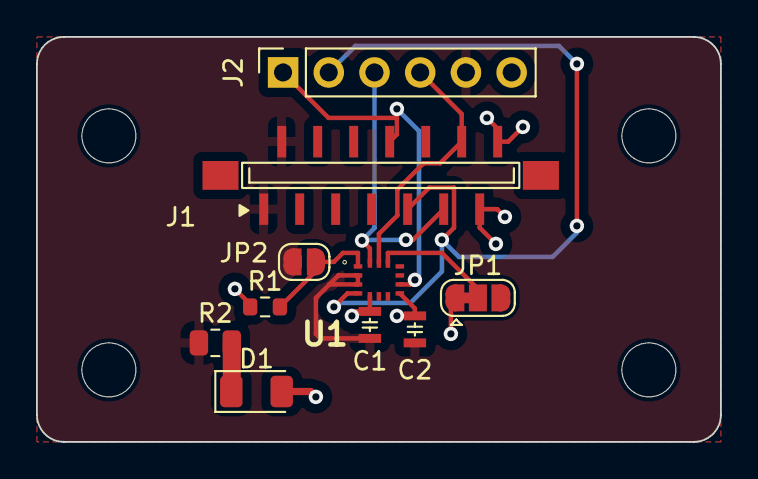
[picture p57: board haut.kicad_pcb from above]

Board: 2 copper layers, 38.0 x 22.5 mm, 10 parts (0 on the bottom side), 9 nets.

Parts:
C1, C2: 100n; Cap 100nf 0805
D1: LED; LED_1206_3216Metric
J1: Conn_01x14_Shielded; FPC 2x7 p=1mm
J2: Conn_01x06_Male; PinSocket_1x06_P2.54mm_Vertical
JP1: SolderJumper_3_Bridged12; SolderJumper-3_P1.3mm_Bridged12_RoundedPad1.0x1.5mm
JP2: SolderJumper_2_Open; SolderJumper-2_P1.3mm_Open_RoundedPad1.0x1.5mm
R1: 10k; R_0603_1608Metric
R2: 30; R_0805_2012Metric
U1: LSM6DSRTR; LGA-14_2.5X3X0.86_

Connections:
+3V3: C1.1, C2.1, D1.2 (A), J1.13, J1.14, J2.6, JP1.1 (A), R1.1, U1.5 (VDD_IO), U1.8 (VDD)
GND: C1.2, C2.2, J1.1, J1.2, J2.5, JP2.2 (B), R2.1, U1.2 (SDX_), U1.3 (SCX)
INT1_Haut: J1.9, J2.2, U1.4 (INT1)
INT2_Haut: J1.8, J2.1, U1.9 (INT2)
unnamed: D1.1 (K), R2.2
unnamed: JP1.2 (C), U1.12 (CS)
unnamed: JP2.1 (A), R1.2, U1.1 (SDO/SA0)
SCL: J1.12, J2.4, U1.13 (SCL)
SDA: J1.11, J2.3, U1.14 (SDA)

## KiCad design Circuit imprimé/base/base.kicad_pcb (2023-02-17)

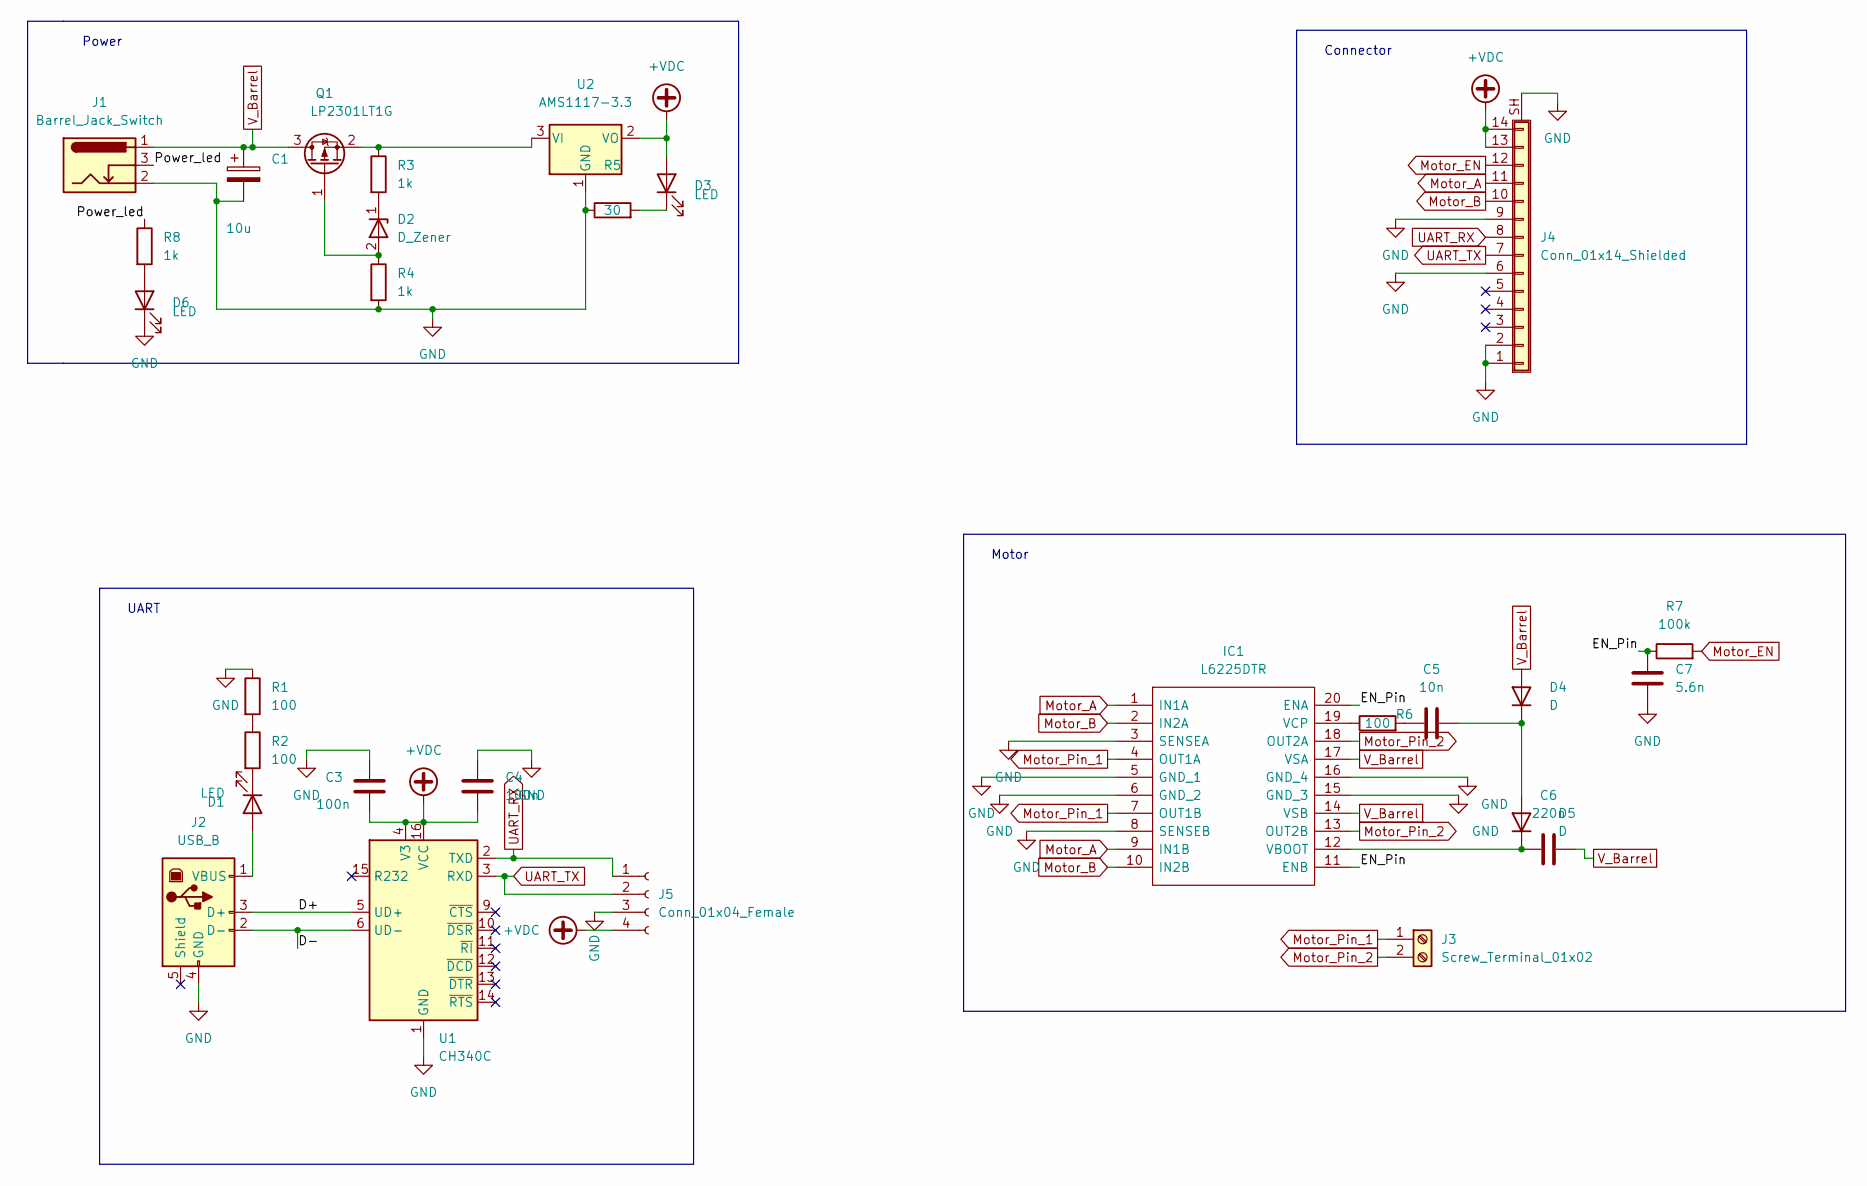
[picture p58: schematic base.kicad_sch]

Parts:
C1: 10u; CP_Elec_6.3x7.7
C3, C4: 100n; Cap 100nf 0805
C5: 10n; C_0805_2012Metric
C6: 220n; C_0805_2012Metric
C7: 5.6n; C_0603_1608Metric
D1, D3, D6: LED; LED_1206_3216Metric
D2: D_Zener; SOD223
D4, D5: D; D_SOD-323
IC1: L6225DTR; Mouser Part Number 511-L6225DTR
J1: Barrel_Jack_Switch; BarrelJack_GCT_DCJ200-10-A_Horizontal
J2: USB_B; USB_B_OST_USB-B1HSxx_Horizontal
J3: Screw_Terminal_01x02; TerminalBlock_Dinkle_DT-55-B01X-02_P10.00mm
J4: Conn_01x14_Shielded; FPC 2x7 p=1mm
J5: Conn_01x04_Female; PinSocket_1x04_P2.54mm_Horizontal
Q1: LP2301LT1G; SOT-23
R1, R2, R6: 100; R_0603_1608Metric
R3, R4, R8: 1k; R_0603_1608Metric
R5: 30; R_0805_2012Metric
R7: 100k; R_0603_1608Metric
U1: CH340C; SOIC-16_3.9x9.9mm_P1.27mm
U2: AMS1117-3.3; SOT-223-3_TabPin2

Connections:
+VDC: C3.2, C4.1, D3.2 (A), J4.13, J4.14, J5.4, U1.4 (V3), U1.16 (VCC), U2.2 (VO)
/D+: J2.3 (D+), U1.5 (UD+)
/D-: J2.2 (D-), U1.6 (UD-)
/EN_Pin: C7.2, IC1.11 (ENB), IC1.20 (ENA), R7.1
/Power_led: J1.3, R8.1
GND: C1.2, C3.1, C4.2, C7.1, D6.1 (K), IC1.3 (SENSEA), IC1.5 (GND_1), IC1.6 (GND_2), IC1.8 (SENSEB), IC1.15 (GND_3), IC1.16 (GND_4), J1.2, J2.4 (GND), J4.1, J4.2, J4.6, J4.9, J4.SH (Shield), J5.3, R1.1, R4.2, R5.1, U1.1 (GND), U2.1 (GND)
Motor_A: IC1.1 (IN1A), IC1.9 (IN1B), J4.11
Motor_B: IC1.2 (IN2A), IC1.10 (IN2B), J4.10
Motor_EN: J4.12, R7.2
Motor_Pin_1: IC1.4 (OUT1A), IC1.7 (OUT1B), J3.1
Motor_Pin_2: IC1.13 (OUT2B), IC1.18 (OUT2A), J3.2
unnamed: C5.1, R6.2
unnamed: C5.2, D4.1 (K), D5.2 (A)
unnamed: C6.1, D5.1 (K), IC1.12 (VBOOT)
unnamed: D1.1 (K), R2.2
unnamed: D1.2 (A), J2.1 (VBUS)
unnamed: D2.1 (K), R3.2
unnamed: D2.2 (A), Q1.1 (G), R4.1
unnamed: D3.1 (K), R5.2
unnamed: D6.2 (A), R8.2
unnamed: IC1.19 (VCP), R6.1
unnamed: Q1.2 (S), R3.1, U2.3 (VI)
unnamed: R1.2, R2.1
UART_RX: J4.8, J5.1, U1.2 (TXD)
UART_TX: J4.7, J5.2, U1.3 (RXD)
V_Barrel: C1.1, C6.2, D4.2 (A), IC1.14 (VSB), IC1.17 (VSA), J1.1, Q1.3 (D)

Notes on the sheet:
Power
Motor
UART
Connector

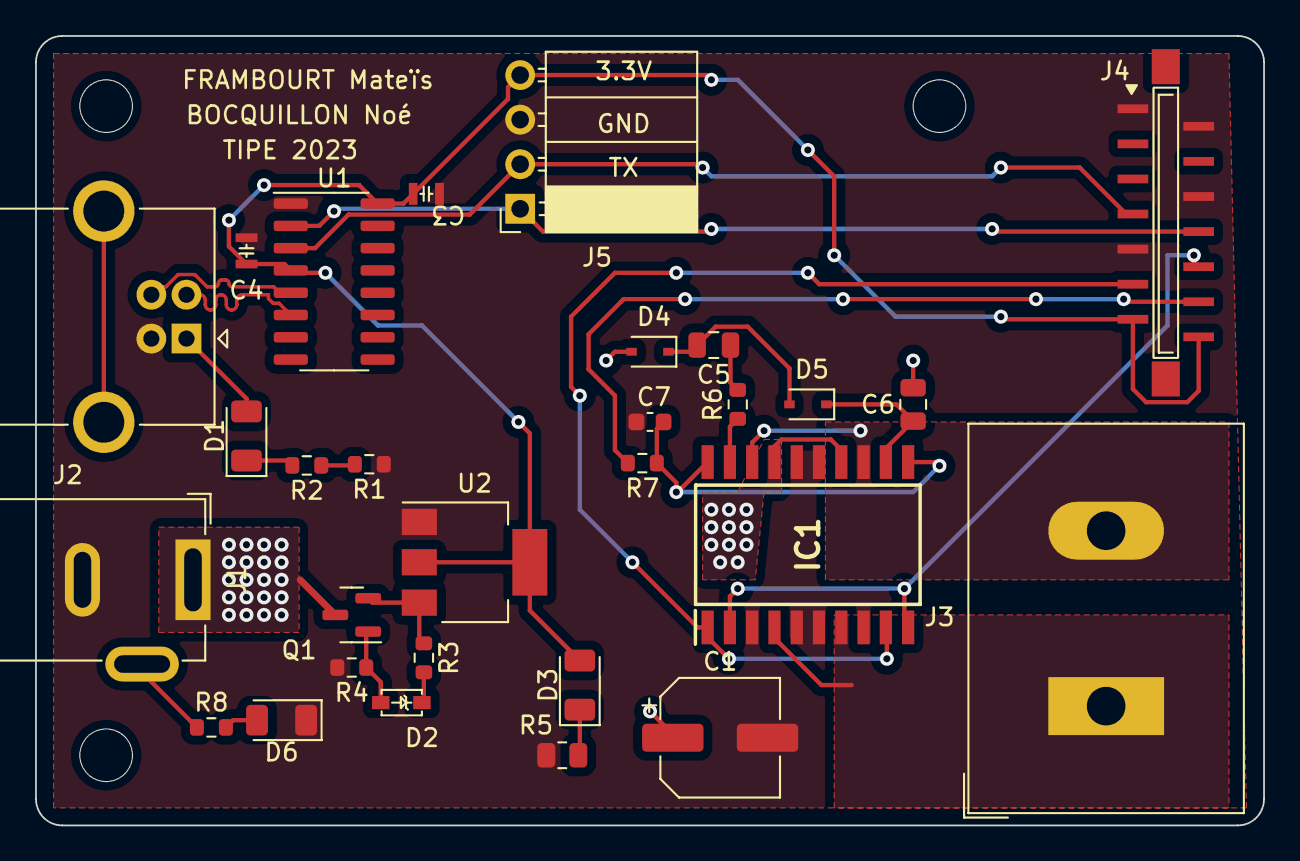
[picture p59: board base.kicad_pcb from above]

Board: 2 copper layers, 70.0 x 45.0 mm, 29 parts (0 on the bottom side), 26 nets.

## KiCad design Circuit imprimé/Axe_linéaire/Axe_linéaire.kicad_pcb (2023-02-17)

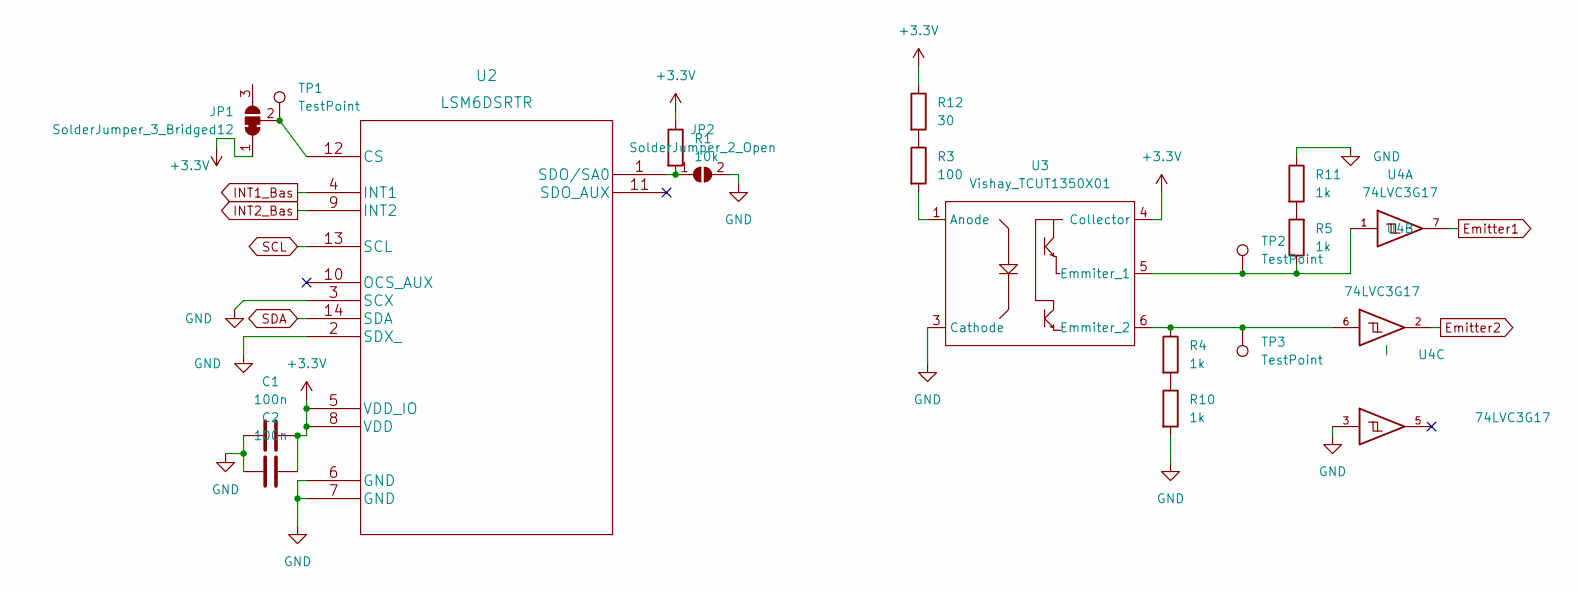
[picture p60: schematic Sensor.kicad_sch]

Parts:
C1, C2: 100n; Cap 100nf 0805
JP1: SolderJumper_3_Bridged12; SolderJumper-3_P1.3mm_Bridged12_RoundedPad1.0x1.5mm
JP2: SolderJumper_2_Open; SolderJumper-2_P1.3mm_Open_RoundedPad1.0x1.5mm
R1: 10k; R_0603_1608Metric
R3: 100; R_0603_1608Metric
R4, R5, R10, R11: 1k; R_0603_1608Metric
R12: 30; R_0805_2012Metric
TP1, TP2, TP3: TestPoint; TestPoint_Pad_D2.0mm
U2: LSM6DSRTR; LGA-14_2.5X3X0.86_
U3: Vishay_TCUT1350X01; Vishay TCUT1350X01
U4: 74LVC3G17; VSSOP-8_2.3x2mm_P0.5mm

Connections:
+3.3V: C1.1, C2.1, JP1.1 (A), R1.1, R12.1, U2.5 (VDD_IO), U2.8 (VDD), U3.4 (Collector), U4.8 (+3.3V); also elsewhere on the board
Emitter1: U4.7; also elsewhere on the board
Emitter2: U4.2; also elsewhere on the board
GND: C1.2, C2.2, JP2.2 (B), R10.2, R11.1, U2.2 (SDX_), U2.3 (SCX), U2.6 (GND), U2.7 (GND), U3.3 (Cathode), U4.3, U4.4 (GND); also elsewhere on the board
INT1_Bas: U2.4 (INT1); also elsewhere on the board
INT2_Bas: U2.9 (INT2); also elsewhere on the board
unnamed: JP1.2 (C), TP1.1, U2.12 (CS)
unnamed: JP2.1 (A), R1.2, U2.1 (SDO/SA0)
unnamed: R3.2, U3.1 (Anode)
unnamed: R4.1, TP3.1, U3.6 (Emmiter_2), U4.6
unnamed: R5.1, TP2.1, U3.5 (Emmiter_1), U4.1
unnamed: R4.2, R10.1
unnamed: R5.2, R11.2
unnamed: R3.1, R12.2
SCL: U2.13 (SCL); also elsewhere on the board
SDA: U2.14 (SDA); also elsewhere on the board

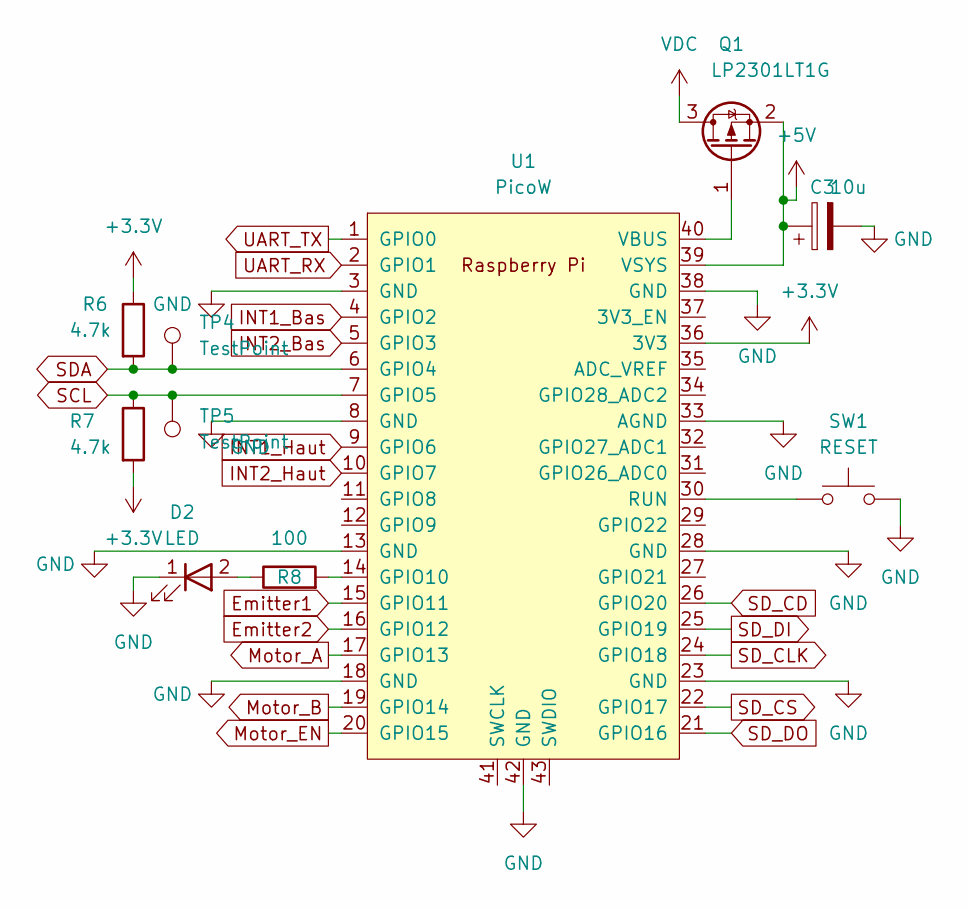
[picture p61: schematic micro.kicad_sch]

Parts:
C3: 10u; CP_Elec_6.3x7.7
D2: LED; UV_LED
Q1: LP2301LT1G; SOT-23
R6, R7: 4.7k; R_0603_1608Metric
R8: 100; R_0603_1608Metric
SW1: RESET; Tactile Button
TP4, TP5: TestPoint; TestPoint_Pad_D2.0mm
U1: PicoW; RPi_PicoW_SMD_TH

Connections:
+3.3V: R6.1, R7.2, U1.36 (3V3); also elsewhere on the board
+5V: C3.1, Q1.2 (S), U1.39 (VSYS)
Emitter1: U1.15 (GPIO11); also elsewhere on the board
Emitter2: U1.16 (GPIO12); also elsewhere on the board
GND: C3.2, D2.1 (K), SW1.3 (B), SW1.4 (B), U1.3 (GND), U1.8 (GND), U1.13 (GND), U1.18 (GND), U1.23 (GND), U1.28 (GND), U1.33 (AGND), U1.38 (GND), U1.42 (GND); also elsewhere on the board
INT1_Bas: U1.4 (GPIO2); also elsewhere on the board
INT1_Haut: U1.9 (GPIO6); also elsewhere on the board
INT2_Bas: U1.5 (GPIO3); also elsewhere on the board
INT2_Haut: U1.10 (GPIO7); also elsewhere on the board
Motor_A: U1.17 (GPIO13); also elsewhere on the board
Motor_B: U1.19 (GPIO14); also elsewhere on the board
Motor_EN: U1.20 (GPIO15); also elsewhere on the board
unnamed: D2.2 (A), R8.1
unnamed: Q1.1 (G), U1.40 (VBUS)
unnamed: R8.2, U1.14 (GPIO10)
unnamed: SW1.1 (A), SW1.2 (A), U1.30 (RUN)
SCL: R7.1, TP5.1, U1.7 (GPIO5); also elsewhere on the board
SDA: R6.2, TP4.1, U1.6 (GPIO4); also elsewhere on the board
SD_CD: U1.26 (GPIO20); also elsewhere on the board
SD_CLK: U1.24 (GPIO18); also elsewhere on the board
SD_CS: U1.22 (GPIO17); also elsewhere on the board
SD_DI: U1.25 (GPIO19); also elsewhere on the board
SD_DO: U1.21 (GPIO16); also elsewhere on the board
UART_RX: U1.2 (GPIO1); also elsewhere on the board
UART_TX: U1.1 (GPIO0); also elsewhere on the board
VDC: Q1.3 (D); also elsewhere on the board

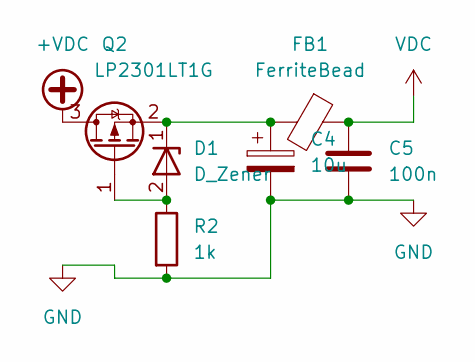
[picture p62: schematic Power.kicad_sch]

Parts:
C4: 10u; CP_Elec_6.3x7.7
C5: 100n; Cap 100nf 0805
D1: D_Zener; SOD223
FB1: FerriteBead; ferrite Bead
Q2: LP2301LT1G; SOT-23
R2: 1k; R_0603_1608Metric

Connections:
+VDC: Q2.3 (D); also elsewhere on the board
GND: C4.2, C5.2, R2.2; also elsewhere on the board
unnamed: C4.1, D1.1 (K), FB1.2, Q2.2 (S)
unnamed: D1.2 (A), Q2.1 (G), R2.1
VDC: C5.1, FB1.1; also elsewhere on the board

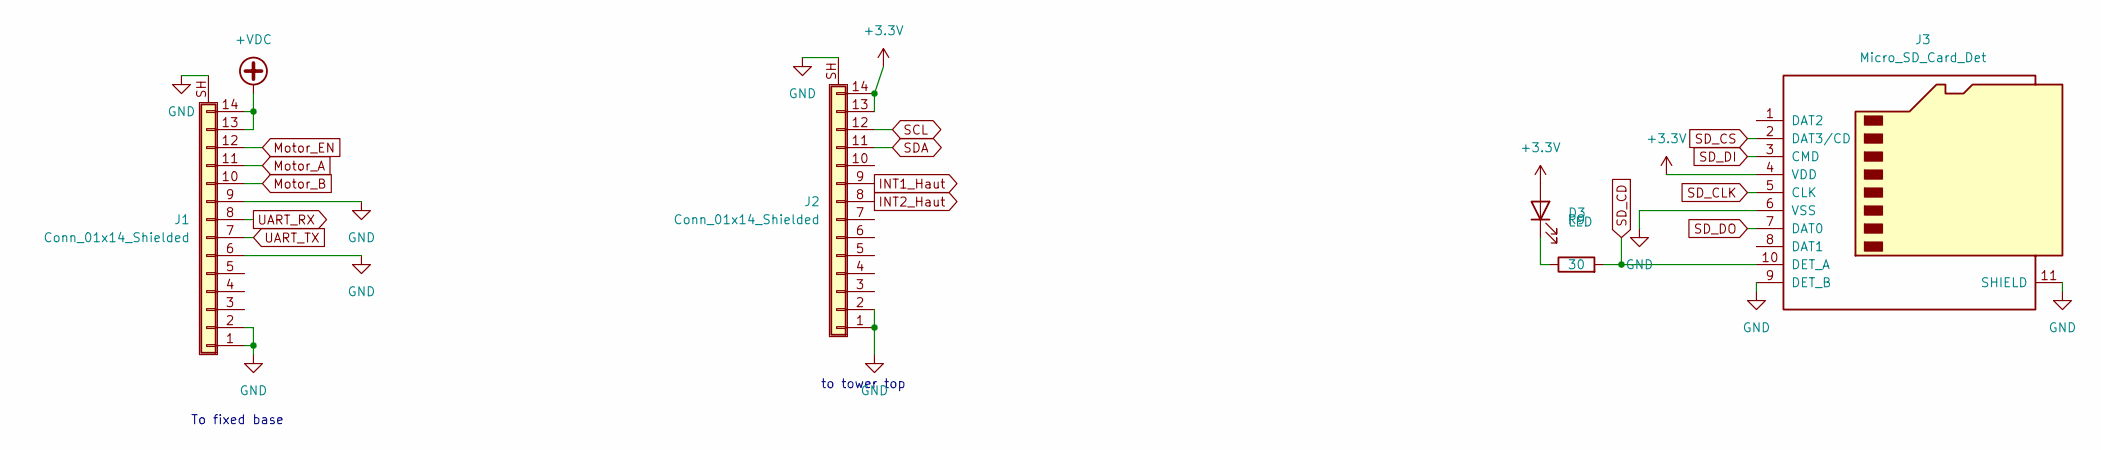
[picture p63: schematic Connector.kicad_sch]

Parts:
D3: LED; LED_1206_3216Metric
J1, J2: Conn_01x14_Shielded; FPC 2x7 p=1mm
J3: Micro_SD_Card_Det; microSD_HC_Hirose_DM3AT-SF-PEJM5
R9: 30; R_0805_2012Metric

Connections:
+3.3V: D3.2 (A), J2.13, J2.14, J3.4 (VDD); also elsewhere on the board
+VDC: J1.13, J1.14; also elsewhere on the board
GND: J1.1, J1.2, J1.6, J1.9, J1.SH (Shield), J2.1, J2.2, J2.SH (Shield), J3.6 (VSS), J3.9 (DET_B), J3.11 (SHIELD); also elsewhere on the board
INT1_Haut: J2.9; also elsewhere on the board
INT2_Haut: J2.8; also elsewhere on the board
Motor_A: J1.11; also elsewhere on the board
Motor_B: J1.10; also elsewhere on the board
Motor_EN: J1.12; also elsewhere on the board
unnamed: D3.1 (K), R9.1
SCL: J2.12; also elsewhere on the board
SDA: J2.11; also elsewhere on the board
SD_CD: J3.10 (DET_A), R9.2; also elsewhere on the board
SD_CLK: J3.5 (CLK); also elsewhere on the board
SD_CS: J3.2 (DAT3/CD); also elsewhere on the board
SD_DI: J3.3 (CMD); also elsewhere on the board
SD_DO: J3.7 (DAT0); also elsewhere on the board
UART_RX: J1.8; also elsewhere on the board
UART_TX: J1.7; also elsewhere on the board

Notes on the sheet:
To fixed base
to tower top

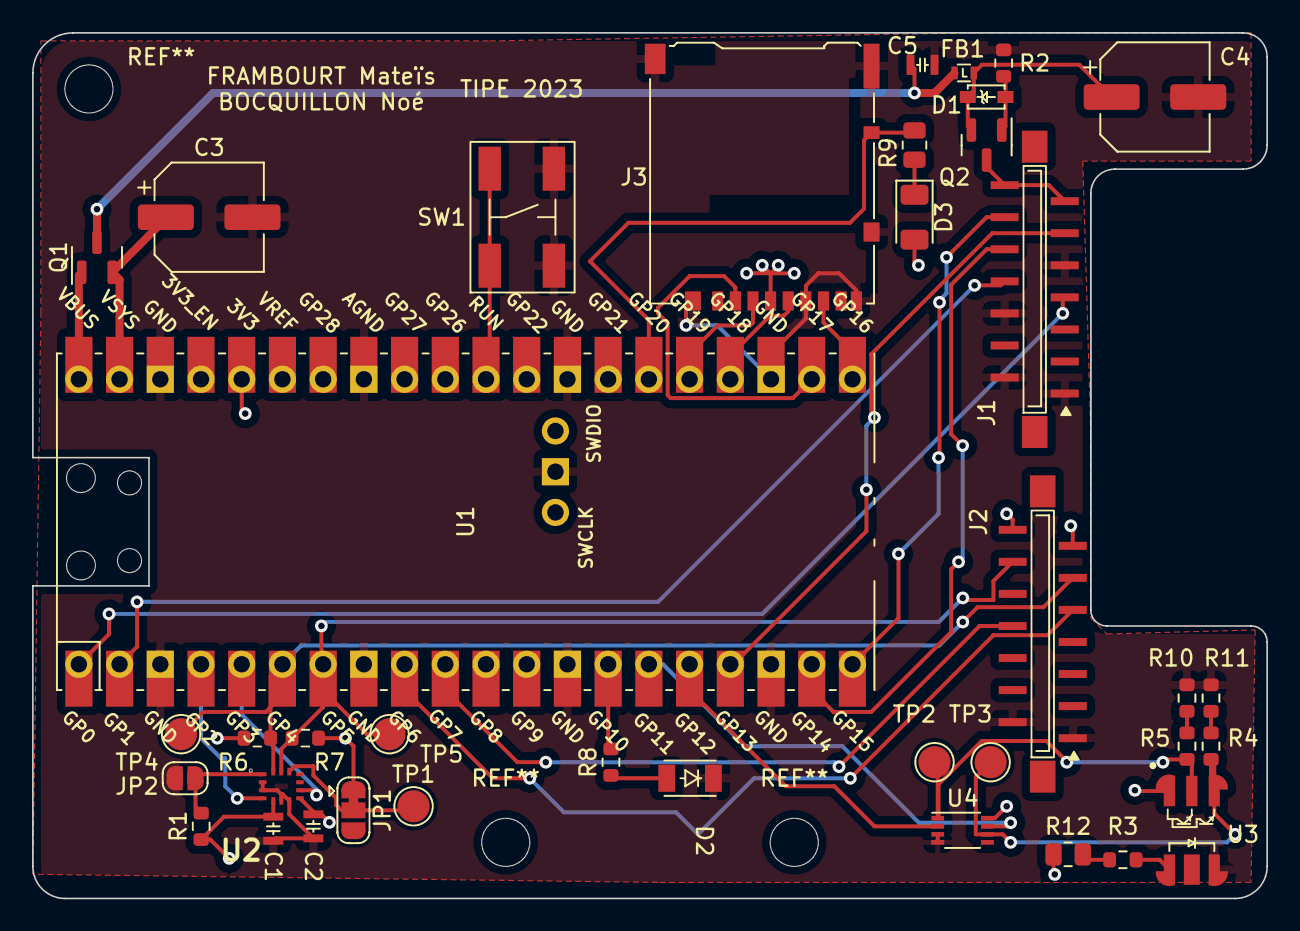
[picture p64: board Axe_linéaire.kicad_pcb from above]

Board: 2 copper layers, 77.0 x 54.0 mm, 38 parts (0 on the bottom side), 38 nets.

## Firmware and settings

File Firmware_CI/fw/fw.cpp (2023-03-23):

#include <stdio.h>
#include "pico/stdlib.h"
#include "hardware/spi.h"
#include "hardware/i2c.h"
#include "hardware/dma.h"
#include "hardware/pio.h"
#include "hardware/interp.h"
#include "hardware/timer.h"
#include "hardware/watchdog.h"
#include "hardware/clocks.h"
// #include "pico/cyw43_arch.h"
#include "pico/multicore.h"
#include "lsm6ds3tr-c_reg.h"
// #include "tusb.h"
#include "logging.h"
#include "PID.h"
#include "Motor_Control.h"
#include <strings.h>

#define NOGYRTEMP

#define HEARTBEATLED 10
// SPI Defines
// We are going to use SPI 0, and allocate it to the following GPIO pins
// Pins can be changed, see the GPIO function select table in the datasheet for information on GPIO assignments

// I2C defines
// This example will use I2C0 on GPIO8 (SDA) and GPIO9 (SCL) running at 400KHz.
// Pins can be changed, see the GPIO function select table in the datasheet for information on GPIO assignments

typedef struct
{
    i2c_inst_t *handle;
    int adress;
} acc_handle;

int64_t alarm_callback(alarm_id_t id, void *user_data)
{
    // Put your timeout handler code in here
    return 0;
}

static int32_t platform_write(void *handle, uint8_t Reg, const uint8_t *Bufp, uint16_t len)
{
    // Il faut créer un buffer en plus qui pourra stocker l'adresse du registre de destination
    uint8_t newBuf[len + 1];
    newBuf[0] = Reg;
    for (char i = 0; i < len; i++)
    {
        newBuf[i + 1] = Bufp[i];
    }
    return i2c_write_blocking(((acc_handle *)handle)->handle, ((acc_handle *)handle)->adress, newBuf, len + 1, false);
    // return i2c_write_timeout_us(((acc_handle*)handle)->handle,((acc_handle*)handle)->adress,newBuf,len+1,false,100000);
}
static int32_t platform_read(void *handle, uint8_t Reg, uint8_t *Bufp, uint16_t len)
{

    i2c_write_blocking(((acc_handle *)handle)->handle, ((acc_handle *)handle)->adress, &Reg, 1, true);
    // i2c_write_timeout_us(((acc_handle*)handle)->handle,((acc_handle*)handle)->adress,&Reg,1,false,100000);
    int ret = i2c_read_blocking(((acc_handle *)handle)->handle, ((acc_handle *)handle)->adress, Bufp, len, false);
    // int ret=i2c_read_timeout_us(((acc_handle*)handle)->handle,((acc_handle*)handle)->adress,Bufp,len,false,100000);
    if (ret < len)
    {
        return PICO_ERROR_GENERIC;
    }
    return 0;
}

stmdev_ctx_t acc1;
stmdev_ctx_t acc2;

// Core 0 : sensor read/serial com/wifi?
// Core 1 : Motor control
acc_handle handle_bas{i2c0, 0x6B};
acc_handle handle_haut{i2c0, 0x6A};
static void platform_init(void)
{
    i2c_init(handle_bas.handle, 100000);
    i2c_init(handle_haut.handle, 100000);
    i2c_set_slave_mode(handle_haut.handle, false, 0);
    i2c_set_slave_mode(handle_bas.handle, false, 0);
    gpio_set_function(4, GPIO_FUNC_I2C);
    gpio_set_function(5, GPIO_FUNC_I2C);
}

void core1_entry()
{

    gpio_init(HEARTBEATLED);
    gpio_set_dir(HEARTBEATLED, 1);
    while (1)
    {
        
        gpio_put(HEARTBEATLED, 1);
        sleep_ms(500);
        gpio_put(HEARTBEATLED, 0);
        sleep_ms(300);
    }
}

typedef enum
{
    Start_Recording = 'S',
    Stop_Recording = 'T',
    Reset = 'R'

} Uart_Control;

void Accelerometer_Config(stmdev_ctx_t *acc)
{
    lsm6ds3tr_c_block_data_update_set(acc, PROPERTY_ENABLE);
    lsm6ds3tr_c_xl_data_rate_set(acc, LSM6DS3TR_C_XL_ODR_104Hz);
    lsm6ds3tr_c_gy_data_rate_set(acc, LSM6DS3TR_C_GY_ODR_12Hz5);

    lsm6ds3tr_c_xl_full_scale_set(acc, LSM6DS3TR_C_4g);
    lsm6ds3tr_c_gy_full_scale_set(acc, LSM6DS3TR_C_2000dps);

    lsm6ds3tr_c_xl_filter_analog_set(acc,
                                     LSM6DS3TR_C_XL_ANA_BW_400Hz);
    lsm6ds3tr_c_xl_lp2_bandwidth_set(acc,
                                     LSM6DS3TR_C_XL_LOW_NOISE_LP_ODR_DIV_100);
    lsm6ds3tr_c_gy_band_pass_set(acc,
                                 LSM6DS3TR_C_HP_260mHz_LP1_STRONG);
    lsm6ds3tr_c_xl_power_mode_set(acc, LSM6DS3TR_C_XL_HIGH_PERFORMANCE);
    lsm6ds3tr_c_gy_power_mode_set(acc, LSM6DS3TR_C_GY_HIGH_PERFORMANCE);
}

void Accelerometer_Sanity_Check(stmdev_ctx_t *acc1, stmdev_ctx_t *acc2)
{

    uint8_t whoami = 0;
    auto ret = lsm6ds3tr_c_device_id_get(acc1, &whoami);
    if (ret != 0)
    {
        printf("error = %x\n", ret);
    }
    if (whoami != 0x6a)
    {
        printf("lower sensor Error");
    }
    ret = lsm6ds3tr_c_device_id_get(acc2, &whoami);
    if (ret != 0)
    {
        printf("error = %x\n", ret);
    }
    if (whoami != 0x6a)
    {
        printf("upper sensor Error");
    }
}

bool CheckSensor(stmdev_ctx_t *acc, lsm6ds3tr_c_reg_t *reg, int16_t *raw_accel, float *acceleration_mg, int16_t *raw_gyro, float *angular_mdps, int16_t *raw_temp, float *temp)
{
    bool newData_flag = false;
    lsm6ds3tr_c_status_reg_get(acc, &(reg->status_reg));
    if (reg->status_reg.xlda)
    {
        newData_flag = true;
        memset(raw_accel, 0x00, 3 * sizeof(int16_t)); // on remet le tableau à 0
        lsm6ds3tr_c_acceleration_raw_get(acc, raw_accel);
        acceleration_mg[0] = lsm6ds3tr_c_from_fs4g_to_mg(
            raw_accel[0]);
        acceleration_mg[1] = lsm6ds3tr_c_from_fs4g_to_mg(
            raw_accel[1]);
        acceleration_mg[2] = lsm6ds3tr_c_from_fs4g_to_mg(
            raw_accel[2]);
    }
    #ifndef NOGYRTEMP
    if (reg->status_reg.gda)
    {
        newData_flag = true;
        memset(raw_gyro, 0x00, 3 * sizeof(int16_t));
        lsm6ds3tr_c_angular_rate_raw_get(acc, raw_gyro);
        angular_mdps[0] = lsm6ds3tr_c_from_fs2000dps_to_mdps(raw_gyro[0]);
        angular_mdps[1] = lsm6ds3tr_c_from_fs2000dps_to_mdps(raw_gyro[1]);
        angular_mdps[2] = lsm6ds3tr_c_from_fs2000dps_to_mdps(raw_gyro[2]);
    }
    if (reg->status_reg.tda)
    {
        // newData_flag = true;
        *raw_temp = 0;
        lsm6ds3tr_c_temperature_raw_get(acc, raw_temp);
        *temp = lsm6ds3tr_c_from_lsb_to_celsius(*raw_temp);
    }
    #endif
    return newData_flag;
}

int main()
{
    static int16_t raw_accel_1[3], raw_accel_2[3], raw_gyro_1[3], raw_gyro_2[3], raw_temp_1, raw_temp_2;
    static float acceleration_mg_1[3], acceleration_mg_2[3], angular_mdps_1[3], angular_mdps_2[3], temp_1, temp_2;
    uint8_t drdy = 0;
    int save_count = 0;
    bool Measuring = true;
    lsm6ds3tr_c_reg_t reg_1, reg_2; // registre des drapeaux

    stdio_init_all();
    platform_init();

    // UART
    gpio_set_function(0, GPIO_FUNC_UART);
    gpio_set_function(1, GPIO_FUNC_UART);
    uart_init(uart0, 115200);
    uart_set_fifo_enabled(uart0, 1);

    sleep_ms(5000);
    printf("start\n");
    acc1.write_reg = &platform_write;
    acc1.read_reg = &platform_read;
    acc1.handle = &handle_bas;

    acc2.write_reg = &platform_write;
    acc2.read_reg = &platform_read;
    acc2.handle = &handle_haut;

    gpio_init(17);
    gpio_put(17, 0);
    printf("log");
    logging log;
    char filename[100]; 
    char data[100]{"FRAMBOURT Mateis PSI*, BOCQUILLON NOE PSI*, 2023"};
    sprintf(filename, "copyright.txt");

    printf("opening the file : return %i\n", log.open_file(filename));
    printf("saving the file : return %i\n", log.save(data));
    printf("closing the file : return %i\n", log.close_file());
    sprintf(filename,"reading_");
    sprintf(filename, strcat(strcat(filename, __DATE__), ".csv"));
    // sprintf(filename+8,__DATE__);
    printf("opening the file : return %i\n", log.open_file(filename));
    log.save((char*)"----------------\n");

    // configure sensor
    Accelerometer_Sanity_Check(&acc1, &acc2);

    Accelerometer_Config(&acc1);
    Accelerometer_Config(&acc2);

    // Chip select is active-low, so we'll initialise it to a driven-high state

    // I2C Initialisation. Using it at 400Khz.

    // Interpolator example code
    // interp_config cfg = interp_default_config();
    // Now use the various interpolator library functions for your use case
    // e.g. interp_config_clamp(&cfg, true);
    //      interp_config_shift(&cfg, 2);
    // Then set the config
    // interp_set_config(interp0, 0, &cfg);

    // Timer example code - This example fires off the callback after 2000ms
    // add_alarm_in_ms(2000, alarm_callback, NULL, false);
    multicore_launch_core1(&core1_entry);

    printf("initialised\n");

    while (1)
    {
        if (Measuring)
        {
            bool newData_flag = CheckSensor(&acc1, &reg_1, raw_accel_1, acceleration_mg_1, raw_gyro_1, angular_mdps_1, &raw_temp_1, &temp_1);
            newData_flag |= CheckSensor(&acc2, &reg_2, raw_accel_2, acceleration_mg_2, raw_gyro_2, angular_mdps_2, &raw_temp_2, &temp_2);

            if (newData_flag)
            {
                char tx_buf[1000];
                memset(tx_buf, 0, 500);

                auto current_time = time_us_64();
                #ifndef NOGYRTEMP
                sprintf(tx_buf, "?%lld;%f;%f;%f;%f;%f;%f;%f;%f;%f;%f;%f;%f;%f;%f;\n", current_time, acceleration_mg_1[0], acceleration_mg_1[1], acceleration_mg_1[2], angular_mdps_1[0], angular_mdps_1[1], angular_mdps_1[2], temp_1, acceleration_mg_2[0], acceleration_mg_2[1], acceleration_mg_2[2], angular_mdps_2[0], angular_mdps_2[1], angular_mdps_2[2], temp_2);
                #else 
                sprintf(tx_buf,"?%lld;%.4f;%.4f;%.4f;%.4f;%.4f;%.4f;\n",current_time,acceleration_mg_1[0], acceleration_mg_1[1], acceleration_mg_1[2],acceleration_mg_2[0], acceleration_mg_2[1], acceleration_mg_2[2]);
                #endif
                printf(tx_buf);
                log.save(tx_buf);
                save_count++;
            }

            if (save_count >= 1000)
            {
                log.close_file();
                log.open_file(filename);
                save_count = 0;
            }
        }
        if (uart_is_readable(uart0))
        {
            uint8_t command;
            uart_read_blocking(uart0, &command, 1);
            switch ((char)command)
            {
            case Start_Recording:
                Measuring = 1;
                break;
            case Stop_Recording:
                Measuring = 0;
                break;
            case Reset:
                watchdog_enable(1, false);
                break;
            default:
                break;
            }
        }
    }
    return 0;
}

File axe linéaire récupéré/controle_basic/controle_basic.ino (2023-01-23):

#define Y1 10
#define Y2 9
#define ArrayLength 255

#include "sine.h"
const auto f = 2;
char offset = 40;
double T = (1/(f*2*ArrayLength))*1000000; //dt entre chaque valeur de l'array en us
void setup() {
  Serial.begin(115200);
  // put your setup code here, to run once:
pinMode(Y1,OUTPUT);
pinMode(Y2,OUTPUT);
pinMode(LED_BUILTIN,OUTPUT);
for (int i =0;i<3;i++) {
digitalWrite(LED_BUILTIN,HIGH);
delay(100);
digitalWrite(LED_BUILTIN,LOW);
delay(100);

}
Serial.println(T);
/*
digitalWrite(Y1,HIGH);
digitalWrite(Y2,LOW);
delay(500);
digitalWrite(Y1,LOW);*/
}
unsigned long lastMicros =micros();
int lastI=0;
int i =0;
void loop() {
  // put your main code here, to run repeatedly:
 /*digitalWrite(Y1, HIGH);
 digitalWrite(Y2, LOW);
 delay(1000);
 digitalWrite(Y1,LOW);
 digitalWrite(Y2,HIGH);
 delay(1000);*/ 
 if ((micros()-lastMicros)>T) {
   i++;
   
   lastMicros = micros();
   if (i>=2*ArrayLength) {
     i=0;
   }
 }
 if (lastI != i ) {
 unsigned char si = min(sinus[i%ArrayLength],255);//max(sinus[i%ArrayLength],offset); //min(sinus[i%ArrayLength]+offset,255);
 //Serial.println(si);
si = map(si, 0,255, 0,255-offset) + offset;
 if (i<ArrayLength) {
   analogWrite(Y1, si);
   digitalWrite(Y2,0);
   //Serial.println(si);
 }
 else {
   analogWrite(Y2,si);
   digitalWrite(Y1,0);
   //Serial.println(-si);
 }
 Serial.println(i);
 lastI= i;
 }
 delayMicroseconds(1);
  
 


}

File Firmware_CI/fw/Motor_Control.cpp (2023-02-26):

#include "Motor_Control.h"
#include "pico/stdlib.h"
#include "hardware/pwm.h"
#include "time.h"
Motor_Control::Motor_Control(int Pin_EN,int Pin_In1,int Pin_In2)
{
    int m_EN = Pin_EN;
    int m_In1 = Pin_In1;
    int m_In2 = Pin_In2;
    gpio_set_function(m_In1,GPIO_FUNC_PWM);
    gpio_set_function(m_In2,GPIO_FUNC_PWM);
    gpio_init(m_EN);
    gpio_pull_up(m_EN);
    gpio_pull_down(m_In1);
    gpio_pull_down(m_In2);
    m_channel_In1 = pwm_gpio_to_channel(m_In1);
    m_channel_In2 = pwm_gpio_to_channel(m_In2);
    m_slice_In1 = pwm_gpio_to_slice_num(m_In1);
    m_slice_In2 = pwm_gpio_to_slice_num(m_In2);
    //séléction de la fréquence : 10kHz 
    //on choisit le wrap le plus grand possible
    pwm_set_wrap(m_slice_In1,12500);
    pwm_set_wrap(m_slice_In2,12500);
    pwm_set_enabled(m_channel_In1,false);
    pwm_set_enabled(m_channel_In2,false); 

}

Motor_Control::~Motor_Control()
{

}

/* TRUTH TABLE
EN | IN1| IN2| OUT1   | OUT2
L  | X  | X  | High Z | High Z
H  | L  | L  | GND    | GND
H  | H  | L  | Vs     | GND
H  | L  | H  | GND    | Vs
H  | H  | H  | Vs     | Vs*/
int Motor_Control::setMotor(bool dir, uint16_t intensity)  {
    if (dir) {
        pwm_set_enabled(m_channel_In2,false);
        pwm_set_enabled(m_channel_In1,true);
        pwm_set_chan_level(m_slice_In1,m_channel_In1,intensity);
        pwm_set_chan_level(m_slice_In2,m_channel_In2,0);
    }
    else {
        pwm_set_enabled(m_channel_In1,false);
        pwm_set_enabled(m_channel_In2,true);
        pwm_set_chan_level(m_slice_In2,m_channel_In2,intensity);
        pwm_set_chan_level(m_slice_In1,m_channel_In1,0);
    }
    return 0;
}

int Motor_Control::stopMotor() {
    pwm_set_enabled(m_channel_In1,false);
    pwm_set_enabled(m_channel_In2,false);
    sleep_ms(250);
    gpio_put(m_EN,0);
    return 0;
}

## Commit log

2023-02-04 Début de la phase de prototipage du PCB (tout Début)
    [Axe_linéaire.kicad_pcb, Axe_linéaire.kicad_sch]
2023-02-05 Ajout de button et pico w
    [Axe_linéaire.kicad_sch, Connector.kicad_sch, Power.kicad_sch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]
2023-02-13 Ajout du transitor d'OR de l'alim
    [Axe_linéaire.kicad_sch, micro.kicad_sch]
2023-02-13 choix et création des Connector_FFC
    [Axe_linéaire.kicad_sch, micro.kicad_sch]
2023-02-13 Ajout des protections sur l'alimentation
    [Axe_linéaire.kicad_sch, Connector.kicad_sch, Power.kicad_sch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]
2023-02-14 Ajout de l'IMU + modèle du photointerrupteur
    [Axe_linéaire.kicad_sch, Power.kicad_sch, Sensor.kicad_sch]
2023-02-14 ajout du circuit de position + carte SD
    [Axe_linéaire.kicad_sch, Connector.kicad_sch, Sensor.kicad_sch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]
2023-02-14 Création du circuit imprimé
    [Axe_linéaire.kicad_pcb]
2023-02-14 circuit V1
    [Axe_linéaire-B_Cu.gbr, Axe_linéaire-B_Mask.gbr, Axe_linéaire-B_Paste.gbr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]
2023-02-16 1er circuit fini, schéma de la base fini
    [Axe_linéaire-B_Cu.gbl, Axe_linéaire-B_Mask.gbr, Axe_linéaire-B_Mask.gbs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]
2023-02-16 fin du circuit de base
    [base-B_Cu.gbl, base-B_Mask.gbs, base-B_Paste.gbp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]
2023-02-17 tout mes CI sont pret
    [Axe_linéaire-B_Cu.gbl, Axe_linéaire-B_Mask.gbs, Axe_linéaire-B_Paste.gbp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]
2023-02-21 circuit imprimé commandé
    [assemblage.kicad_pcb, bom.csv, positions.csv]
2023-02-25 Début de la librairie de controle moteur
2023-02-26 Finished motor control
2023-02-27 prototype PID
2023-02-28 PID complete
2023-03-01 fixed abs value for PID
    [fw.cpp]
2023-03-02 ajout des mesures
    [Accélération à vide .ods]
2023-03-05 assemblage et prise en photo du CI
    [haut.kicad_pcb, micro.kicad_sch]
2023-03-06 created i2c access
2023-03-06 Tested Sensor ==> Working :D
2023-03-07 added sensor readout
2023-03-08 Sensor readout optimization
    [Axe_linéaire.kicad_sch, Connector.kicad_sch, Power.kicad_sch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]
2023-03-11 fonction de base faite
2023-03-24 test traitement des données
    [0.3Hz.csv, 0.3Hz_Cleaned.csv, 0.5Hz.csv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]
2023-03-30 Mesure, pb spin
    [0.5 hz.csv, 0.5hz bis.csv, 0.5hz.csv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]
2023-04-06 Mesure multiple
    [0.3Hz_Cleaned.csv, 0.5 Hz.csv, 0.5 hz.csv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]
2023-04-28 Automatisation diagramme de Bode
    [Bode a vide.csv]
2023-05-05 Traitement de toute les mesures à l'heure actuelle
2023-05-05 traité tout
    [0.5 Hz.csv, 0.5 hz.csv, 0.5Hz.csv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]
2023-05-15 Mesure très faible amplitude
    [0.5 Hz.csv, 0.5 hz.csv, 0.5Hz.csv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]
2023-05-16 mesure tres faible ampitude finie
    [0.5hz.csv, 1.5hz.csv, 1.8hz.csv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]
2023-05-16 mesures avec masse de 73g
    [0.5 hz.csv, 1.5 hz.csv, 1.5hz.csv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]
2023-05-21 Tri photo
    [baguette v2.SLDPRT, coup de vent.csv, masse en bas (9.4gcm) de 100g.csv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]
2023-05-22 TIPE quasi préparé
    [100g 3cm de l'axe.csv]
2023-05-30 schéma
    [0.5 hz.csv, 0.5hz.csv, 0.6hz.csv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]
2023-06-02 Passage ENS
    [base.kicad_sch]
